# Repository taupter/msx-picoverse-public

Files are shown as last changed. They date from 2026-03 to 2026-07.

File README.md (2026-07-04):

# PicoVerse for MSX

**The MSX experience driven by the Raspberry Pi Pico family of microcontrollers.**

PicoVerse is a community-driven effort to build versatile MSX cartridges powered by Raspberry Pi Pico development boards. The project pairs accessible hardware designs with ready-to-flash firmware so MSX users can jump straight into loading games, tools, and Nextor without having to compile sources.

| Cartridge Label - 2040 Variant | Cartridge Label - 2350 Variant |
|---|---|
|PicoVerse 2040 Label | PicoVerse 2350 Label |

PicoVerse is designed as an open-source, independent, and documented MSX cartridge platform. Compatibility with other projects is neither a goal nor guaranteed (I tested some without much success); running third‑party software on PicoVerse hardware, or PicoVerse firmware on other boards, is at your own risk. The source and manufacturing files are openly available so you can learn, experiment, and build on them for the MSX community, subject to the project license.

If you find any issues, have questions, or want to contribute, please open an issue or reach out via the contact information in the repository.

## Project Highlights

- Single-ROM LoadROM workflow for instant and easy booting of one title.
- Multi-ROM loader with an on-screen menu and mapper auto-detection.
- Explorer firmware (PicoVerse 2350) merges flash ROMs, optional embedded Sunrise Nextor SYSTEM entries, and microSD ROMs, labels the source (FL/SD), adds microSD MP3/WAV playback, supports WAVEGAME microSD ROMs with port `0x92` controlled WAV streaming, supports on-device search, can cycle supported microSD partitions with `P`, can delete selected SD files with confirmed `D`, includes ROM detail audio profiles with native and external SCC/SCC+, Dual PSG, MSX-MUSIC, and YM2151/SFG support, adds an independent primary PSG DAC mirror option, and includes an integrated File Hunter browser for downloading ROMs over ESP-01 WiFi.
- Ready-made Nextor builds with USB pendrive (`-s2`/`-m2`) or FAT16 up-to-4GB microSD partitions (`-s1`/`-m1`) via Sunrise IDE emulation on PicoVerse 2350, and USB (`-s`/`-m`) on PicoVerse 2040.
- Sunrise IDE + 192KB memory mapper on PicoVerse 2040 (`loadrom.exe -m`), or Sunrise IDE standalone (`loadrom.exe -s`).
- Sunrise IDE + 1MB PSRAM memory mapper on PicoVerse 2350 (`loadrom.exe -m1` for microSD, `loadrom.exe -m2` for USB), or Sunrise IDE standalone (`loadrom.exe -s1` / `loadrom.exe -s2`).
- Sunrise IDE + 1MB memory mapper + 1MB MegaRAM on PicoVerse 2350 (`loadrom.exe -r1` / `explorer.exe -r1` for microSD, `loadrom.exe -r2` / `explorer.exe -r2` for USB), exposing 128 × 8KB MegaRAM banks in a dedicated expanded subslot.
- Carnivore2-compatible RAM-mode loader on PicoVerse 2350 (`loadrom.exe -c1` / `loadrom.exe -c2`) for `SROM.COM /D15` uploads into the 1MB PSRAM mapper.
- ESP-01 WiFi support for PicoVerse 2350 Sunrise IDE LoadROM/MultiROM builds (`loadrom.exe -s1 -w`, `-m1 -w`, `-s2 -w`, `-m2 -w`) and for the Explorer File Hunter browser. Compatible with both real MSX hardware and FPGA-based MSX cores.
- SCC/SCC+, Dual PSG, MSX-MUSIC/YM2413, and YM2151/SFG emulation on the PicoVerse 2350, with per-ROM audio profile selection where supported.
- Yamanooto flash-cartridge emulation on the PicoVerse 2350 (`yamanooto.exe`) — a Konami-SCC compatible 8 MB flash cartridge with SCC/SCC+, a secondary (dual) PSG, a primary PSG mirror, and MSX-MUSIC/FM-PAC, all always available with the firmware selecting SCC, FM, or pure PSG on the fly so one image can mix SCC, FM, and PSG games.
- PC-side tooling that generates UF2 images locally for quick drag-and-drop flashing.
- USB keyboard support on PicoVerse 2040 — use a standard USB keyboard as the MSX keyboard via the cartridge slot.
- MSX-MIDI support on PicoVerse 2040 — use a USB-MIDI cable as a standard MSX-MIDI interface via the cartridge slot. 
- MIDI-PAC support on PicoVerse 2040 — passively convert live MSX PSG music and effects into high-quality MIDI for external synths or sound modules (SC-55 optimized). Features automatic bass detection, tone+noise coexistence, smooth pitch bending on fast passages, and improved percussion mapping. 
- USB joystick support on PicoVerse 2040 — plug a standard USB gamepad (HID, Xbox 360, Xbox One, or Xbox Series X|S) into the USB-C port and it appears as one or two native MSX joysticks with no MSX-side software needed. Uses open-drain bus driving to coexist with the real PSG.
- BOMs, and production-ready Gerbers.
- Active development roadmap covering RP2040 and RP2350-based cartridges.

## Documentation

**LoadROM Guides:** Use the LoadROM tool to create a UF2 image that boots directly into a single ROM, skipping the menu. Mapper type is auto-detected with filename tag overrides, and the tool reports the detected configuration before flashing.
- [MSX PicoVerse 2040 LoadROM Tool Manual (English)](/docs/msx-picoverse-2040-loadrom-tool-manual.en-us.md) 
- [MSX PicoVerse 2350 LoadROM Tool Manual (English)](/docs/msx-picoverse-2350-loadrom-tool-manual.en-us.md) 
  
**MultiROM Guides:** Use the MultiROM tool to create a UF2 image that allows selecting from multiple ROMs at boot. Mapper type is auto-detected with filename tag overrides, and the tool reports the detected configuration before flashing.
- [PicoVerse 2040 MultiROM Guide Manual (English)](/docs/msx-picoverse-2040-multirom-tool-manual.en-us.md)
- [PicoVerse 2350 MultiROM Tool Manual (English)](/docs/msx-picoverse-2350-multirom-tool-manual.en-us.md)

**Explorer Guides:** Use the Explorer tool to manage flash, embedded Sunrise Nextor, and microSD ROMs, cycle supported microSD partitions, delete selected SD files, play MP3/WAV files from the microSD card, browse File Hunter over ESP-01 WiFi, select ROM audio/PSG options, and search for titles on the device.
- [MSX PicoVerse 2350 Explorer Tool Manual (English)](/docs/msx-picoverse-2350-explorer-tool-manual.en-us.md)

**Yamanooto Guides:** Use the Yamanooto tool to create a UF2 that emulates a Yamanooto flash cartridge (Konami-SCC compatible, SCC/SCC+, dual PSG, primary PSG mirror, and MSX-MUSIC/FM-PAC) from a single ROM image, with the firmware choosing SCC/FM/PSG automatically at runtime.
- [MSX PicoVerse 2350 Yamanooto Tool Manual (English)](/docs/msx-picoverse-2350-yamanooto-tool-manual.en-us.md)

**Reference Material** 
- [PicoVerse 2040 Features Overview](/docs/msx-picoverse-2040-features.md)
- [PicoVerse 2350 Features Overview](/docs/msx-picoverse-2350-features.md)
- [MSX PicoVerse 2350 Dual PSG Implementation](/docs/msx-picoverse-2350-dualpsg.md)
- [MSX PicoVerse 2350 MSX-MUSIC/FM-PAC Implementation](/docs/msx-picoverse-2350-fmpac.md)
- [MSX PicoVerse 2350 Yamanooto Implementation](/docs/msx-picoverse-2350-yamanooto.md)
- [MSX PicoVerse 2350 MegaRAM Implementation](/docs/msx-picoverse-2350-megaram.md)
- [MSX PicoVerse 2350 WAVEGAME Protocol and Support](/docs/msx-picoverse-2350-wavegame.md)
- [MSX PicoVerse 2350 WiFi Support](/docs/msx-picoverse-2350-wifi.md)
- [MSX PicoVerse 2040 PIO Strategy](/docs/msx-picoverse-2040-pio.md) 
- [MSX PicoVerse 2350 PIO Strategy](/docs/msx-picoverse-2350-pio.md) 
- [MSX PicoVerse 2350 SCC Emulation](/docs/msx-picoverse-2350-scc.md)
- [MSX PicoVerse 2040 Sunrise IDE Emulation for Nextor](/docs/msx-picoverse-2040-sunrise-nextor.md) 
- [MSX PicoVerse 2350 Sunrise IDE Emulation for Nextor](/docs/msx-picoverse-2350-sunrise-nextor.md) 
- [MSX PicoVerse 2040 Mapper Implementation (Sunrise + Nextor)](/docs/msx-picoverse-2040-mapper.md) 
- [MSX PicoVerse 2040 USB Keyboard](/docs/msx-picoverse-2040-keyboard.md)
- [MSX PicoVerse 2040 MSX-MIDI](/docs/msx-picoverse-2040-msx-midi.md) 
- [MSX PicoVerse 2040 MIDI-PAC](/docs/msx-picoverse-2040-midipac.md)
- [MSX PicoVerse 2040 MegaROMs](/docs/msx-picoverse-2040-megaroms.md)
- [MSX PicoVerse 2040 USB Joystick](/docs/msx-picoverse-2040-joystick.md)

## Hardware Variants

### PicoVerse 2040 Cartridge

| Prototype PCB (front) | Prototype PCB (back) |
|---|---|
|  |  | 

- Based on RP2040 boards exposing 30 GPIO pins (not compatible with stock Raspberry Pi Pico pinout).
- Up to 16 MB of flash for MSX ROMs with support for Plain16/32 (`PLA-16`/`PLA-32`), Planar48/64 (`PLN-48`/`PLN-64`), Konami SCC, Konami, ASCII8/16/16X, NEO-8, NEO-16, and Manbow2 (`MANBW2`) mappers.
- USB-C port doubles as a bridge for Nextor mass storage via Sunrise IDE emulation (`loadrom.exe -s`).
- Sunrise IDE + 192KB memory mapper mode provides both Nextor disk access and expanded RAM (`loadrom.exe -m`).
- Standalone USB keyboard firmware — use a standard USB keyboard as the MSX keyboard via the cartridge slot (`loadrom.exe -k`). Not compatible with FPGA-based MSX systems or MSX computers with an integrated PPI (e.g. T9769 MSX-ENGINE).
- Standalone MSX-MIDI firmware — use a USB-MIDI cable as a standard MSX-MIDI interface for MIDI players and sequencers (`loadrom.exe -i`).
- Standalone MIDI-PAC firmware — passively listen to the MSX PSG and convert music and effects to USB MIDI for an external synth or sound module (`loadrom.exe -p`).
- Standalone USB joystick firmware — use a standard USB gamepad as an MSX joystick via the cartridge slot (`loadrom.exe -j`). Supports Xbox 360, Xbox One, Xbox Series X|S, and generic USB HID gamepads, with up to 2 gamepads mapped to MSX joystick ports 1 and 2.  Not compatible with FPGA-based MSX systems or MSX computers with an integrated PSG (e.g. T9769 MSX-ENGINE).

#### Bill of Materials

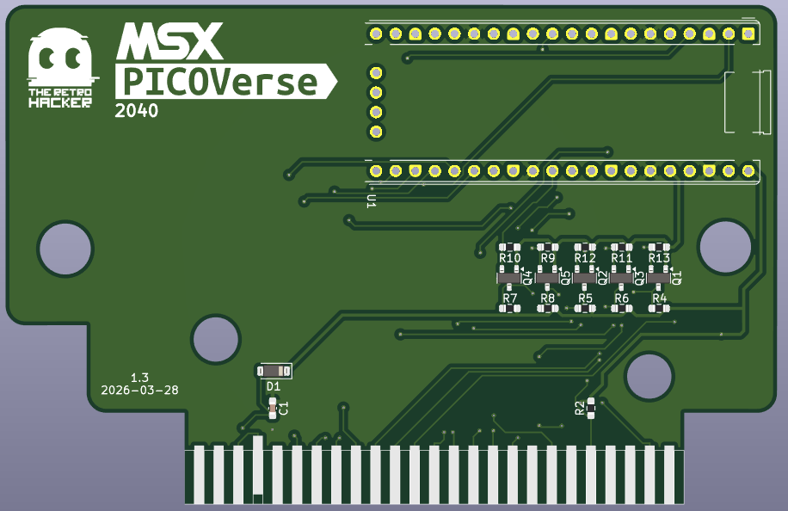
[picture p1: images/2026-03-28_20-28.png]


Interactive BOM available at [PicoVerse 2040 BOM](https://htmlpreview.github.io/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)

| Reference | Description | Quantity | Link |
| --- | --- | --- | --- |
| U1 | RP2040 Dev Board 30 GPIO pins exposed | 1 | [AliExpress](https://s.click.aliexpress.com/e/_c4MuM9st) |
| C1 | 0603 0.1 µF Ceramic Capacitor | 1 | [AliExpress](https://s.click.aliexpress.com/e/_c2w5e36V) |
| C2 | 0603 10 µF Ceramic Capacitor | 1 | [AliExpress](https://s.click.aliexpress.com/e/_c2w5e36V)|
| R2, R3, R4, R5, R6, R7, R8, R9, R10, R11, R12, R13| 0603 10 kΩ Resistor | 12 | [AliExpress](https://s.click.aliexpress.com/e/_c3XBv4od)|
| R1 | 0603 2 KΩ Resistor | 1 | [AliExpress](https://s.click.aliexpress.com/e/_c3XBv4od)|
| D1 | 1N5819 SOD-123 Diode | 1 | [AliExpress](https://s.click.aliexpress.com/e/_c4WEKCuz) |
| Q1, Q2, Q3, Q4, Q5 | BSS138 SOT-23 Transistor | 5 | [AliExpress](https://s.click.aliexpress.com/e/_c2veWxcD)|

### PicoVerse 2350 Cartridge

| Prototype PCB (front) | Prototype PCB (back) |
|---|---|
|  |  |

- Targets RP2350 boards exposing all 48 GPIO pins (not compatible with standard Pico 2 boards).
- Adds microSD storage, ESP8266 WiFi header, and I2S audio expansion alongside 16 MB flash space.
- Extra RAM (PSRAM) now backs the 1MB mapper modes and the Carnivore2-compatible RAM loader, with room for additional advanced firmware features.
- Explorer firmware can load ROMs from flash, optional embedded Sunrise Nextor SYSTEM entries, and microSD, cycle FAT16/FAT32/exFAT microSD browsing partitions with `P`, delete selected SD files after confirmation with `D`, play MP3/WAV files from microSD, browse File Hunter over ESP-01 WiFi, save downloaded File Hunter ROMs to the microSD root, search local title lists, select native or external SCC/SCC+, Dual PSG, MSX-MUSIC, or YM2151/SFG audio profiles per ROM where supported, and optionally mirror primary PSG audio through the cartridge DAC.
- USB-C port doubles as a bridge for Nextor mass storage via Sunrise IDE emulation (`-s2`).
- microSD card slot provides Nextor mass storage via Sunrise IDE emulation (`-s1`) when using FAT16 partitions up to 4 GB.
- Sunrise IDE + 1MB PSRAM memory mapper mode provides both Nextor disk access and expanded RAM (`-m1` for microSD, `-m2` for USB).
- Sunrise IDE + 1MB mapper + 1MB MegaRAM mode provides Nextor disk access, standard mapper RAM, and a separate writable MegaRAM cartridge surface (`-r1` for microSD, `-r2` for USB).
- Carnivore2-compatible RAM-mode loading lets `SROM.COM /D15` upload ROMs into the 1MB PSRAM mapper (`-c1` for microSD, `-c2` for USB).
- Yamanooto flash-cartridge emulation (`yamanooto.exe`) reproduces the  Yamanooto: a Konami-SCC compatible 8 MB flash cartridge with SCC/SCC+, a secondary (dual) PSG on ports `0x10`/`0x11`, a primary PSG mirror (`0xA0`/`0xA1`), and MSX-MUSIC/FM-PAC via an expanded subslot. All engines are always available and the firmware selects SCC, FM, or pure PSG on the fly, so a single image can hold a mix of SCC, FM, and PSG games.
- LoadROM Sunrise builds can also expose ESP-01 WiFi support with `-w` on top of the `-s1`/`-m1`/`-s2`/`-m2` modes.
- LoadROM, MultiROM, and Explorer support the Sunrise IDE options. MultiROM and Explorer allow combining them so multiple Nextor modes appear as selectable SYSTEM entries in the menu; Explorer also provides `-a` / `--allnextor` to add all embedded Nextor entries while still appending folder ROMs.
- Shares the same ROM mapper support list as the 2040 build.

#### Bill of Materials



Interactive BOM available at [PicoVerse 2350 BOM](https://htmlpreview.github.io/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) 

| Reference | Description | Quantity | Link |
| --- | --- | --- | --- |
| U1 | WaveShare Core2350B Dev Board 48 GPIO pins exposed (8Mb PSRAM)| 1 | [AliExpress](https://pt.aliexpress.com/item/1005009578742534.html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) |
|U2| UDA1334A I2S Stereo DAC| 1 | [AliExpress](https://s.click.aliexpress.com/e/_c3gam5lH) |
|U3| ESP-01 ESP8266 WiFi Module| 1 | [AliExpress](https://s.click.aliexpress.com/e/_c4a5rnGj) |
|C1| 0603 0.1 µF Ceramic Capacitor | 1 | [AliExpress](https://s.click.aliexpress.com/e/_c3tkUxHz) |
|C2,C3| 0603 10 µF Ceramic Capacitor | 2 | [AliExpress](https://s.click.aliexpress.com/e/_c3tkUxHz)|
|R1| 0603 2 KΩ Resistor | 1 | [AliExpress](https://s.click.aliexpress.com/e/_c43uKcEj)|
|R2, R3, R6, R7, R8| 0603 10 kΩ Resistor | 4 | [AliExpress](https://s.click.aliexpress.com/e/_c43uKcEj)|
|R4, R5| 0603 5.1 kΩ Resistor | 2 | [AliExpress](https://s.click.aliexpress.com/e/_c43uKcEj)|
|R9, R10| 0603 330 Ω Resistor | 2 | [AliExpress](https://s.click.aliexpress.com/e/_c43uKcEj)|
|D1| 1N5819 SOD-123 Diode | 1 | [AliExpress](https://s.click.aliexpress.com/e/_c4WEKCuz) |
|SW1| Tactile Push Button Switch | 1 | [AliExpress](https://s.click.aliexpress.com/e/_c2IPGkzv) |
|J1| USB-C 16 Pin Connector | 1 | [AliExpress](https://s.click.aliexpress.com/e/_c4PtBc51) |
|J2| microSD Card Slot | 1 | [AliExpress](https://s.click.aliexpress.com/e/_c4Pzbd7Z) |

## Repository Contents
- `hardware/` – Production-ready Gerbers, fabrication notes, and BOMs for each supported dev board.
- `software/` – MultiROM PC utilities (`multirom.exe`) and menu ROM assets for both cartridge families.
- `docs/` – Feature lists, usage walkthroughs, and revision history for each cartridge family.
- `images/` – Board renders and build photos for quick identification.
- `labels/` – Printable Patola style cartridge label designs for both hardware variants.

## Quick Start
1. **Pick your target board**: Select the hardware revision that matches the RP2040 or RP2350 carrier you own, then grab the corresponding Gerber/BOM pack.
2. **Manufacture or assemble**: Send the Gerbers to your PCB house or build from an ordered kit. Follow the assembly notes included in each hardware bundle.
3. **Generate the UF2 image**:
   - For multiple titles, place your `.rom` files beside the MultiROM tool for your cartridge family (`2040/software/multirom.pio/tool/multirom.exe` or `2350/software/multirom.pio/tool/multirom.exe`) and run `multirom.exe` to create `multirom.uf2`.
   - For an instant boot into a single game, place the desired `.rom` next to the LoadROM tool for your cartridge family and run `loadrom.exe <file> [-o custom.uf2]` to create a dedicated UF2 that skips the menu.
   - For a combined flash + microSD menu (on PicoVerse 2350 only), use the Explorer tool (`2350/software/explorer.pio/tool/explorer.exe`) to create `explorer.uf2`. Add options such as `-s1`, `-m1`, `-r1`, `-s2`, `-m2`, `-r2`, or `-a` / `--allnextor` when you want embedded Nextor SYSTEM entries in the same Explorer menu, then copy extra `.rom` and `.mp3` files to the microSD card. With an ESP-01 module and configured WiFi, Explorer can also browse File Hunter and save downloaded ROMs directly to the microSD root.
4. **Flash the firmware**:
   - Hold BOOTSEL while connecting the cartridge to your PC via USB-C.
   - Copy the freshly generated UF2 (`multirom.uf2`, `loadrom.uf2`, or `explorer.uf2`) to the RPI-RP2 drive that appears.
   - Eject the drive; the board reboots and stores the image in flash.
5. **Enjoy on MSX**: Insert the cartridge, power on the computer, pick a ROM from the menu, or launch Nextor to access USB or microSD storage.

## MultiROM Menu

| PicoVerse 2040 MultiRom | PicoVerse 2350 MultiRom |
|---|---|
|PicoVerse 2040 MultiROM menu|PicoVerse 2350 MultiROM menu|

To use the MultiROM menu, insert the PicoVerse cartridge into your MSX and power it on. The system will boot directly into the MultiROM menu, which displays a list of all ROMs embedded in the cartridge. Each entry is named after the ROM filename (up to 50 characters), and longer names are shown using a scrolling effect.

Navigate the menu using the keyboard arrow keys. Use the Up and Down keys to move through the list of ROMs, and if more than 19 ROMs are present, use the Left and Right keys to switch between pages. To start a game or application, select it and press Enter or Space; the MSX will boot the ROM using the appropriate mapper configuration automatically.

While in the menu, pressing the H key opens a help screen with basic instructions; press any key to return to the main menu. Once a ROM is launched, control is handed over entirely to the selected software, just as if it were a physical cartridge inserted into the MSX.

Check the detailed MultiROM guide in the documentation folder for advanced features, troubleshooting tips, and mapper support details.

## LoadROM Tool

The LoadROM tool targets situations where you want the PicoVerse to behave like a traditional single-game cartridge or as a dedicated standalone firmware image. Instead of showing the MultiROM menu, the Pico boots straight into one ROM embedded in the UF2 image, or into a selected standalone mode such as keyboard, MSX-MIDI, MIDI-PAC, or USB joystick.

- **Input**: exactly one `.ROM` file. Mapper type is auto-detected with the same heuristics as MultiROM, and you can still force a mapper via filename tags such as `.KonSCC.ROM` or `.PLA-32.ROM`.
- **Output**: `loadrom.uf2` by default, or any filename you pass via `-o`. The UF2 contains the firmware, a 59-byte configuration record (title, mapper, size, flash offset), and the ROM payload.
- **Workflow**:
   1. Open a Command Prompt or PowerShell window in your target package folder:
      - `2040/software/loadrom.pio/tool`, or
      - `2350/software/loadrom.pio/tool`.
   2. Run `loadrom.exe -o mygame.uf2 \\path\\to\\Game.ROM` (the tool also accepts drag-and-drop onto the EXE).
      - MSX-MIDI standalone mode: `loadrom.exe -i -o midi.uf2`
      - MIDI-PAC standalone mode: `loadrom.exe -p -o midipac.uf2`
      - USB joystick standalone mode: `loadrom.exe -j -o joystick.uf2`
      - SCC standard emulation (only PicoVerse 2350): `loadrom.exe -scc \\path\\to\\Game.ROM`
      - SCC+ enhanced emulation (only PicoVerse 2350): `loadrom.exe -sccplus \\path\\to\\Game.ROM`
      - MSX-MUSIC/FM-PAC emulation with the bundled English FM-PAC BIOS (only PicoVerse 2350, non-SYSTEM ROMs): `loadrom.exe -f \\path\\to\\Game.ROM`, `loadrom.exe -fmpac \\path\\to\\Game.ROM`, or `loadrom.exe --fmpac -o mygame-fmpac.uf2 \\path\\to\\Game.ROM`
      - Dual PSG emulation on secondary PSG ports `0x10`/`0x11` (only PicoVerse 2350, supported non-SYSTEM ROMs): `loadrom.exe -d \\path\\to\\Game.ROM` or `loadrom.exe --dual-psg -o mygame-dualpsg.uf2 \\path\\to\\Game.ROM`
      - `-scc` and `-sccplus` are mutually exclusive.
      - `-scc`, `-sccplus`, `-f` / `-fmpac`, and `-d` / `--dual-psg` are cartridge audio modes; use only one of them per UF2.
      - `-f` / `-fmpac` is not valid with Sunrise, Carnivore2, or MegaRAM system modes (`-s1`, `-m1`, `-s2`, `-m2`, `-c1`, `-c2`, `-r1`, or `-r2`) or with Konami SCC / Manbow2 mapper ROMs.
      - `-d` / `--dual-psg` is intended for software that writes to a second PSG. It is not available for Konami SCC or Manbow2 mapper ROMs, SCC/SCC+ audio builds, Sunrise/Nextor system modes, Carnivore2 system modes, or MegaRAM system modes.
      - Sunrise IDE standalone (PicoVerse 2040): `loadrom.exe -s`
      - Sunrise IDE + 192KB mapper (PicoVerse 2040): `loadrom.exe -m`
      - Sunrise IDE standalone (PicoVerse 2350): `loadrom.exe -s1` or `loadrom.exe -s2`
      - Sunrise IDE + 1MB PSRAM mapper (PicoVerse 2350): `loadrom.exe -m1` or `loadrom.exe -m2`
      - Sunrise IDE + 1MB PSRAM mapper + 1MB MegaRAM (PicoVerse 2350): `loadrom.exe -r1` or `loadrom.exe -r2`
      - Sunrise IDE + WiFi (PicoVerse 2350): `loadrom.exe -s1 -w`, `loadrom.exe -s2 -w`, `loadrom.exe -m1 -w`, or `loadrom.exe -m2 -w`
      - Carnivore2-compatible RAM loader (PicoVerse 2350): `loadrom.exe -c1` or `loadrom.exe -c2`
      - `-w` is currently supported only with `-s1`, `-m1`, `-s2`, or `-m2`.
   3. Observe the reported ROM name, size, mapper status (auto vs forced), and Pico offset before the UF2 is written.
   4. Put the Pico into BOOTSEL mode and copy the generated UF2 to the `RPI-RP2` drive.
   5. Insert the cartridge into your MSX—on power-up the embedded game launches immediately.

Consult the LoadROM manuals linked above for screenshots, troubleshooting, and in-depth explanations of mapper forcing, UF2 structure, and limitations.

## Explorer Firmware (RP2350)

|Explorer Flash Menu|Explorer MicroSD Menu|
|---|---|
|Explorer flash menu|Explorer microSD menu|
|<center>**File Hunter Explorer Menu**|<center>**WiFi Configuration Screen**|
|File Hunter Explorer menu|WiFi configuration screen|

Explorer is a PicoVerse 2350-only firmware that merges ROMs stored in flash, optional embedded Sunrise Nextor SYSTEM entries, and additional ROMs and MP3/WAV files on the microSD card. ROMs are labeled with source tags (FL/SD), MP3 and WAV entries open a player screen with Play/Stop and Pause/Resume controls, the list supports paging, and you can search by name directly in the menu. Explorer can add individual Nextor entries with `-s1`, `-m1`, `-c1`, `-r1`, `-s2`, `-m2`, `-c2`, or `-r2`, or add all of them with `-a` / `--allnextor`, while still appending supported folder ROMs to the UF2. In the `F2` microSD screen, `P` cycles supported FAT16, FAT32, and exFAT browsing partitions, while `D` deletes the selected file after confirmation; folders are protected. With an ESP-01 / ESP8266 module installed and WiFi configured, pressing `F3` opens the integrated File Hunter browser. File Hunter results show the ROM name and size, can be searched from the MSX, and selected ROMs are downloaded through the Pico into PSRAM before being saved as `.ROM` files in the microSD root. microSD ROMs up to 4 MB can be executed directly from there. Use the Explorer tool to build the UF2 and copy extra ROMs and audio files to the microSD card. See the Explorer manual for limits, File Hunter requirements, and supported formats.

For Sunrise Nextor SYSTEM entries in Explorer, SD storage is limited to FAT16 microSD partitions up to 4 GB. If more than one compatible partition exists, choose the desired one from the ROM detail screen's `SD Part` option; Explorer saves that selection in the ROM's `.PVC` options file. FAT32 and exFAT partitions remain supported for normal Explorer file browsing but are not offered to Nextor.

You can have up to 1024 entries per folder view (folders + ROMs + MP3s; the root view can also include flash entries). The menu auto-detects whether the MSX supports 80-column text mode and boots accordingly; you can also press `C` at any time to toggle between 40- and 80-column layouts.

Explorer ROM entries open a detail screen where you can inspect mapper detection, choose a cartridge audio profile, and toggle **PSG** mirroring. Konami SCC and Manbow2 ROMs can use SCC/SCC+ profiles. For other supported non-SYSTEM ROMs, select **Dual PSG** to enable the second cartridge-side PSG on ports `0x10` and `0x11`, **MSX-MUSIC** to enable YM2413/FM-PAC audio, external **SCC/SCC+** to expose a virtual SCC cartridge in another subslot, or **YM2151 (SFG05/SFG01)** to expose a virtual Yamaha SFG-style YM2151 cartridge in a secondary subslot while the game mapper remains active. Supported Sunrise Nextor SYSTEM entries can also select external **SCC/SCC+** or **YM2151 (SFG05/SFG01)**; Explorer keeps Nextor storage and mapper RAM availability intact and places the added cartridge surface in a free expanded subslot. MegaRAM Nextor entries reserve their expanded layout for Nextor, mapper RAM, and MegaRAM, so PSG Mirror, MSX-MUSIC, WiFi, and external audio profiles are not offered for those entries. Set **PSG: Yes** to also mirror the normal primary PSG ports `0xA0`/`0xA1` through the cartridge DAC; this primary PSG mirror can be mixed with SCC/SCC+, Dual PSG, MSX-MUSIC, YM2151/SFG, or WAVEGAME WAV playback. When **Dual PSG** and **PSG: Yes** are enabled together, Explorer routes Dual PSG to the left channel and the mirrored primary PSG to the right channel. Explorer hides cartridge audio profiles where the cartridge audio slot is reserved, including folders and File Hunter folder records.

WAVEGAME support is available for microSD-launched game ROMs that keep their audio sidecars in the same folder. The running MSX game writes one-byte commands to I/O port `0x92`; Explorer captures those writes while serving the ROM and streams `NN.wav`, `multi.wav`, or `pause.wav` files from the microSD card through the I2S DAC. The protocol supports stop/fade-out, play once, loop, pause toggle, pause music, previous-song resume with fade-in, deferred next-command playback, optional per-song `.cfg` sample offsets, and `multi.wav` fallback offsets. WAVEGAME titles should use 48 kHz mono 16-bit PCM WAV files. When Explorer detects WAVEGAME sidecars next to a ROM, cartridge audio profiles are forced to `None` because they are incompatible with the WAVEGAME streaming path; the separate **PSG Mirror** option remains available and is mixed into the WAVEGAME WAV output.

A search function is available by pressing `/` in the menu. Type part of a ROM name and press Enter to jump to the first matching entry. Press `H` to view the help screen.

The File Hunter browser was implemented with reference to NataliaPC's public MSX File Hunter Browser project: https://github.com/nataliapc/msx_filehunterbrowser

## Compatibility & Requirements

- Works with MSX, MSX2, MSX2+, and MSX TurboR systems. Mapper support covers the most common game and utility formats.
- Requires Windows OS to run the PC-side UF2 builder utilities.
- Ensure your development board matches the pinout documented for each hardware revision before soldering.

## License, Copyright notes & Usage

Creative Commons Attribution-NonCommercial-ShareAlike 4.0

All hardware and firmware binaries in this repository are released under the Creative Commons Attribution-NonCommercial-ShareAlike 4.0 International license. Personal builds and community tinkering are encouraged, but **commercial use or resale requires explicit authorization from the author**.

**bios.h** is used on all MSX menus and was adapted from http://www.konamiman.com/msx/msx2th/th-ap.txt by Danilo Angelo, 2020. The original file is licensed under CC0 1.0 Universal (public domain). The adapted bios.h file in this repository is also released under CC0 1.0 Universal, allowing for free use and modification without restrictions.

**msxromcrt0.s** is used on Nextor C implementation and was adapted by S0urceror, 2022, from the crt0.s file available in FusionC v2.0. The original crt0.s file is licensed under the MIT License. The adapted msxromcrt0.s file in this repository is also released under the MIT License, permitting free use, modification, and distribution with proper attribution.

**uf2format.h** is used in all UF2 builder tools and was adapted from the UF2 specification and reference implementation available at https://github.com/Microsoft/uf2/blob/master/uf2.h. The original uf2.h is copyright by Microsoft Corp and the file is licensed under the MIT License. The adapted uf2format.h file in this repository is also released under the MIT License, allowing for free use, modification, and distribution with proper attribution.

**emu2212.c** and **emu2212.h** used to implement SCC and SCC+ emulation are copyright by Mitsutaka Okazaki 2014 and licensed under the MIT License, allowing for free use, modification, and distribution with proper attribution. [emu2212 @ Digital Sound Antiques](https://github.com/digital-sound-antiques/emu2212)

**emu2149.c** and **emu2149.h** used to implement AY-3-8910 emulation/dual PSG feature are copyright by Mitsutaka Okazaki 2014 and licensed under the MIT License, allowing for free use, modification, and distribution with proper attribution. [emu2149 @ Digital Sound Antiques](https://github.com/digital-sound-antiques/emu2149)

**emu2413.c** and **emu2413.h** used to implement YM2413 / MSX-MUSIC emulation are copyright by Mitsutaka Okazaki 2020 and licensed under the MIT License, allowing for free use, modification, and distribution with proper attribution. [emu2413 @ Digital Sound Antiques](https://github.com/digital-sound-antiques/emu2413)

**The YM2151 / Yamaha SFG audio backend** uses the `ymfm` Yamaha FM sound cores by Aaron Giles, licensed under the BSD 3-Clause License. PicoVerse vendors the OPM/YM2151 subset under `2350/software/explorer.pio/pico/explorer/ymfm/` and wraps it with `emu2151.cpp` / `emu2151.h` so the Explorer SFG register implementation can use the same internal `OPM_*` API. [ymfm](https://github.com/aaronsgiles/ymfm)

**The Yamaha SFG01/SFG05 cartridge** behavior was implemented using public technical references including the RBSC SFG_Cartridge project and openMSX's Yamaha SFG implementation. PicoVerse exposes an SFG-like memory-mapped register window in a secondary expanded subslot, queues complete YM2151 register/value writes for the audio core. `SFG_64K.ROM` is bundled as a hidden Explorer flash payload for the YM2151/SFG profiles; the first 32K image is exposed for SFG05 and the second 32K image is exposed for SFG01. The SFG BIOS ROMs were created by Yamaha Corporation and must be treated as third-party copyrighted BIOS payloads. 

**WAVEGAME support on PicoVerse 2350 Explorer** implements the WAVEGAME idea and protocol authored by Jeroen Taverne and Mauricio Braga. PicoVerse keeps its own RP2350 Explorer implementation for ROM serving, port `0x92` command capture, WAV streaming, and optional PSG Mirror mixing. Implementation details were informed by the openMSX pull request [Add Wave Game audio cartridge support by MBilderbeek · Pull Request #2126 · openMSX/openMSX](https://github.com/openMSX/openMSX/pull/2126).

**MegaRAM support on PicoVerse 2350 LoadROM and Explorer** is a PicoVerse PSRAM-backed implementation of the MSX MegaRAM concept created by Ademir Carchano in Brazil in 1987. The implemented banking behavior follows the Cartucho II / SDMapper-compatible MegaRAM model: four 8KB windows in `0x4000`-`0xBFFF`, bank latches selected by address bits A14:A13, volatile RAM contents, and loader-controlled write enable through `IN (0x8E/0x8F)` with write disable through `OUT (0x8E/0x8F)`. The PicoVerse implementation is original firmware code and is provided as a tribute to Ademir Carchano's contribution to the MSX community.

**FMPCCMFC.BIN** is the English FM-PAC BIOS used by PicoVerse 2350 LoadROM when `-f` / `-fmpac` is selected. The FM-PAC BIOS ROM is copyrighted by Matsushita Corp.; the English translation is credited to 232, Max Iwamoto, and GDX.

**The Yamanooto flash-cartridge emulation on PicoVerse 2350** reproduces the *Yamanooto* cartridge (a Konami-SCC compatible 8 MB flash-ROM with SCC/SCC+ and a secondary PSG). The register map, mapper/offset behaviour, SCC/SCC+ activation rules, and FPGA ID handshake were implemented with reference to openMSX's Yamanooto device implementation ([Yamanooto.cc](https://github.com/openMSX/openMSX/blob/master/src/memory/Yamanooto.cc)) and public Yamanooto programming notes ([Programming the Yamanooto](https://genami.shop/blogs/news/programming-the-yamanooto)). PicoVerse's SCC/SCC+ uses **emu2212**, the dual/mirror PSG uses **emu2149**, and the added MSX-MUSIC engine uses **emu2413** (all © Mitsutaka Okazaki, MIT License). The embedded FM-PAC BIOS (`FMPCCMFC.BIN`) is credited as above. The RP2350 bus/PIO handling, the runtime SCC/FM/PSG engine selector, and the audio pipeline are original PicoVerse work licensed under CC BY-NC-SA 4.0. The physical Yamanooto cartridge is a product of the SCC Alliance; PicoVerse is an independent emulation and is not affiliated with or endorsed in any way.

**MIDI-PAC PSG-to-MIDI Conversion:**  
The MIDI-PAC firmware and its quality improvements were developed against public technical references and behavior studies. The PSG-to-MIDI mapping combines hardware-correct AY-3-8910 / YM2149 interpretation with pragmatic General MIDI reinterpretation for musical output on modules like the Roland SC-55. Key references used include:  
- The `berarma/aymidi` project by berarma (AY-3-8910 to MIDI conversion reference).  
- The `ayumi` AY/YM2149 emulator by Peter Sovietov (Peter Sovietov, 2022; used for envelope generation verification).  
- The ESEMSX3 FPGA implementation `midi.vhd` (serves as a minimal alternative PSG-to-MIDI transport reference).  
- AY-3-8910 and YM2149 datasheets and hardware behavior documentation (General Instruments and Yamaha specifications).  
- MSX-MIDI specification and USB MIDI 1.0 Event Packet format (USB Implementers Forum).  
- The Sunrise IDE specification and Nextor protocol documentation.  

**The OPL4 / YMF278B / MoonSound implementation on PicoVerse 2350 LoadROM** is an original PicoVerse standalone cartridge firmware written for the RP2350. PicoVerse implements the MSX/MoonSound host side itself: PIO bus capture for ports `0xC4`-`0xC7` and `0x7E`/`0x7F`, `/WAIT`-gated reads, `/BUSDIR` drive, register/status shadows, FM timer `/INT` delivery, YRW801-M wave-ROM exposure, and 2 MB PCM sample RAM.

**YMF278B synthesis** uses Aaron Giles' `ymfm` Yamaha sound cores, licensed under the BSD 3-Clause License, including the OPL/FM and PCM support wrapped by PicoVerse's `emu278b` interface for timer, IRQ, ROM, and sample-RAM behavior. The MoonSound/WozBlaster-compatible port map, `/BUSDIR` behavior, 2 MB YRW801-M ROM plus 2 MB RAM model, and compatibility work were informed by public technical references including the Wozblaster OPL4_Cartridge project and openMSX's OPL4 implementation. The bundled `YRW801-M` instrument ROM is a Yamaha 1993 third-party ROM payload and must be treated as copyrighted material. PicoVerse's bus firmware, cartridge integration, synchronization model, and RP2350 audio pipeline are original PicoVerse work and are licensed under CC BY-NC-SA 4.0, allowing for non-commercial use and modification with proper attribution; commercial use or resale requires explicit authorization from the author.

**MSX-MIDI Interface:**  
The MSX-MIDI firmware was developed using the MSX-MIDI specification, USB MIDI 1.0 specification, TinyUSB host API, and reference behavior from ESEMSX3 and similar implementations. The 8251 USART emulation and standard MIDI wire protocol handling are original PicoVerse implementations.

**The Sunrise IDE driver for Nextor** used on PicoVerse is copyright by Konamiman, Piter Punk, and FRS, and is licensed under the special terms by MSX Licensing Corporation. The original Sunrise IDE code is available at https://github.com/Konamiman/Nextor/blob/v2.1/source/kernel/drivers/SunriseIDE/sunride.asm

The algorithm to emulate ATA devices is original and based on the implementation for the Carnivore2 cartridge, Copyright (c) 2017-2024 by the RBSC group. Portions (c) Mitsutaka Okazaki and (c) Kazuhiro Tsujikawa. Available at https://github.com/RBSC/Carnivore2/tree/master/Firmware/Sources

**WiFi support on PicoVerse 2350** was implemented with direct reference to the ESP8266 / MSX WiFi work by Oduvaldo Pavan Junior (`ducasp`). The PicoVerse WiFi ROM integration, memio register layout, fixed-`859372` UART behavior, FIFO clear command handling, quick-receive behavior, and ESP-side protocol compatibility were based on public source and documentation from Oduvaldo's projects. Important references used include:
- `MSXPICO/UNAPI_BIOS_CUSTOM_ESP_MSXPICO/ESP8266_memio.asm` from `ducasp/MSX-Development` for the memory-mapped ROM and register model.
- `MSX-SM/WiFi/UNAPI_BIOS_CUSTOM_ESP_FIRMWARE` and related WiFi utilities from `ducasp/MSX-Development` for the ROM/driver lineage and behavior.
- `ducasp/ESP8266-UNAPI-Firmware` and its documentation for the serial protocol, command/response structure, and ESP firmware behavior.

Those projects remain copyright by Oduvaldo Pavan Junior and their respective contributors under their original terms. PicoVerse reuses the public technical design references and keeps its own RP2350 cartridge-side implementation.

**File Hunter browser integration on PicoVerse 2350 Explorer** was implemented with reference to NataliaPC's MSX File Hunter Browser project and the public File Hunter service behavior. PicoVerse keeps its own Explorer MSX menu and RP2350/ESP8266 transport implementation, while acknowledging the original MSX File Hunter Browser code and workflow by NataliaPC. Reference repository: https://github.com/nataliapc/msx_filehunterbrowser

**Mapper detection heuristics and filename tag forcing schemes** in the LoadROM and MultiROM tools are original implementations by the OpenMSX developers for the Romfactory module and licensed under the GNU Public License (GPL). Available at https://github.com/openMSX/openMSX/blob/6f8aa9865eeccdb0b31043d8851b822538440204/src/memory/RomFactory.cc

**The softwaredb database** used for ROM mapper detection is built upon contributions from across the MSX community, including the initial work by Nicolas Beyaert, later expanded by the BlueMSX Team (2004–2013) and continuously maintained by the openMSX Team (2005–present). It also incorporates MSX ID data generated by Generation MSX (www.generation-msx.nl). Special thanks go to the Generation MSX / Sylvester project for its extensive reference data, as well as to contributors such as p_gimeno and diedel for ROM additions and validation, and GDX for further ROM information, corrections, and verification efforts. Part of OpenMSX effort. Available at https://github.com/openMSX

## Feedback & Community

Questions, test reports, and build photos are welcome. Open an issue on the public repository or reach out through the MSX retro hardware forums where PicoVerse updates are posted.

Author: Cristiano Goncalves
Last updated: 06/07/2026

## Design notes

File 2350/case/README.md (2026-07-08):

# PicoVerse 2350 Case Files

This folder contains the 3D model files for the PicoVerse 2350 cartridge case.

## Files

- `Cartouche_MSX_V2_FLAT_PICOVERSE_2350_1.0_A.obj` - case shell part A for the PicoVerse 2350 case version 1.0.
- `Cartouche_MSX_V2_FLAT_PICOVERSE_2350_1.0_B.obj` - case shell part B for the PicoVerse 2350 case version 1.0.
- `PicoVerse_2350_button.stl` - printable button part for the PicoVerse 2350 1.1/1.2 case.
- `PicoVerse_2350_1.1_Paco_boton_4mm.stl` - printable button part for the PicoVerse 2350 1.1 case.
- `PicoVerse_2350_1.1_Paco_bottom.stl` - printable bottom part for the PicoVerse 2350 1.1 case.
- `PicoVerse_2350_1.1_Paco_top.stl` - printable top part for the PicoVerse 2350 1.1 case.

## Credits

The version 1.0 OBJ case shell files (`Cartouche_MSX_V2_FLAT_PICOVERSE_2350_1.0_A.obj` and `Cartouche_MSX_V2_FLAT_PICOVERSE_2350_1.0_B.obj`) are copyright by Ludovic Avot.

The version 1.1 STL case files (`PicoVerse_2350_1.1_Paco_boton_4mm.stl`, `PicoVerse_2350_1.1_Paco_bottom.stl`, and `PicoVerse_2350_1.1_Paco_top.stl`) are copyright by Paco Baron.

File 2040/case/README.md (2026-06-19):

# PicoVerse 2040 Case Files

This folder contains 3D model and drawing files for the PicoVerse 2040 cartridge case.

## Files

- `PicoVerse_2040_1.41_bootsel_hole.svg` - SVG drawing for the PicoVerse 2040 version 1.41 BOOTSEL access hole.
- `PicoVerse_2040_1.41_button.stl` - printable button part for the PicoVerse 2040 case version 1.41.
- `PicoVerse_2040_1.41_label_holder.stl` - printable label holder part for the PicoVerse 2040 case version 1.41.
- `PicoVerse_2040_button_pakoto.stl` - printable button part from the Pakoto case set.
- `PicoVerse_2040_side1_pakoto.stl` - printable case shell side 1 from the Pakoto case set.
- `PicoVerse_2040_side2_pakoto.stl` - printable case shell side 2 from the Pakoto case set.

## Credits

The Pakoto case STL files (`PicoVerse_2040_button_pakoto.stl`, `PicoVerse_2040_side1_pakoto.stl`, and `PicoVerse_2040_side2_pakoto.stl`) are credited to Paco Baron.

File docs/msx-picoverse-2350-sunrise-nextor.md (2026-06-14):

# MSX PicoVerse 2350 — Sunrise IDE Emulation for Nextor

This document describes the implementation of the Sunrise IDE interface emulation modes in the MSX PicoVerse 2350 firmware. The 2350 variant supports two distinct storage backends — microSD card and USB mass storage — each available standalone, combined with a 1MB PSRAM-backed memory mapper, or combined with that mapper plus Carnivore2-compatible RAM-mode loading for `SROM.COM /D15`. The four non-Carnivore2 Sunrise modes can also optionally expose ESP-01 WiFi support when built with `-w` in either `loadrom.exe` or `multirom.exe`, or when enabled from the Explorer ROM details screen.

## 1. Overview

The MSX PicoVerse 2350 provides a complete Sunrise IDE emulation that allows the MSX to boot Nextor DOS and access mass storage through either the on-board microSD card slot or the USB-C port. Six firmware modes are available:

| Option | Mapper Type | Storage Backend | Description |
|---|---|---|---|
| `-s1` / `--sunrise-sd` | 15 | microSD (SPI) | Sunrise IDE with microSD card |
| `-m1` / `--mapper-sd` | 16 | microSD (SPI) | Sunrise IDE + 1MB PSRAM mapper with microSD card |
| `-c1` / `--carnivore2-sd` | 17 | microSD (SPI) | Sunrise IDE + 1MB PSRAM mapper + Carnivore2 RAM-mode target for `SROM.COM /D15` |
| `-s2` / `--sunrise-usb` | 10 | USB-C (MSC) | Sunrise IDE with USB pendrive |
| `-m2` / `--mapper-usb` | 11 | USB-C (MSC) | Sunrise IDE + 1MB PSRAM mapper with USB pendrive |
| `-c2` / `--carnivore2-usb` | 18 | USB-C (MSC) | Sunrise IDE + 1MB PSRAM mapper + Carnivore2 RAM-mode target for `SROM.COM /D15` |

All six modes:

- Emulate the Sunrise IDE FlashROM banking for the 128KB Nextor ROM image (8 × 16KB pages)
- Emulate the full ATA task-file register set at `0x7C00`–`0x7EFF`
- Translate ATA sector read/write commands into block I/O operations on the chosen storage device
- Run the Nextor 2.1.4 Sunrise IDE driver (Master Only edition)
- Use the RP2350's dual-core architecture: Core 0 for PIO bus and IDE register handling, Core 1 for storage backend

The mapper variants (`-m1`, `-m2`) additionally provide 1MB of mapper RAM (64 × 16KB pages) in an expanded sub-slot architecture, with mapper page registers intercepted via PIO1.

The Carnivore2 RAM-mode variants (`-c1`, `-c2`) build on that same mapper architecture and add a Carnivore2-compatible control/register surface plus banked RAM windows so `SROM.COM /D15` can upload ROM images into PSRAM and launch them directly from RAM.

The `-w` WiFi flag is available for `-s1`, `-m1`, `-s2`, and `-m2`. It does not create new mapper IDs; instead, it sets an additional configuration flag that makes the firmware expose a WiFi subslot containing the ESP8266P system ROM and memio UART surface. See the dedicated WiFi guide for the full register-level details.

### Nextor partition requirements and Explorer selection

Nextor storage uses the Sunrise IDE block device and should be prepared with FAT16 partitions up to 4 GB for reliable MSX-DOS/Nextor access. FAT32 and exFAT partitions can be useful on the same microSD card for Explorer browsing, ROM loading, MP3/WAV playback, or File Hunter downloads, but they are not valid boot/storage partitions for Sunrise Nextor SYSTEM entries.

In Explorer, Sunrise Nextor SD SYSTEM entries scan the microSD partition table and offer only compatible FAT16 partitions up to 4 GB in the ROM detail screen. The `SD Part` option shows the filesystem volume label when available; use Left/Right to choose between compatible partitions. The selected partition is stored in that ROM's `.PVC` options file, so each Sunrise Nextor SYSTEM entry can remember its own FAT16 partition.

The normal Explorer `F2` microSD browser has different rules: it can cycle through supported FAT16, FAT32, and exFAT primary/logical partitions with `P`, saves the current browsing partition in `/PICOVERSE.PVC`, and displays the selected partition label plus free-space status. This partition selection is for Explorer file browsing and does not make FAT32/exFAT partitions valid for Nextor.

## 2. Architecture

All six modes share an identical ATA front-end on Core 0. Core 1 runs the appropriate storage backend depending on the mapper type.

### Shared ATA Front-End

The Sunrise IDE ATA emulation is implemented in `sunrise_ide.c` and provides:

- **Segment/IDE control register** at `0x4104` (write-only) — FlashROM page select with bit-reversed bank number + IDE enable bit
- **16-bit data register** at `0x7C00`–`0x7DFF` — with low/high byte latch for MSX 8-bit bus
- **ATA task-file registers** at `0x7E00`–`0x7EFF` — mirrored every 16 bytes
- **ATA commands**: IDENTIFY DEVICE (`0xEC`), READ SECTORS (`0x20`), WRITE SECTORS (`0x30`), EXECUTE DEVICE DIAGNOSTIC (`0x90`), DEVICE RESET (`0x08`), SET FEATURES (`0xEF`), INIT PARAMS (`0x91`), RECALIBRATE (`0x10`)

The front-end sets volatile request flags (`usb_read_requested`, `usb_write_requested`) that are serviced by whichever backend runs on Core 1.

### USB Backend (Types 10, 11)

`sunrise_ide.c` — `sunrise_usb_task()`:

```
┌─────────────────────────────────────────────────────┐
│  Core 1 — USB Backend                               │
│  ┌───────────────────────────────────────────────┐  │
│  │  TinyUSB host stack (Full Speed)              │  │
│  │  tuh_task() polling loop                      │  │
│  │  tuh_msc_read10() / tuh_msc_write10()         │  │
│  │  SCSI INQUIRY → vendor/product/revision       │  │
│  │  Async callbacks with timeout watchdog        │  │
│  └───────────────────────────────────────────────┘  │
└────────────────────────┬────────────────────────────┘
                         │ USB Host (Full Speed)
                  ┌──────▼──────┐
                  │   USB-C     │
                  │ Mass Storage│
                  │   Device    │
                  └─────────────┘
```

- Transfers are asynchronous via TinyUSB callbacks
- A 3-second timeout watchdog prevents stalled transfers from keeping the IDE in BSY
- Supports devices with non-512-byte native sectors by reading the native block and extracting the correct 512-byte slice
- Device info for IDENTIFY comes from the USB SCSI INQUIRY response

### microSD Backend (Types 15, 16)

`sunrise_sd.c` — `sunrise_sd_task()`:

```
┌─────────────────────────────────────────────────────┐
│  Core 1 — SD Backend                                │
│  ┌───────────────────────────────────────────────┐  │
│  │  disk_initialize() → SPI init + card detect   │  │
│  │  disk_ioctl(GET_SECTOR_COUNT)                 │  │
│  │  CID register → vendor/product/revision       │  │
│  │  disk_read() / disk_write() polling loop      │  │
│  └───────────────────────────────────────────────┘  │
└────────────────────────┬────────────────────────────┘
                         │ SPI0 @ 31.25 MHz
                  ┌──────▼──────┐
                  │   microSD   │
                  │   Card      │
                  └─────────────┘
```

- Transfers are synchronous — `disk_read()` and `disk_write()` block until complete, which simplifies the code vs. the async USB path
- All SD cards use 512-byte sectors natively; no sector-size conversion is needed
- Device info for IDENTIFY is extracted from the SD card's CID register (OEM ID, Product Name, Product Revision)
- Card initialization happens once at startup; no hot-plug support

### Combined Diagram

```
┌──────────────────────────────────────────────────────────┐
│  MSX Bus                                                 │
│  /SLTSL, /RD, /WR, A0-A15, D0-D7, /WAIT                │
└──────────────┬───────────────────────┬───────────────────┘
               │                       │
        ┌──────▼───────┐        ┌──────▼────────┐
        │  SM0 (PIO0)  │        │  SM1 (PIO0)   │
        │  Read Resp.  │        │  Write Capt.  │
        └──────┬───────┘        └──────┬────────┘
               │                       │
        ┌──────▼───────────────────────▼────────┐
        │            Core 0 (CPU)               │
        │  sunrise_ide_handle_read/write()      │
        │  Sunrise mapper page lookup           │ 
        │  PIO bus + FIFO management            │
        └──────────────────┬────────────────────┘
                           │  Shared volatile flags
                           │  (sunrise_ide_t)
             ┌─────────────┴─────────────┐
             │                           │
     ┌───────▼───────┐          ┌────────▼────────┐
     │   Core 1      │          │    Core 1       │
     │ sunrise_usb_  │    OR    │ sunrise_sd_     │
     │ task()        │          │ task()          │
     │ (Types 10,11) │          │ (Types 15,16)   │
     └───────┬───────┘          └────────┬────────┘
             │                           │
      ┌──────▼──────┐           ┌────────▼────────┐
      │   USB-C     │           │    microSD      │
      │ Pendrive    │           │    Card (SPI)   │
      └─────────────┘           └─────────────────┘
```

## 3. microSD Card Hardware

The microSD card connects to the RP2350 via SPI0:

| GPIO | Signal | SPI Function |
|---|---|---|
| 33 | CS | Chip Select (manual) |
| 34 | SCK | SPI Clock |
| 35 | MOSI | SPI Data Out |
| 36 | MISO | SPI Data In |

- **SPI peripheral**: `spi0`
- **Baud rate**: 31.25 MHz (`125 MHz / 4`)
- **Library**: Carl Kugler's `no-OS-FatFS-SD-SDIO-SPI-RPi-Pico` — provides the FatFS `diskio.h` low-level API (`disk_initialize`, `disk_read`, `disk_write`, `disk_ioctl`)

The hardware configuration is defined in `hw_config.c`, which registers a single `sd_card_t` with the SPI interface parameters. This is the same configuration used by the Explorer firmware.

## 4. SD Card Device Identification

When the SD card is initialized, the firmware reads the card's CID (Card IDentification) register to populate the ATA IDENTIFY DEVICE response with real device information. The CID is a 16-byte register embedded in every SD card containing manufacturer-programmed identification data.

### CID Fields Used

| Field | CID Bits | Size | Purpose |
|---|---|---|---|
| OEM/Application ID | [119:104] | 2 chars | ATA model prefix (vendor) |
| Product Name | [103:64] | 5 chars | ATA model name |
| Product Revision | [63:56] | 4+4 bits | ATA firmware revision ("major.minor") |

### Extraction Code

```c
sd_card_t *sd = sd_get_by_num(0);
char vendor[3] = {0};
char product[6] = {0};
char revision[5] = {0};

ext_str(16, sd->state.CID, 119, 104, sizeof(vendor), vendor);
ext_str(16, sd->state.CID, 103, 64, sizeof(product), product);
uint8_t prv_major = (uint8_t)ext_bits16(sd->state.CID, 63, 60);
uint8_t prv_minor = (uint8_t)ext_bits16(sd->state.CID, 59, 56);
snprintf(revision, sizeof(revision), "%u.%u", prv_major, prv_minor);
```

This data is passed to `sunrise_ide_set_device_info()`, which populates the shared ATA state used by `build_identify_data()`. During Nextor boot, the driver prints the model name from IDENTIFY words 27–46 and the firmware revision from words 23–26, showing the actual microSD card identity.

For USB devices, the equivalent information comes from the SCSI INQUIRY response (vendor ID, product ID, and product revision).

## 5. Inter-Core Communication

Both backends reuse the same set of volatile flags originally defined for the USB path. The flag names retain their `usb_` prefix but serve as generic IDE↔backend signals:

| Flag | Direction | Purpose |
|---|---|---|
| `usb_device_mounted` | Backend → Front-end | Storage device is ready for I/O |
| `usb_read_requested` | Front-end → Backend | ATA READ SECTORS pending |
| `usb_read_lba` | Front-end → Backend | LBA for the pending read |
| `usb_write_requested` | Front-end → Backend | ATA WRITE SECTORS pending (buffer full) |
| `usb_write_lba` | Front-end → Backend | LBA for the pending write |
| `usb_write_buffer[512]` | Front-end → Backend | Sector data to write |
| `usb_read_ready` | Backend → Front-end | Read completed successfully |
| `usb_read_failed` | Backend → Front-end | Read failed |
| `usb_write_ready` | Backend → Front-end | Write completed successfully |
| `usb_write_failed` | Backend → Front-end | Write failed |
| `usb_identify_pending` | Front-end → Backend | IDENTIFY waiting for device mount |

These flags are declared non-static in `sunrise_ide.c` and accessed via `extern` in `sunrise_sd.c`. Flag ownership is strictly unidirectional — one core sets, the other clears.

## 6. Mapper Mode (Types 11, 16)

The mapper variants (`-m1`, `-m2`) add a two-phase bootstrap and an expanded sub-slot architecture:

### Phase 1 — Bootstrap ROM

A minimal 18-byte ROM is served that:
1. Presents itself with the `AB` header so the BIOS executes the INIT routine
2. Reads `I/O port 0xF4`, ORs bit 7 (boot slot), and writes it back
3. Executes `RST 0x00` to restart the MSX

This forces the MSX to reboot with the cartridge slot marked as the boot slot, required for the expanded sub-slot mapper to be recognized by the BIOS.

### Phase 2 — Expanded Sub-Slot Architecture

After restart detection, the firmware reinitializes PIO and sets up:

| Sub-slot | Content | Address Range |
|---|---|---|
| 0 | Nextor ROM (128KB, 8 pages) + IDE registers | `0x4000`–`0x7FFF` |
| 1 | Mapper RAM (1MB, 64 pages) | All four 16KB pages |

- **Sub-slot register** (`0xFFFF`): Read returns bitwise complement; write sets sub-slot configuration
- **Mapper page registers** (I/O ports `0xFC`–`0xFF`): Intercepted by PIO1 state machines, controlling which 16KB page of mapper RAM is visible in each CPU page
- **1MB mapper RAM**: Backed by external PSRAM mapped at the uncached QMI CS1 window (`0x15000000`)
- The ROM cache is disabled (`rom_cache_capacity = 0`) because mapper RAM now lives in external PSRAM instead of the internal SRAM cache pool

### PIO1 Usage in Mapper Mode

| SM | Program | Function |
|----|---|---|
| SM0 | `msx_io_read_responder` | Returns mapper page register values for reads on ports FC–FF |
| SM1 | `msx_io_write_captor` | Captures mapper page register writes on ports FC–FF |

## 7. Optional WiFi Overlay (`-w`)

The `-w` flag augments the four standard Sunrise modes:

| Base Mode | With `-w` |
|---|---|
| `-s1` | microSD Nextor + WiFi |
| `-m1` | microSD Nextor + 1MB mapper + WiFi |
| `-s2` | USB Nextor + WiFi |
| `-m2` | USB Nextor + 1MB mapper + WiFi |

Implementation summary:

- The host tool sets bit `0x20` in the configuration record.
- The firmware keeps the original base mapper type and switches to WiFi-aware Sunrise handlers.
- A dedicated 16KB ESP8266P system ROM is exposed in its own expanded subslot.
- The memio UART interface is mapped at `0x7F05`-`0x7F07` inside that same subslot.

Subslot layout with WiFi enabled:

| Mode Family | Sub-slot 0 | Sub-slot 1 | Sub-slot 2 |
|---|---|---|---|
| `-s1 -w`, `-s2 -w` | ESP8266P ROM + memio UART | Nextor + IDE | unused |
| `-m1 -w`, `-m2 -w` | ESP8266P ROM + memio UART | Nextor + IDE | 1MB PSRAM mapper |

The ESP8266P BIOS is placed in sub-slot 0 so its `INIT` runs before Nextor's during the MSX BIOS expanded-slot scan. This ordering is required for FPGA-based MSX cores and is functionally equivalent on real MSX hardware.

The WiFi implementation is intentionally not enabled for `-c1` and `-c2` in the current firmware.

In Explorer builds the ESP8266P BIOS is stored once as a hidden fixed payload. Sunrise Nextor entries show **Wifi: No** by default on the ROM details screen; changing it to **Yes** makes the firmware expose the same WiFi subslot layout used by `-w`, then run the selected Sunrise Nextor ROM. Mapper variants keep their 1MB PSRAM mapper in subslot 2.

## 8. ATA IDENTIFY DEVICE Response

Both backends produce a 512-byte IDENTIFY DEVICE response. The key fields:

| Word(s) | Field | USB Value | SD Value |
|---|---|---|---|
| 0 | Configuration | `0x0040` (fixed) | `0x0040` (fixed) |
| 1, 3, 6 | CHS geometry | From USB block count | From SD sector count |
| 10–19 | Serial number | `"PICOVERSE00000001"` | `"PICOVERSE00000001"` |
| 23–26 | Firmware revision | USB SCSI product rev | CID Product Revision |
| 27–46 | Model number | USB SCSI vendor + product | CID OEM ID + Product Name |
| 49 | Capabilities | `0x0200` (LBA) | `0x0200` (LBA) |
| 60–61 | Total LBA sectors | USB block count | SD sector count |

The USB backend reads SCSI INQUIRY fields directly from the USB device. The SD backend reads the CID register via `ext_str()` and `ext_bits16()`. Both populate the shared ATA state via `sunrise_ide_set_device_info()`, which writes to the `usb_block_count`, `usb_block_size`, and `inquiry_resp` variables used by `build_identify_data()`.

## 9. Key Differences: USB vs. SD Backend

| Aspect | USB Backend | SD Backend |
|---|---|---|
| **Transfer model** | Asynchronous (TinyUSB callbacks) | Synchronous (blocking `disk_read`/`disk_write`) |
| **Timeout handling** | 3-second watchdog in Core 1 loop | Not needed (SPI is deterministic) |
| **Native sector size** | Variable (512, 4096, etc.) | Always 512 bytes |
| **4K sector support** | Yes — reads native block, extracts 512-byte slice | N/A |
| **Hot-plug** | Yes — `tuh_msc_mount_cb`/`umount_cb` | No — initialized once at startup |
| **Device info source** | SCSI INQUIRY response | CID register |
| **Write with non-512 sectors** | Returns error (would need read-modify-write) | Always 512-byte aligned |
| **Core 1 dependencies** | TinyUSB, `tinyusb_board`, `tinyusb_host` | `no-OS-FatFS-SD-SDIO-SPI-RPi-Pico`, `hw_config.c` |
| **Initialization time** | Variable (USB enumeration + INQUIRY) | Fast (~100ms SPI init) |
| **IDENTIFY before ready** | Defers to BSY + `usb_identify_pending` | Usually ready before first IDENTIFY |

## 10. Firmware Dispatch

The `main()` function in `loadrom.c` reads the mapper type from the configuration record and dispatches accordingly:

```c
switch (base_rom_type) {
    // ... cases 1-9 (standard mappers) ...
    case 10: wifi_enabled ? loadrom_sunrise_wifi(ROM_RECORD_SIZE, true)
                          : loadrom_sunrise(ROM_RECORD_SIZE, true);          break;
    case 11: wifi_enabled ? loadrom_sunrise_mapper_wifi(ROM_RECORD_SIZE, true)
                          : loadrom_sunrise_mapper(ROM_RECORD_SIZE, true);   break;
    // ... cases 12-14 ...
    case 15: wifi_enabled ? loadrom_sunrise_wifi_sd(ROM_RECORD_SIZE, true)
                          : loadrom_sunrise_sd(ROM_RECORD_SIZE, true);       break;
    case 16: wifi_enabled ? loadrom_sunrise_mapper_wifi_sd(ROM_RECORD_SIZE, true)
                          : loadrom_sunrise_mapper_sd(ROM_RECORD_SIZE, true); break;
}
```

The SD functions (`loadrom_sunrise_sd`, `loadrom_sunrise_mapper_sd`) are structurally identical to their USB counterparts but launch `sunrise_sd_task` on Core 1 instead of `sunrise_usb_task`, and call `sunrise_sd_set_ide_ctx()` instead of `sunrise_usb_set_ide_ctx()`.

When WiFi is enabled, the dispatch keeps the same base mapper type and swaps in the WiFi-aware Sunrise handlers instead.

## 11. LoadROM and MultiROM Tool Usage

### LoadROM command-line options

```
loadrom.exe [-h] [-s1] [-m1] [-s2] [-m2] [-c1] [-c2] [-w] [-scc] [-sccplus] [-o <filename>] [romfile]
```

| Option | Long Form | Description |
|---|---|---|
| `-s1` | `--sunrise-sd` | Sunrise IDE with microSD card |
| `-m1` | `--mapper-sd` | Sunrise IDE + 1MB PSRAM mapper with microSD card |
| `-s2` | `--sunrise-usb` | Sunrise IDE with USB pendrive |
| `-m2` | `--mapper-usb` | Sunrise IDE + 1MB PSRAM mapper with USB pendrive |
| `-c1` | `--carnivore2-sd` | Sunrise IDE + 1MB PSRAM mapper + Carnivore2 RAM-mode emulation with microSD card |
| `-c2` | `--carnivore2-usb` | Sunrise IDE + 1MB PSRAM mapper + Carnivore2 RAM-mode emulation with USB pendrive |
| `-w` | `--wifi` | Add the ESP8266P system ROM + memio UART WiFi surface to `-s1`/`-m1`/`-s2`/`-m2` |

In LoadROM the Sunrise and Carnivore2 base options are mutually exclusive. The `-w` flag is valid only with `-s1`, `-m1`, `-s2`, or `-m2`.

### MultiROM command-line options

The same `-s1` / `-m1` / `-s2` / `-m2` / `-c1` / `-c2` flags are accepted by `multirom.exe`. In MultiROM they are **not** mutually exclusive — each enabled flag adds an independent SYSTEM entry to the on-cart menu, so a single UF2 can offer several Sunrise / Carnivore2 modes side-by-side. The `-w` WiFi flag is also accepted by `multirom.exe`; it requires at least one of `-s1`/`-m1`/`-s2`/`-m2` and is applied to every selected Sunrise IDE entry. WiFi is intentionally not added to `-c1`/`-c2` Carnivore2 entries. The `-scc` / `-sccplus` flags are accepted by both tools and apply to Konami SCC / Manbow2 ROMs as well as to ROMs uploaded via SROM in the Carnivore2 modes.

### Examples

```bash
# microSD standalone
loadrom.exe -s1
loadrom.exe -s1 -o nextor_sd.uf2
loadrom.exe -s1 -w -o nextor_sd_wifi.uf2

# microSD + 1MB PSRAM mapper
loadrom.exe -m1
loadrom.exe -m1 -w -o nextor_mapper_sd_wifi.uf2

# USB standalone
loadrom.exe -s2
loadrom.exe -s2 -o nextor_usb.uf2
loadrom.exe -s2 -w -o nextor_usb_wifi.uf2

# USB + 1MB PSRAM mapper
loadrom.exe -m2
loadrom.exe -m2 -w -o nextor_mapper_usb_wifi.uf2
```

### Typical Workflow

1. Run `loadrom.exe` with the desired Nextor option.
2. Review the console output (ROM type, name, size).
3. Hold BOOTSEL on the PicoVerse 2350 and connect USB.
4. Copy the generated UF2 to the `RPI-RP2` drive.
5. For `-s1`/`-m1`: Insert a microSD card with a FAT16 partition up to 4 GB into the PicoVerse 2350 card slot.
6. For `-s2`/`-m2`: Connect a USB flash drive to the USB-C port (via OTG adapter if needed).
7. Insert the cartridge into the MSX and power on.

## 12. Build Configuration

### CMakeLists.txt

The build includes both USB and SD dependencies:

```cmake
add_subdirectory(lib/no-OS-FatFS-SD-SDIO-SPI-RPi-Pico/src build_sd_lib)

add_executable(loadrom
    ${PICO_SDK_PATH}/lib/tinyusb/src/tusb.c
    loadrom.c
    emu2212.c
    sunrise_ide.c
    sunrise_sd.c
    hw_config.c)

target_link_libraries(loadrom
    pico_stdlib
    pico_multicore
    pico_audio_i2s
    hardware_dma
    hardware_pio
    tinyusb_board
    tinyusb_host
    no-OS-FatFS-SD-SDIO-SPI-RPi-Pico)
```

Both backends are compiled into every firmware binary. The runtime dispatch in `main()` selects which backend runs based on the mapper type stored in the configuration record.

The WiFi-enabled Sunrise variants additionally use the host tool to append the ESP8266P ROM after the Sunrise ROM payload in the UF2 image, while the firmware keeps only the UART/memio backend and serves the WiFi ROM from the appended flash payload.

### Tool Makefile

The PC tool Makefile generates `nextor_sunrise.h` (the embedded ROM as a C byte array) from:

```
nextor/kernel/Nextor-2.1.4.SunriseIDE.MasterOnly.ROM → src/nextor_sunrise.h
```

This header is shared by all four Nextor modes.

## 13. Source File Reference

| File | Purpose |
|---|---|
| `pico/loadrom/sunrise_ide.h` | Sunrise IDE address map, ATA constants, IDE state machine, `sunrise_ide_t` context, public API |
| `pico/loadrom/sunrise_ide.c` | ATA command handling, data register latch, mapper bit reversal, USB host backend (`sunrise_usb_task`), IDENTIFY builder, `sunrise_ide_set_device_info()` |
| `pico/loadrom/sunrise_sd.h` | SD backend API: `sunrise_sd_set_ide_ctx()`, `sunrise_sd_task()` |
| `pico/loadrom/sunrise_sd.c` | SD card initialization, CID extraction, synchronous block I/O backend (`sunrise_sd_task`) |
| `pico/loadrom/hw_config.c` | SPI pin configuration for SD card (CS=33, SCK=34, MOSI=35, MISO=36) |
| `pico/loadrom/tusb_config.h` | TinyUSB host mode configuration for USB MSC |
| `pico/loadrom/loadrom.c` | Firmware main: Sunrise, mapper, Carnivore2, and WiFi-aware Sunrise handlers |
| `wifi/ESP8266P.rom` | ESP8266P system ROM asset used by the WiFi-enabled Sunrise builds |
| `tool/src/esp8266p_rom.h` | Generated host-tool header created from `wifi/ESP8266P.rom` and appended to the UF2 image |

For the full WiFi-specific register map and usage notes, see `docs/msx-picoverse-2350-wifi.md`.
| `pico/loadrom/loadrom.h` | Pin definitions, SRAM pool, mapper constants |
| `pico/loadrom/CMakeLists.txt` | Build configuration with both USB and SD dependencies |
| `tool/src/loadrom.c` | PC tool: `-s1`/`-m1`/`-s2`/`-m2` options, UF2 generation |
| `tool/Makefile` | Build scripts, embedded ROM header generation |
| `nextor/kernel/Nextor-2.1.4.SunriseIDE.MasterOnly.ROM` | 128KB Nextor Sunrise IDE kernel |
| `lib/no-OS-FatFS-SD-SDIO-SPI-RPi-Pico/` | Carl Kugler's FatFS + SPI SD driver library |

All paths are relative to `2350/software/loadrom.pio/`.

## 13. Comparison with PicoVerse 2040

| Feature | PicoVerse 2040 | PicoVerse 2350 |
|---|---|---|
| USB Sunrise IDE | Yes (`-s`) | Yes (`-s2`) |
| USB Sunrise + Mapper | Yes (`-m`, 192KB) | Yes (`-m2`, 1MB) |
| microSD Sunrise IDE | No | Yes (`-s1`) |
| microSD Sunrise + Mapper | No | Yes (`-m1`, 1MB) |
| Mapper RAM | 192KB (12 pages) | 1MB (64 pages) |
| SD card slot | No | Yes (SPI0, GPIO 33–36) |
| Nextor ROM | Nextor 2.1.4 Sunrise IDE | Nextor 2.1.4 Sunrise IDE |
| ATA front-end | Identical | Identical |
| Device info | USB SCSI INQUIRY | USB SCSI INQUIRY or SD CID |

The ATA front-end code (`sunrise_ide.c`) is shared between both platforms. The 2350 simply adds the SD backend as an alternative to USB.

Author: Cristiano Goncalves  
Last updated: 06/13/2026

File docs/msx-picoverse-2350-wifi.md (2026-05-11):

# MSX PicoVerse 2350 WiFi Support

This document describes the ESP-01 WiFi support currently implemented for the PicoVerse 2350 firmware family.

The PicoVerse 2350 WiFi implementation has two user-facing surfaces: an ESP8266P-compatible system ROM and memio UART bridge on top of the Sunrise IDE Nextor modes, and the integrated Explorer File Hunter browser that uses the ESP-01 module directly from the Pico firmware.

## 1. Overview

WiFi support is enabled from the RP2350 LoadROM tool with the `-w` or `--wifi` flag.

The flag is currently valid only with these four firmware modes:

| LoadROM Option | Storage Backend | Mapper | WiFi Support |
|---|---|---|---|
| `-s1 -w` | microSD | none | yes |
| `-m1 -w` | microSD | 1MB PSRAM mapper | yes |
| `-s2 -w` | USB mass storage | none | yes |
| `-m2 -w` | USB mass storage | 1MB PSRAM mapper | yes |

WiFi support is available in both LoadROM (`loadrom.exe -w`) and MultiROM (`multirom.exe -w`) for Sunrise IDE modes. Explorer also uses the ESP-01 module for File Hunter browsing and exposes WiFi setup through `F4`; this Explorer path is built into the Explorer firmware and does not use a `-w` tool option.

The Sunrise IDE `-w` option is not currently exposed in:

- `-c1` / `-c2` Carnivore2-compatible RAM loader modes

In practical terms, `-w` keeps the normal Nextor boot/storage behavior and adds a second ROM/interface surface for WiFi-aware MSX software.

## 2. What The Feature Adds

When `-w` is enabled, the generated UF2 contains:

- The existing PicoVerse 2350 Sunrise IDE firmware
- The embedded Nextor 2.1.4 Sunrise IDE ROM
- A WiFi flag in the configuration record (`0x20`)
- An embedded 16KB ESP8266P system ROM
- A memory-mapped UART backend that services the ESP ROM protocol through the installed ESP-01 module

The host tool prints this explicitly when building the image:

```text
WiFi Support: Enabled (ESP8266P system ROM + UART support)
```

## 3. User-Facing Build Commands

Typical commands are:

```bash
# Nextor via microSD + WiFi
loadrom.exe -s1 -w -o nextor_sd_wifi.uf2

# Nextor via microSD + 1MB mapper + WiFi
loadrom.exe -m1 -w -o nextor_mapper_sd_wifi.uf2

# Nextor via USB + WiFi
loadrom.exe -s2 -w -o nextor_usb_wifi.uf2

# Nextor via USB + 1MB mapper + WiFi
loadrom.exe -m2 -w -o nextor_mapper_usb_wifi.uf2
```

The `-w` flag is rejected for any other mode:

```text
Error: -w/--wifi is supported only with -s1, -m1, -s2 or -m2.
```

## 4. Hardware Context

The PicoVerse 2350 hardware includes an ESP-01 header. The WiFi implementation assumes:

- A PicoVerse 2350 board revision that routes the ESP-01 UART signals to the RP2350 firmware backend
- An ESP-01 / ESP8266 module installed on the board
- A storage device appropriate for the selected Nextor mode
  - microSD card for `-s1 -w` / `-m1 -w`
  - USB mass storage device for `-s2 -w` / `-m2 -w`

The firmware exposes the ESP link through the MSX-visible memio interface. It does not replace the ESP firmware running on the ESP-01 itself.

## 5. Boot Model

WiFi support is implemented as an overlay on the Sunrise IDE modes.

### Plain Sunrise WiFi Modes

For `-s1 -w` and `-s2 -w`, the firmware uses a two-subslot expanded layout after the bootstrap restart:

| Sub-slot | Function |
|---|---|
| 0 | ESP8266P system ROM and memio UART registers |
| 1 | Nextor Sunrise IDE ROM and IDE register surface |

### Mapper WiFi Modes

For `-m1 -w` and `-m2 -w`, the firmware uses a three-subslot layout:

| Sub-slot | Function |
|---|---|
| 0 | ESP8266P system ROM and memio UART registers |
| 1 | Nextor Sunrise IDE ROM and IDE register surface |
| 2 | 1MB PSRAM-backed MSX memory mapper |

This matters because WiFi support is not just a serial sidecar. It is mapped into the MSX-visible cartridge space in the same expanded-slot model used by the Sunrise mapper implementation.

The ESP8266P BIOS is placed in sub-slot 0 so its `INIT` routine runs before Nextor's during the MSX BIOS expanded-slot scan. This ordering is required for compatibility with FPGA-based MSX cores (e.g. ESEMSX3-derived cores), which are sensitive to the bus / sub-slot state immediately after a sub-slot transition. On real MSX hardware the ordering is functionally equivalent to the previous layout.

## 6. Embedded ESP System ROM

The PicoVerse firmware embeds a dedicated 16KB system ROM:

- Source asset: `2350/software/loadrom.pio/wifi/ESP8266P.rom`
- Tool-generated header: `2350/software/loadrom.pio/tool/src/esp8266p_rom.h`

This ROM is intended to run as a page-1 system ROM (`0x4000`-`0x7FFF`) and expects a memory-mapped WiFi transport rather than a classic I/O-port UART.

The Pico firmware does not embed this ROM as a source asset anymore. The standard project flow is used instead: the tool Makefile generates a C header from the ROM, and `loadrom.exe` appends that ROM after the Sunrise ROM in the final UF2 payload.

The integration goal is compatibility with MSX software targeting the ESP8266P memio environment used by Ducasp's MSX WiFi work.

## 7. Memory Map

The WiFi surface lives in the `0x4000`-`0x7FFF` area of the WiFi subslot.

### ROM Window

- `0x4000`-`0x7FFF`: embedded ESP8266P system ROM

### memio Registers

| Address | Direction | Purpose |
|---|---|---|
| `0x7F05` | read/write | F2 state byte used by the ESP system ROM boot/status logic |
| `0x7F06` | write | UART command port |
| `0x7F06` | read | UART RX data port |
| `0x7F07` | write | UART TX data port |
| `0x7F07` | read | UART status port |

## 8. F2 State Byte

The firmware exposes the `0x7F05` state byte expected by the ESP system ROM. The values used by the original ROM/software ecosystem include:

| Value | Meaning |
|---|---|
| `0xFF` | cold boot default |
| `0xF0` | system ROM loaded once |
| `0xF1` | enter setup flow |
| `0xF2` | force ESP detection on warm boot |
| `0xFE` | unexpected error |
| `0xEF` | disabled or ESP not found |

The PicoVerse backend stores and returns the byte as written by the MSX-side ROM/software.

## 9. UART Command Port (`0x7F06` write)

The write-side command port now follows Oduvaldo's MSXPICO memio recommendation used by the ROM-side code path: the UART stays fixed at `859372` bps and only command `20` is honored.

| Command | Behavior |
|---|---|
| `20` | Clear the RX FIFO and drain any already-buffered UART bytes |

All other command values written to `0x7F06` are ignored. They do not change the UART baud rate.

The PicoVerse UART backend is initialized once and remains fixed at `859372` bps for the whole session.

## 10. UART Status Port (`0x7F07` read)

The status byte follows the WiFi memio conventions used by the reference FPGA implementations.

| Bit | Meaning |
|---|---|
| 0 | RX FIFO has data available |
| 1 | TX transmission in progress / UART not writable |
| 2 | RX FIFO full |
| 3 | quick receive supported |
| 4 | RX underrun occurred; clears after status read |
| 6 | set to `1` in the normal non-interrupt state |
| 7 | set to `1` in the normal non-interrupt state |

The current PicoVerse implementation does not expose the old interrupt-oriented WiFi behavior. It implements the lite/request-response memio behavior instead.

## 11. Quick Receive and FIFO Behavior

The WiFi backend implements the two important behavioral details from the reference designs:

- **RX FIFO depth**: `2080` bytes
- **Quick receive wait**: about `25 ms`

That means a read from `0x7F06` behaves like this:

1. If data is already buffered, return it immediately.
2. If the FIFO is empty, wait briefly for incoming UART data.
3. If no byte arrives before the quick-receive timeout expires, return `0xFF` and latch the underrun bit.

This behavior is important because existing MSX WiFi software expects the adapter to absorb short timing gaps without immediately failing an RX read.

## 12. Firmware Architecture

The implementation is split across the RP2350 host tool and the RP2350 cartridge firmware.

### Host Tool

File:

- `2350/software/loadrom.pio/tool/src/loadrom.c`

Responsibilities:

- parse `-w` / `--wifi`
- reject `-w` outside `-s1/-m1/-s2/-m2`
- set the WiFi flag bit in the configuration record
- report WiFi as enabled in the build output

### Firmware

Files:

- `2350/software/loadrom.pio/pico/loadrom/loadrom.c`
- `2350/software/loadrom.pio/pico/loadrom/loadrom.h`

Responsibilities:

- decode the WiFi flag from `rom_type`
- dispatch WiFi-aware Sunrise handlers
- serve the ESP system ROM in the WiFi subslot
- implement the memio register block at `0x7F05`-`0x7F07`
- service RX/TX through the RP2350 UART backend

The build also links `hardware_uart` so the WiFi backend is included in the RP2350 firmware image.

## 13. Relationship To Nextor And Carnivore2 Modes

### Nextor

WiFi support is additive to the standard Sunrise IDE modes.

- Nextor still boots from the embedded Sunrise IDE ROM.
- Storage still comes from either microSD or USB.
- WiFi adds a second ROM/interface surface for MSX-side WiFi software.

### Carnivore2 RAM Loader

The current WiFi flag is intentionally not enabled for `-c1` or `-c2`.

Those modes already extend the mapper path with Carnivore2-compatible RAM-mode behavior for `SROM.COM /D15`. Combining WiFi with the Carnivore2 RAM loader was left out of the first implementation to keep the expanded-slot routing and compatibility surface controlled.

## 14. Typical Usage Flow

1. Build a UF2 with one of the supported WiFi commands:
   - `loadrom.exe -s1 -w`
   - `loadrom.exe -m1 -w`
   - `loadrom.exe -s2 -w`
   - `loadrom.exe -m2 -w`
2. Flash the UF2 to the PicoVerse 2350 in BOOTSEL mode.
3. Install the storage media required by the chosen Nextor mode.
4. Install the ESP-01 module on the cartridge.
5. Power on the MSX and let Nextor boot normally.
6. Run MSX software designed for the ESP8266P memio ROM/interface.

The important point is that WiFi support is not a standalone boot mode. It is a Nextor-side system-ROM add-on carried by the WiFi-enabled Sunrise UF2.

### Explorer File Hunter

Explorer firmware uses the same ESP-01 hardware path for its integrated File Hunter browser. Press `F3` in Explorer to open File Hunter, and press `F4` from Explorer or File Hunter to enter WiFi setup. File Hunter requests are handled by the Pico firmware through the ESP8266 command protocol; the MSX menu is used as the browser UI rather than booting a separate UNAPI BIOS ROM.

File Hunter downloads are received into PSRAM and saved as `.ROM` files in the root of the microSD card. A microSD card is required for this workflow.

## 15. Current Scope And Limitations

- WiFi support is available in **LoadROM** and **MultiROM** (in MultiROM only on `-s1`/`-m1`/`-s2`/`-m2` Nextor entries).
- WiFi support is currently **not available** in `-c1` / `-c2` Carnivore2 RAM-loader builds.
- Explorer exposes WiFi setup and direct ESP-01 access for File Hunter browsing, but it does not expose the Sunrise IDE `-w` system-ROM boot mode.
- The PicoVerse firmware provides the ROM mapping and serial transport; the ESP-01 still needs compatible firmware on the module itself.
- The implementation follows the ESP8266P memio conventions, so compatibility is best with software already targeting that environment.

## 16. Related Documents

- `docs/msx-picoverse-2350-loadrom-tool-manual.en-us.md`
- `docs/msx-picoverse-2350-explorer-tool-manual.en-us.md`
- `docs/msx-picoverse-2350-sunrise-nextor.md`
- `docs/msx-picoverse-2350-features.md`

## 17. External Design References

The PicoVerse 2350 WiFi implementation was informed by these reference projects and documents:

- Ducasp's MSXPICO ESP memio ROM work
- Ducasp's ESP8266 UNAPI firmware protocol
- Ducasp's FPGA WiFi / WiFi Lite memio implementations

These references were used to match the existing ESP memio conventions: address map, status bits, quick receive behavior, baud command table, and FIFO expectations.

Author: Cristiano Goncalves
Last updated: 05/04/2026

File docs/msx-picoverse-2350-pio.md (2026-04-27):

# MSX PicoVerse 2350 PIO Bus Strategy

This document describes the RP2350 PIO strategy currently used in:

- `2350/software/loadrom.pio`
- `2350/software/multirom.pio`

Both targets share the same PIO bus engine, I/O bus engine, and audio architecture. The MultiROM firmware extends LoadROM by embedding multiple ROMs with a menu, while both support the full mapper set (types 1–16) including Sunrise IDE, SCC/SCC+, Manbow2, and ASCII16-X.

---

## 1) Core Strategy

| Owner | Responsibility |
|---|---|
| **PIO bus engine (`pio0`)** | Detect `/SLTSL` + `/RD`/`/WR`, assert `/WAIT`, capture writes, drive/release D0..D7 |
| **PIO I/O bus engine (`pio1`, mapper mode)** | Capture `/IORQ` + `/RD`/`/WR` for mapper page register access (ports FC–FF) |
| **PIO I2S audio (`pio1`, SCC mode)** | Generate I2S bitstream for SCC/SCC+ audio output via DAC |
| **CPU (core 0)** | Mapper translation, ROM lookup, SCC/SCC+ register forwarding, Sunrise IDE register handling |
| **CPU (core 1, SCC mode)** | Audio generation for SCC/SCC+ via emu2212 and I2S output |
| **CPU (core 1, Sunrise mode)** | TinyUSB host stack — USB mass storage read/write for Sunrise IDE emulation |

The bus strategy is still PIO + FIFO tokenization, but RP2350 adds an audio subsystem path (SCC/SCC+), a Sunrise IDE path with USB host, and platform-specific GPIO/clock settings.

> **Note:** PIO1 is shared between I2S audio (SCC mode) and I/O bus (mapper mode). These are mutually exclusive at runtime.

---

## 2) PIO Bus Architecture

`loadrom.pio` and `multirom.pio` use two state machines on `pio0` for MSX memory bus access:

| SM | Program | Role |
|---|---|---|
| `SM0` | `msx_read_responder` | Read-cycle responder with `/WAIT` side-set and tokenized data output |
| `SM1` | `msx_write_captor` | Write-cycle capture for mapper and SCC register writes |

In mapper mode (`-m`), two additional state machines on `pio1` handle I/O bus access:

| SM | Program | Role |
|---|---|---|
| `SM0` | `msx_io_read_responder` | I/O read-cycle responder for mapper page registers (FC–FF) |
| `SM1` | `msx_io_write_captor` | I/O write-cycle capture for mapper page registers (FC–FF) |

The implementation uses `jmp pin` polling to re-check slot/IORQ validity while waiting for read/write strobes, preventing stale-slot race behavior.

---

## 3) RP2350 Pin Map (PIO bus + extras)

### Bus pins

| GPIO | Signal |
|---|---|
| 0–15 | A0–A15 |
| 16–23 | D0–D7 |
| 24 | `/RD` |
| 25 | `/WR` |
| 26 | `/IORQ` |
| 27 | `/SLTSL` |
| 28 | `/WAIT` |
| 37 | `BUSSDIR` |
| 47 | `PSRAM select` |

### Audio pins (SCC/SCC+ mode)

| GPIO | Signal |
|---|---|
| 29 | I2S DATA |
| 30 | I2S BCLK |
| 31 | I2S WSEL/LRCLK |
| 32 | DAC MUTE control |

---

## 4) FIFO Contract

### Write captor (`SM1 -> CPU`)

- `bits[15:0]` = address
- `bits[23:16]` = data

### Read token (`CPU -> SM0`)

- `bits[7:0]` = data byte
- `bits[15:8]` = pin-direction mask (`0xFF` drive, `0x00` tri-state)

---

## 5) RP2350-Specific Runtime Details

### Clocking and flash timing

- Firmware sets QMI flash timing (`qmi_hw->m[0].timing = 0x40000202`).
- System clock is configured to **210 MHz**.

### ROM serving

- Uses a 256 KB SRAM cache with flash fallback for ROMs exceeding cache capacity.
- microSD-resident ROMs (Explorer firmware) up to 2 MB are streamed into the cartridge's external 8 MB PSRAM (QMI CS1, 52.5 MHz QPI). The leading window is mirrored into the same 256 KB SRAM cache used by flash ROMs, so the mapper hot-loop accesses go through fast SRAM regardless of source.
- GPIO input hysteresis is enabled on address (A0–A15) and data (D0–D7) pins to filter bus glitches.
- Mapper support includes Plain16/32, Planar48, Planar64, Konami SCC, Konami, ASCII8, ASCII16, ASCII16-X, NEO8, NEO16, Manbow2, Sunrise IDE, and Sunrise IDE + 1MB PSRAM Mapper.

### Sunrise IDE integration

The firmware supports four Sunrise IDE modes, selected by mapper type:

| Option | Type | Core 1 Backend | Storage |
|---|---|---|---|
| `-s1` | 15 | `sunrise_sd_task()` | microSD via SPI0 |
| `-m1` | 16 | `sunrise_sd_task()` | microSD via SPI0 |
| `-s2` | 10 | `sunrise_usb_task()` | USB via TinyUSB |
| `-m2` | 11 | `sunrise_usb_task()` | USB via TinyUSB |

For all modes:

- Core 0 handles the PIO memory bus, Sunrise IDE register emulation, and ROM banking.
- Core 1 runs the appropriate storage backend (USB or SD), translating ATA commands into block I/O.
- The embedded Nextor 2.1.4 Sunrise IDE kernel ROM (128KB, 8 × 16KB pages) is served from flash.
- IDE register overlay at `0x7C00`–`0x7EFF` is intercepted when the IDE enable bit is set.

For USB modes (`-s2`/`-m2`):

- Core 1 runs the TinyUSB USB host stack with asynchronous MSC read/write and a 3-second timeout watchdog.
- Device info for ATA IDENTIFY comes from the USB SCSI INQUIRY response.

For microSD modes (`-s1`/`-m1`):

- Core 1 runs synchronous SPI block I/O via `disk_read()`/`disk_write()` from the no-OS-FatFS library.
- Device info for ATA IDENTIFY is extracted from the SD card's CID register (OEM ID, Product Name, Revision).
- SD card hardware: SPI0, CS=GPIO33, SCK=GPIO34, MOSI=GPIO35, MISO=GPIO36 at 31.25 MHz.

In mapper mode (`-m`), additionally:

- PIO1 SM0/SM1 run `msx_io_read_responder` / `msx_io_write_captor` to intercept I/O ports FC–FF.
- For `loadrom.pio` `-m1`/`-m2`, 1MB of external PSRAM on QMI CS1 (GPIO47) is used as mapper RAM (64 × 16KB pages), accessed through the uncached CS1 window.
- An expanded sub-slot architecture provides sub-slot 0 (Nextor ROM) and sub-slot 1 (mapper RAM).
- A bootstrap ROM phase ensures clean cold-boot before the expanded-slot mapper is activated.

### SCC / SCC+ integration

When `-scc` or `-sccplus` flags are encoded in the ROM type byte (supported for Konami SCC and Manbow2 mapper types):

- Core 0 continues bus/memory service and forwards SCC writes.
- Core 1 continuously generates PCM audio from emu2212.
- Audio is sent using `pico_audio_i2s`.
- Build sets `PICO_AUDIO_I2S_PIO=1` so audio runs on **PIO1**, keeping **PIO0** dedicated to MSX bus handling.

For full SCC/SCC+ behavior and registers, see:

- `docs/msx-picoverse-2350-scc.md`

---

## 6) Build Integration

Both `2350/software/loadrom.pio/pico/loadrom/CMakeLists.txt` and `2350/software/multirom.pio/pico/multirom/CMakeLists.txt` include:

- `pico_generate_pio_header(... msx_bus.pio)`
- `hardware_pio`
- `hardware_dma`
- `pico_multicore`
- `pico_audio_i2s` (via `pico_extras_import.cmake`)
- `tinyusb_board` and `tinyusb_host` (for Sunrise IDE USB host support)
- `no-OS-FatFS-SD-SDIO-SPI-RPi-Pico` (for Sunrise IDE microSD support)
- `sunrise_ide.c` (Sunrise IDE ATA emulation + USB MSC bridge)
- `sunrise_sd.c` (Sunrise IDE microSD SPI backend)
- `hw_config.c` (microSD SPI pin configuration)

---

Cristiano Goncalves  
03/29/26

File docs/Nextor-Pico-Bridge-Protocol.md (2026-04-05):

# NEXTOR <-> PicoBridge Protocol

Author: Cristiano Goncalves
Last updated: November 29, 2025

This document describes the control/data protocol implemented by the Raspberry Pico bridge firmware in `2040/software/multirom.pio/pico/multirom/nextor.c`.
The bridge provides an interface between an MSX running NEXTOR and a USB Mass Storage Device (MSC) attached to the Pico. The MSX communicates with the Pico via two I/O ports (control and data) using simple commands, addresses and payload transfers.

This specification documents the transport, command set, data formats, read/write sequences, return codes, error handling and implementation notes so other implementers can reproduce the protocol behavior.

## Terminology
- **MSX**: The host (NEXTOR) that talks to the Pico over the MSX I/O bus.
- **Pico / Bridge**: The Raspberry Pico running the firmware in `nextor.c`.
- **MSC**: USB Mass Storage Class device (USB flash, SD card reader, etc.).
- **LBA**: Logical Block Addressing (sector index).

## Ports
- **Control port**: `0x9E` (named `PORT_CONTROL` in firmware). Writes select commands, reads return the control status byte.
- **Data port**: `0x9F` (named `PORT_DATAREG` in firmware). Used to transfer payload bytes (addresses, descriptors, block payloads).

**Control response values (status byte)**
- `0x00` : Success / Ready
- `0x01` : Busy (operation in progress)
- `0xFF` : Error / Invalid / Not available

Control reads return the last status byte placed in `control_response`.

## Transport model
- All command-selection is performed by writing a single command byte to the control port (`0x9E`).
- Additional bytes required by the command are transferred via the data port (`0x9F`) using MSX writes.
- When a command produces a multi-byte response, the bridge populates an internal `data_response_buffer` and sets `data_response_pending = true`. The MSX reads response bytes from the data port (`0x9F`) until the bridge clears `data_response_pending`.
- For read and write operations on the MSC, the bridge uses asynchronous TinyUSB MSC requests. While USB MSC requests are active the bridge reports `0x01` (Busy) on the control port.

## Important global constraints
- The firmware caches `usb_device_info_valid` to indicate a valid MSC device is attached and probed. Many commands fail with `0xFF` until a device is mounted, probed and `usb_device_info_valid` is true.
- `usb_block_size` must be non-zero and <= 512 (the code uses 512-sized buffers). If device block size is larger than the buffer the operation will be rejected.

## Command list

1) Initialize USB Host
- Command byte: `0x01` (Control Write)
- Description: Start/init the USB host stack on the Pico so attached MSCs can be enumerated.
- Behavior:
  - If no device info is present, the firmware sets `usb_task_running = true`, reports intermediate `control_response = 0x01` then attempts to init TinyUSB/TUH (`tusb_init()`, `board_init_after_tusb()`, `tuh_init(0)`).
  - On success the command sets `control_response = 0x00`.
  - If a device is already known the command simply returns `0x00`.

2) Get USB VID (Vendor ID)
- Command byte: `0x02` (Control Write)
- Response: two bytes returned via data port, little-endian: low byte then high byte of `usb_device_info.vid`.
- Behavior:
  - If `usb_device_info_valid` is false, the command returns `control_response = 0xFF`.
  - Otherwise it preloads `data_response_buffer[0..1]` and sets `data_response_length = 2` and `control_response = 0x00`.

3) Get USB Vendor/Product strings and Revision
- Command byte: `0x03` (Control Write)
- Response via data port: concatenated strings
  - Vendor ID string: up to 8 bytes (padded or filled; the firmware writes the string into an 8-byte field)
  - Product ID string: up to 16 bytes
  - Product revision string: up to 4 bytes
  - Total response length is 8 + 16 + 4 = 28 bytes (or less depending on null-terminated string lengths, but unused bytes have value `0xFF`).
- Behavior: returns `0xFF` if `usb_device_info_valid` is false.

4) Get USB sectors (block count)
- Command byte: `0x04` (Control Write)
- Response: 4 bytes little-endian representing `usb_block_count` (32-bit unsigned).
- Behavior: returns `0xFF` if `usb_device_info_valid` is false.

5) Get USB block size
- Command byte: `0x05` (Control Write)
- Response: 4 bytes little-endian representing `usb_block_size` (32-bit unsigned). Note: firmware expects this to be <= 512.
- Behavior: returns `0xFF` if `usb_device_info_valid` is false.

6) Read a single 512-byte block (explicit LBA)
- Command byte: `0x06` (Control Write)
- Sequence:
  1. MSX writes `0x06` to control port. Bridge checks device present and other invariants. If OK, it enters an address-collection state and sets `control_response = 0x01` (Busy).
  2. MSX writes four bytes (little-endian) to the data port (`0x9F`): LBA low, LBA+1, LBA+2, LBA+3.
  3. After the 4th address byte, the bridge calls `start_block_read(latched_read_lba)` which issues `tuh_msc_read10()` for 1 block. While the USB read is outstanding the control port will return `0x01` (Busy).
  4. When the USB read completes successfully the firmware copies the block into `data_response_buffer`, pads/truncates to 512 bytes and sets `data_response_length = 512` and `control_response = 0x00`.
  5. MSX reads 512 bytes from the data port; the bridge returns bytes from `data_response_buffer` one at a time while `data_response_pending` is true. Once all bytes are read the bridge clears `data_response_pending` and sets `control_response = 0x00`.
- Error conditions:
  - If no device/invalid block size, or a read already pending, the initial command returns `0xFF`.
  - If `start_block_read()` fails or the USB request fails, the bridge will eventually set `control_response = 0xFF` and `read_sequence_valid = false`.

7) Read next sequential 512-byte block
- Command byte: `0x07` (Control Write)
- Sequence:
  - This command requires `read_sequence_valid == true`; typically set after a successful `0x06` read. The firmware will attempt to start a block read of `read_next_lba`.
  - If the requested LBA >= `usb_block_count` the command fails (`control_response = 0xFF`) and `read_sequence_valid` is cleared.
  - On success it calls `start_block_read(requested_lba)`, updates `read_next_lba = requested_lba + 1` and sets `control_response = 0x01` (Busy) until the block arrives.

8) Write a single 512-byte block with explicit address
- Command byte: `0x08` (Control Write)
- Sequence:
  1. MSX writes `0x08` to control port. The bridge enters an address-collection state and sets `control_response = 0x01`.
  2. MSX writes 4 little-endian address bytes to the data port to specify LBA.
  3. Bridge validates LBA < `usb_block_count`. If valid it sets `current_write_lba = pending_write_lba`, `write_data_pending = true` and starts collecting payload bytes.
  4. MSX writes `usb_block_size` bytes to data port. Each write stores one byte into `block_write_buffer`.
  5. After the full payload is collected the firmware calls `start_block_write(current_write_lba)` which issues `tuh_msc_write10()` for 1 block. While the USB write is outstanding the control port returns `0x01` (Busy).
  6. On completion the bridge sets `control_response = 0x00` (success) or `0xFF` (failure) depending on the MSC result.
- Error conditions:
  - If device not present, invalid block size, write already in progress, or invalid LBA, the command returns `0xFF`.

9) Write next sequential 512-byte block
- Command byte: `0x09` (Control Write)
- Sequence:
  - Requires `write_sequence_valid == true` (set by a successful prior write).
  - The bridge checks `write_next_lba < usb_block_count`. If OK it sets `pending_write_lba = write_next_lba`, `current_write_lba = pending_write_lba`, `write_data_pending = true` and `control_response = 0x01`.
  - MSX sends `usb_block_size` payload bytes to the data port, after which the bridge calls `start_block_write(current_write_lba)` and returns `0x01` until write completes.

## Data framing and byte order
- Multi-byte integers transferred between MSX and bridge are always little-endian in this implementation.
- LBAs are 32-bit unsigned values encoded as 4 consecutive bytes (LSB first).
- Block count and block size responses are 32-bit little-endian integers (4 bytes).

## Data payloads
- Block reads: Bridge guarantees `data_response_length` will be set to 512 after a successful read. If the returned block is shorter the firmware pads the remainder with `0x00`.
- Block writes: MSX must send exactly `usb_block_size` bytes for the write payload. `usb_block_size` is read via command `0x05`.

## Error handling and state flags
- `usb_device_info_valid` : When false many commands return `0xFF`.
- `block_read_in_progress`, `block_read_ready`, `block_read_failed` : control the read lifecycle. A failed read clears `read_sequence_valid`.
- `block_write_in_progress`, `block_write_done`, `block_write_failed` : control the write lifecycle. A failed write clears `write_sequence_valid`.
- `read_sequence_valid`, `read_next_lba`, `write_sequence_valid`, `write_next_lba` : track sequential read/write sequences for `0x07` and `0x09` commands.

## Low-level IO notes (implementation details)
- The firmware polls MSX bus signals using GPIOs:
  - `PIN_IORQ` is used to detect an IO request (active low).
  - `PIN_WR` and `PIN_RD` detect write/read strobes (active low).
  - `gpio_get_all()` is sampled; the low 8 bits represent the I/O port address and bits 16..23 represent the data bus value (shifted by 16 in the code).
- During control/data reads the firmware temporarily drives the Pico data bus GPIOs to output to return bytes, then returns them to input.

## Examples

### Read block 0 example:
1. MSX: OUT (port 0x9E), value `0x06`   ; Request explicit read
2. MSX: OUT (port 0x9F), value `0x00`   ; LBA byte 0 (LSB)
3. MSX: OUT (port 0x9F), value `0x00`   ; LBA byte 1
4. MSX: OUT (port 0x9F), value `0x00`   ; LBA byte 2
5. MSX: OUT (port 0x9F), value `0x00`   ; LBA byte 3 (MSB)
   - Bridge returns control port `0x01` while performing USB read.
6. After USB completes, MSX: IN (port 0x9E) returns `0x00` (ready)
7. MSX: IN (port 0x9F) repeated 512 times to read the block payload (bridge returns bytes from `data_response_buffer`).

### Sequential read example (read block N then N+1):
1. Do explicit read of block N (as above) — this sets `read_sequence_valid` and `read_next_lba = N+1`.
2. MSX: OUT (port 0x9E), value `0x07` ; Request next sequential block
   - Bridge will start read of `read_next_lba` and increment `read_next_lba` again on success.

### Write block example (explicit address):
1. MSX: OUT (port 0x9E), value `0x08` ; Start write with explicit address
2. MSX: OUT (port 0x9F), value LBA byte 0
3. MSX: OUT (port 0x9F), value LBA byte 1
4. MSX: OUT (port 0x9F), value LBA byte 2
5. MSX: OUT (port 0x9F), value LBA byte 3
6. MSX: OUT (port 0x9F) repeated `usb_block_size` times with payload bytes
   - Bridge returns `0x01` while the write completes. After completion, the control port will return `0x00` for success or `0xFF` for failure.

## Implementation notes / caveats
- The bridge uses TinyUSB host stack asynchronously. USB transactions may take relatively long time; the firmware reports busy via `0x01` so the MSX can wait or poll.
- The firmware limits block payload handling to 512 bytes buffers. If a device returns a `usb_block_size` larger than the internal buffer the operation will fail.
- The data response buffer is pre-filled with `0xFF` by default; on successful reads the bridge copies the read data into the response buffer and pads any missing bytes with `0x00`.
- The firmware assumes little-endian ordering for all multi-byte integers exchanged with the MSX.
- The firmware uses the `read_sequence_valid` and `write_sequence_valid` flags to maintain sequential transfers; those flags are cleared on errors.

## Pointers to code
- Command handling and protocol state machine: `nextor_io()` in `nextor.c`.
- USB read/write start and completion: `start_block_read()`, `block_read_complete_cb()`, `start_block_write()`, `block_write_complete_cb()`.
- USB device probing/inquiry: `tuh_msc_inquiry()` and `inquiry_complete_cb()`.

## Appendix: Quick reference
- Control port (`0x9E`) commands and behaviour:
  - `0x01` : Initialize USB host (returns `0x00` or `0xFF`)
  - `0x02` : Get VID (2 bytes, LE)
  - `0x03` : Get vendor/product/rev strings (8/16/4 bytes)
  - `0x04` : Get block count (4 bytes, LE)
  - `0x05` : Get block size (4 bytes, LE)
  - `0x06` : Read explicit block (send 4 LBA bytes via data port, then read 512 bytes)
  - `0x07` : Read next sequential block (no address bytes)
  - `0x08` : Write explicit block (send 4 LBA bytes then send payload bytes)
  - `0x09` : Write next sequential block (no address bytes)

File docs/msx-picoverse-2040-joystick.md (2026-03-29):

# MSX PicoVerse 2040 USB Joystick

This document describes the standalone USB joystick firmware for the PicoVerse 2040 cartridge. The firmware turns the cartridge into a dedicated USB-to-MSX joystick adapter: plug a standard USB gamepad into the cartridge's USB-C port and it appears as one or two native MSX joysticks to the host system, with no MSX-side software or driver required.

---

## Overview

MSX joysticks are managed through the PSG (Programmable Sound Generator, AY-3-8910 or YM2149) General Purpose I/O interface, not through the PPI. Software reads joystick state by writing to PSG registers via I/O ports `0xA0`–`0xA2`. The PicoVerse joystick firmware intercepts these three ports and overlays USB gamepad input onto the joystick bits of PSG register 14, using an open-drain bus driving technique that allows the real PSG chip to continue functioning normally for sound generation.

### Intercepted I/O Ports

| Port | Direction | Purpose |
| --- | --- | --- |
| `0xA0` | OUT (Z80 writes) | PSG register address latch — the firmware tracks which register the software wants to access |
| `0xA1` | OUT (Z80 writes) | PSG register data write — the firmware watches for writes to R15 bit 6 to know which joystick port is selected |
| `0xA2` | IN (Z80 reads) | PSG register data read — when the latched register is R14, the firmware injects joystick data using open-drain driving |

### Key Features

- Fully standalone: does not require any MSX-side software or driver.
- Supports generic USB HID gamepads, including gamepads connected through USB hubs.
- Supports Xbox 360 and XInput-compatible controllers via a dedicated XInput protocol driver.
- Supports Xbox One and Xbox Series X|S controllers via a dedicated GIP protocol driver.
- Full joystick coverage: 4 directions (Up, Down, Left, Right) and 2 trigger buttons (A and B).
- Both D-pad (hat switch) and analog stick are supported simultaneously, with a configurable deadzone for the analog stick.
- Up to 2 USB gamepads can be connected, mapped to MSX joystick ports 1 and 2.
- Open-drain bus driving coexists with the real PSG chip — sound output is unaffected.
- Runs at 250 MHz for minimal response latency.

---

## MSX Joystick Interface

This section describes how the MSX joystick hardware works, based on the [General Purpose port](https://www.msx.org/wiki/General_Purpose_port) and [Joystick/joypad controller](https://www.msx.org/wiki/Joystick/joypad_controller) pages of the MSX Wiki.

### Physical Connector

MSX computers provide two DE-9 female joystick connectors. Each connector carries four direction lines, two trigger buttons, an output line, and power:

| DE-9 Pin | Signal | Direction | PSG R14 Bit |
| --- | --- | --- | --- |
| 1 | Up | Input (active-low) | Bit 0 |
| 2 | Down | Input (active-low) | Bit 1 |
| 3 | Left | Input (active-low) | Bit 2 |
| 4 | Right | Input (active-low) | Bit 3 |
| 5 | +5V | Power | — |
| 6 | Trigger A | Input (active-low) | Bit 4 |
| 7 | Trigger B | Input (active-low) | Bit 5 |
| 8 | Output | Output (active-low) | R15 bits 4/5 |
| 9 | GND | Ground | — |

The pin numbering maps directly to the PSG register 14 bit numbering: pin 1 → bit 0, pin 2 → bit 1, and so on.

### Joystick Types

The MSX Technical Specification defines two joystick types:

- **Type A** has one trigger button (or two buttons wired together on pin 6). Compatible with Atari/Commodore single-button joysticks.
- **Type B** has two independent trigger buttons on pins 6 (Trigger A) and 7 (Trigger B). This is the full MSX joystick standard.

The PicoVerse firmware emulates a Type B joystick with full support for both triggers.

### PSG Register 14 (Port A — Joystick Input)

PSG register 14 is a read-only register that reflects the state of the currently selected joystick port. All joystick bits are **active-low** (0 = pressed, 1 = released):

| Bit 7 | Bit 6 | Bit 5 | Bit 4 | Bit 3 | Bit 2 | Bit 1 | Bit 0 |
| --- | --- | --- | --- | --- | --- | --- | --- |
| CASRD | JIS/KANA | Trigger B | Trigger A | Right | Left | Down | Up |

- **Bits 0–5**: Joystick state from the port selected by R15 bit 6.
- **Bit 6**: JIS/KANA key indicator (Japanese MSX only).
- **Bit 7**: Cassette data input.

The firmware only drives bits 0–5. Bits 6–7 are left tri-stated so the real PSG chip provides the cassette and KANA data unmodified.

### PSG Register 15 (Port B — Joystick Output / Port Select)

PSG register 15 is a write-only register that controls the joystick port selection and output pins:

| Bit 7 | Bit 6 | Bit 5 | Bit 4 | Bit 3 | Bit 2 | Bit 1 | Bit 0 |
| --- | --- | --- | --- | --- | --- | --- | --- |
| Arabic/Kana | Port Select | Pin 8 J2 | Pin 8 J1 | Pin 7 J2 | Pin 6 J2 | Pin 7 J1 | Pin 6 J1 |

- **Bit 6** (Port Select): 1 = read joystick port 1, 0 = read joystick port 2 (active on next R14 read).
- **Bits 0–1**: Pin 6/7 of joystick port 1 (must be set HIGH to read the joystick).
- **Bits 2–3**: Pin 6/7 of joystick port 2 (must be set HIGH to read the joystick).
- **Bits 4–5**: Pin 8 of joystick ports 1/2 (must be LOW to read the joystick).

The firmware only tracks bit 6 (port select) to know which of the two MSX joystick ports the software is reading. All other bits are passed through to the real PSG.

### How Software Reads Joysticks

There are three standard methods to read MSX joysticks, all of which are supported by the PicoVerse firmware:

1. **BIOS routines** (`GTSTCK` at `0x00D5`, `GTTRIG` at `0x00D8`): The recommended method. These routines internally access the PSG via I/O ports.

2. **BIOS PSG access** (`WRTPSG` at `0x0093`, `RDPSG` at `0x0096`): Used by many games (e.g. Konami titles). These routines write/read PSG registers via the same I/O ports.

3. **Direct I/O port access** (`OUT (0xA0),reg` / `IN A,(0xA2)`): Not officially recommended by the MSX documentation, but commonly used in games for performance. The firmware intercepts these I/O ports directly, so all three methods work transparently.

A typical joystick read sequence performed by software:

```
OUT (0xA0), 0x0F    ; Latch register 15
IN  A, (0xA2)       ; Read current R15 value
OR  0x0F            ; Set bits 0-3 (trigger pins high)
AND 0x4F            ; Keep bit 6 (port select), clear bits 4-5 (pin 8 low)
OUT (0xA1), A       ; Write R15 — select port, set pin levels

OUT (0xA0), 0x0E    ; Latch register 14
IN  A, (0xA2)       ; Read R14 — joystick state in bits 0-5
```

The firmware tracks the `OUT (0xA0)` writes to maintain the register latch, the `OUT (0xA1)` writes to R15 to track the port select bit, and responds to `IN (0xA2)` reads when the latch points to R14.

---

## Architecture

The firmware uses both cores of the RP2040 and a dedicated pair of PIO state machines on PIO1, following the same dual-core architecture as the keyboard and MIDI standalone firmwares.

### Dual-Core Design

| Core | Role |
| --- | --- |
| **Core 0** | Services PIO1 IRQ. The IRQ fires when either PIO state machine has data in its RX FIFO. The handler processes PSG register latch writes (`0xA0`), R15 port select writes (`0xA1`), and R14 joystick state reads (`0xA2`). Between interrupts, Core 0 sleeps via `__wfi()`. |
| **Core 1** | Runs the TinyUSB host stack. Calls `tuh_task()` in a tight loop to poll for USB events. When a HID gamepad report arrives, the callback parses it and updates the shared `joystick_state[]` array. |

### PIO State Machines (PIO1)

| SM | Program | Role |
| --- | --- | --- |
| SM0 | `msx_joy_io_read` | Monitors `/IORQ` + `/RD`. When an I/O read cycle begins, asserts `/WAIT` (side-set), captures the 16-bit address, pushes it to the RX FIFO, then stalls on `pull block` until Core 0 supplies the response token. Drives D0–D7 with the response data and pindirs, releases `/WAIT`, waits for `/RD` to deassert, then tri-states the data bus. |
| SM1 | `msx_joy_io_write` | Monitors `/IORQ` + `/WR`. Captures a full 32-bit GPIO snapshot (`mov isr, pins`) containing address and data, pushes it to the RX FIFO for Core 0 to decode. Uses FIFO join for 8-deep RX buffering. No `/WAIT` assertion needed for writes. |

### `/WAIT` Signal

The `/WAIT` line (GPIO 28, active-low) freezes the Z80 while the RP2040 prepares the joystick response. The PIO read program uses side-set to control `/WAIT`:

- **`side 0`** = `/WAIT` asserted (Z80 frozen)
- **`side 1`** = `/WAIT` released (Z80 runs)

Without `/WAIT`, the Z80 completes an I/O read in 3–4 T-cycles (~840–1120 ns at 3.58 MHz), which is not enough time for the push/pull FIFO round-trip. Asserting `/WAIT` guarantees that the CPU receives the joystick data regardless of firmware processing time.

During initialisation, the firmware pre-sets the PIO output register for the `/WAIT` pin to HIGH before switching the GPIO mux to PIO control. This prevents a brief glitch where `/WAIT` could be driven LOW (freezing the Z80) between the `pio_gpio_init()` call and the first PIO instruction executing.

---

## Open-Drain Bus Driving

The most significant design challenge for the joystick firmware is that the real PSG chip on the MSX motherboard also drives the data bus when register 14 is read. Unlike the keyboard firmware (where the PPI can be cleanly overridden), both the PSG and the PicoVerse are electrically connected to D0–D7 during a read cycle.

### The Problem

When the Z80 reads I/O port `0xA2` with register 14 latched, the PSG drives all 8 data lines with its own register 14 value. If the PicoVerse also drives the same lines with different values, bus contention occurs — two outputs fighting over the same wire. This can cause incorrect data reads and, in theory, excessive current draw.

### The Solution: Open-Drain Emulation

The firmware uses a selective pin direction (open-drain) technique:

- **For pressed buttons** (bit value = 0): the PicoVerse drives the corresponding data line LOW by setting `pindir = output` and `pin = 0`.
- **For released buttons** (bit value = 1): the PicoVerse tri-states the corresponding data line by setting `pindir = input`, allowing the PSG to drive it HIGH undisturbed.

This works because:

1. With no USB gamepad connected, the PSG's own R14 shows all joystick bits HIGH (nothing pressed). The PicoVerse tri-states all lines → no contention, PSG data passes through.
2. When a USB gamepad button is pressed, the PicoVerse only pulls the corresponding bit LOW. The PSG is also driving that line HIGH (its own R14 shows nothing pressed on the physical connector), but the LOW drive wins on CMOS logic because the RP2040's output driver can sink current effectively. The resulting bus voltage is LOW, which is the correct value.
3. Bits 6–7 (KANA, cassette) are always tri-stated by the PicoVerse, so the PSG provides those signals without interference.

### Response Token Format

The PIO state machine uses a 16-bit response token:

| Bits | Content |
| --- | --- |
| 7:0 | Data byte (always `0x00` for open-drain — we only ever drive LOW) |
| 15:8 | Pin direction mask (`1` = output/drive, `0` = input/tri-state) |

For joystick data, the pin direction mask is calculated as `~joystick_state & 0x3F` — only the bits corresponding to pressed buttons (value 0 in the active-low state) become outputs.

For non-R14 register reads, the firmware responds with `data=0xFF, pindirs=0x00` (full tri-state), allowing the PSG to handle the read entirely on its own.

---

## USB Gamepad Support

The firmware supports two classes of USB gamepads:

1. **Standard USB HID gamepads**: Devices that present a USB HID interface with a Gamepad or Joystick usage. The firmware parses their HID report descriptors at enumeration time to discover the layout of their reports.

2. **XInput (Xbox 360) controllers**: Xbox 360 wired controllers and many third-party XInput-compatible gamepads use a vendor-specific USB protocol (interface class `0xFF`, subclass `0x5D`, protocol `0x01`) rather than standard USB HID. A dedicated TinyUSB custom class driver claims these interfaces and parses their fixed 20-byte input reports.

3. **Xbox One / Series X|S (GIP) controllers**: Xbox One, Xbox One S/X, and Xbox Series X|S controllers use a different vendor-specific protocol called GIP (Game Input Protocol, interface class `0xFF`, subclass `0x47`, protocol `0xD0`). These controllers also require a 5-byte initialisation packet to be sent on the OUT endpoint before they begin producing input reports. The same custom class driver handles both Xbox 360 and Xbox One families.

All three coexist and are active simultaneously. Standard HID gamepads are handled by the TinyUSB HID host driver, while XInput and GIP devices are handled by the custom class driver. Each driver independently allocates MSX joystick ports (up to 2 total across all drivers).

### Why Not Boot Protocol

USB HID defines two protocol modes: boot protocol and report protocol. The keyboard firmware uses boot protocol because USB keyboards have a standardised 8-byte boot report format. **Gamepads have no standard boot protocol** — the USB HID specification only defines boot protocol for keyboards and mice.

Therefore, the joystick firmware uses **HID report protocol** (`CFG_TUH_HID_DEFAULT_PROTOCOL = HID_PROTOCOL_REPORT`) and parses each gamepad's HID report descriptor at enumeration time to discover the layout of its reports.

### USB Host Configuration

| Setting | Value | Purpose |
| --- | --- | --- |
| `CFG_TUSB_RHPORT0_MODE` | `OPT_MODE_HOST` | USB host mode |
| `CFG_TUH_HID` | 4 | Up to 4 HID interfaces |
| `CFG_TUH_HUB` | 1 | USB hub support enabled |
| `CFG_TUH_DEVICE_MAX` | 4 | Up to 4 USB devices (with hub) |
| `CFG_TUH_ENUMERATION_BUFSIZE` | 512 | Larger buffer for gamepad descriptors |
| `CFG_TUH_HID_DEFAULT_PROTOCOL` | `HID_PROTOCOL_REPORT` | Report protocol (gamepads have no boot protocol) |

### HID Report Descriptor Parsing

When a USB HID device is mounted, the firmware receives its raw HID report descriptor — a compact binary encoding of the device's report format. The parser (`hid_gamepad_parser.c`) walks this descriptor to locate:

1. **Gamepad/Joystick collection**: The parser looks for a Collection with Usage Page `0x01` (Generic Desktop) and Usage `0x04` (Joystick) or `0x05` (Gamepad). Only fields inside this collection are processed.

2. **Hat switch**: Usage `0x39` (Hat Switch) in the Generic Desktop usage page. Standard 8-direction hats report values 0–7 for N/NE/E/SE/S/SW/W/NW, with the null state (no direction) at logical maximum + 1.

3. **X/Y axes**: Usages `0x30` (X) and `0x31` (Y) in the Generic Desktop usage page. These represent the left analog stick.

4. **Buttons**: Usage Page `0x09` (Button). Button 1 maps to Trigger A, Button 2 maps to Trigger B.

The parser tracks the global state (usage page, logical min/max, report size, report count, report ID) and local state (usages) as it walks the descriptor. For each Input item, it records the bit offset, bit size, and logical range of the field. This information is used at runtime to extract values from incoming HID reports.

If the descriptor does not contain a recognisable gamepad or joystick layout, the device is silently ignored.

### XInput Report Format

Xbox 360 wired controllers send a fixed 20-byte input report via an interrupt IN endpoint:

| Byte(s) | Field | Description |
| --- | --- | --- |
| 0 | Message type | `0x00` = input report |
| 1 | Message length | `0x14` (20) |
| 2–3 | Buttons | 16-bit digital button bitmap (little-endian) |
| 4 | Left trigger | 0–255 (analog) |
| 5 | Right trigger | 0–255 (analog) |
| 6–7 | Left stick X | Signed 16-bit (-32768 to 32767) |
| 8–9 | Left stick Y | Signed 16-bit (-32768 to 32767) |
| 10–11 | Right stick X | Signed 16-bit |
| 12–13 | Right stick Y | Signed 16-bit |
| 14–19 | Reserved | Padding |

**XInput button bitmap:**

| Bit | Button | MSX Mapping |
| --- | --- | --- |
| 0 | D-pad Up | Up (bit 0) |
| 1 | D-pad Down | Down (bit 1) |
| 2 | D-pad Left | Left (bit 2) |
| 3 | D-pad Right | Right (bit 3) |
| 4 | Start | — |
| 5 | Back | — |
| 6 | Left stick click | — |
| 7 | Right stick click | — |
| 8 | LB | — |
| 9 | RB | — |
| 10 | Guide | — |
| 12 | A | Trigger A (bit 4) |
| 13 | B | Trigger B (bit 5) |
| 14 | X | Trigger B (bit 5) |
| 15 | Y | — |

The Xbox left analog stick is also mapped to directions using a deadzone of approximately 25% (8192 out of 32768). The Y axis convention on XInput is positive = up, negative = down.

### Xbox One / Series X|S (GIP) Report Format

Xbox One controllers use the GIP (Game Input Protocol). Unlike Xbox 360 controllers, they require a 5-byte initialisation packet sent to the interrupt OUT endpoint before they start sending input reports:

```
Init packet: 0x05 0x20 0x00 0x01 0x00
```

The firmware sends this packet automatically during USB configuration.

GIP input reports are 18 bytes: a 4-byte GIP header followed by 14 bytes of gamepad payload:

| Byte(s) | Field | Description |
| --- | --- | --- |
| 0 | Command | `0x20` = input report |
| 1 | Client | Usually `0x00` |
| 2 | Sequence | Incrementing sequence number |
| 3 | Length | Payload length (`0x0E` = 14) |
| 4–5 | Buttons | 16-bit digital button bitmap (little-endian) |
| 6–7 | Left trigger | 0–1023 (10-bit range, 16-bit field) |
| 8–9 | Right trigger | 0–1023 |
| 10–11 | Left stick X | Signed 16-bit (-32768 to 32767) |
| 12–13 | Left stick Y | Signed 16-bit (-32768 to 32767) |
| 14–15 | Right stick X | Signed 16-bit |
| 16–17 | Right stick Y | Signed 16-bit |

**Xbox One button bitmap** (different layout from Xbox 360!):

| Bit | Button | MSX Mapping |
| --- | --- | --- |
| 0 | Sync | — |
| 2 | Menu (Start) | — |
| 3 | View (Back) | — |
| 4 | A | Trigger A (bit 4) |
| 5 | B | Trigger B (bit 5) |
| 6 | X | Trigger B (bit 5) |
| 7 | Y | — |
| 8 | D-pad Up | Up (bit 0) |
| 9 | D-pad Down | Down (bit 1) |
| 10 | D-pad Left | Left (bit 2) |
| 11 | D-pad Right | Right (bit 3) |
| 12 | LB | — |
| 13 | RB | — |
| 14 | Left Stick Click | — |
| 15 | Right Stick Click | — |

The left analog stick deadzone and mapping are identical to the Xbox 360 driver.

---

## Input Mapping

### D-Pad (Hat Switch)

The hat switch is an 8-direction digital input. The standard encoding maps to MSX directions as follows:

| Hat Value | Direction | MSX Bits Cleared |
| --- | --- | --- |
| 0 | North | Bit 0 (Up) |
| 1 | North-East | Bit 0 + Bit 3 (Up + Right) |
| 2 | East | Bit 3 (Right) |
| 3 | South-East | Bit 1 + Bit 3 (Down + Right) |
| 4 | South | Bit 1 (Down) |
| 5 | South-West | Bit 1 + Bit 2 (Down + Left) |
| 6 | West | Bit 2 (Left) |
| 7 | North-West | Bit 0 + Bit 2 (Up + Left) |
| 8+ / null | Centred | None (all direction bits remain HIGH) |

Diagonal directions set two bits simultaneously, matching the behavior of a real joystick where two switches are closed at the same time.

### Analog Stick

The left analog stick's X and Y axes are mapped to digital directions using a centre-relative deadzone:

1. The firmware calculates the centre point as `logical_min + range / 2`.
2. A deadzone threshold is computed as `range × deadzone_percent / 200` (default: 25%).
3. If the stick deflection exceeds the threshold in any direction, the corresponding MSX direction bit is cleared.

The analog stick and hat switch inputs are combined with a logical AND (both active-low), so either input source can activate a direction. This means a gamepad with both a D-pad and an analog stick can use either one interchangeably.

### Trigger Buttons

| USB Button | MSX Function | PSG R14 Bit |
| --- | --- | --- |
| Button 1 (first in descriptor) | Trigger A | Bit 4 |
| Button 2 (second in descriptor) | Trigger B | Bit 5 |

Button numbering follows the order buttons appear in the HID report descriptor. On most gamepads, Button 1 is the primary face button (e.g. "A" on Xbox controllers, "Cross" on PlayStation controllers).

### Complete MSX Joystick Byte

The output is an active-low byte matching the PSG register 14 format:

| Bit | Signal | Value when pressed | Value when released |
| --- | --- | --- | --- |
| 0 | Up | 0 | 1 |
| 1 | Down | 0 | 1 |
| 2 | Left | 0 | 1 |
| 3 | Right | 0 | 1 |
| 4 | Trigger A | 0 | 1 |
| 5 | Trigger B | 0 | 1 |
| 6 | (unused) | 1 (tri-stated) | 1 (tri-stated) |
| 7 | (unused) | 1 (tri-stated) | 1 (tri-stated) |

When no gamepad is connected or no buttons are pressed, the state is `0xFF` (all released), which is electrically invisible on the bus due to the open-drain driving.

---

## Two-Port Support

The firmware supports up to two USB gamepads simultaneously, mapped to MSX joystick ports 1 and 2:

- The **first gamepad** connected is assigned to MSX port 1.
- The **second gamepad** connected is assigned to MSX port 2.
- Additional gamepads beyond two are silently ignored (no free MSX port).

The MSX software selects which port to read via PSG register 15 bit 6. The firmware tracks this bit from `OUT (0xA1)` writes and responds with the corresponding port's state when R14 is read.

When a gamepad is disconnected, its MSX port state is reset to `0xFF` (all released) and the port becomes available for a new gamepad. Up to 4 simultaneous USB HID interfaces are supported (via hubs), but only 2 can be mapped to MSX joystick ports.

---

## Concurrency and Data Sharing

The `joystick_state[2]` array is shared between Core 1 (writer, from USB gamepad reports) and Core 0 (reader, from PIO IRQ handler). Each element is a single `volatile uint8_t`, and updates are bracketed with `__dmb()` (data memory barrier) calls to ensure cross-core visibility.

The `psg_register_latch` and `joystick_port_sel` variables are written only by Core 0 (IRQ handler) and read only by Core 0, so no cross-core synchronisation is needed for them.

---

## FIFO Protocol

### I/O Read (SM0 → Core 0 → SM0)

1. SM0 detects `/IORQ=0` + `/RD=0`, asserts `/WAIT`, captures A0–A15, pushes 16-bit address to RX FIFO.
2. Core 0 IRQ handler reads the address. If port is `0xA2` and the register latch is 14, it pushes an open-drain response token: `data=0x00`, `pindirs=~joystick_state[port_sel] & 0x3F`.
3. For any other register or port, the handler pushes a tri-state token: `data=0xFF`, `pindirs=0x00`.
4. SM0 drives D0–D7 with the data and pindirs, releases `/WAIT`, waits for `/RD` deassert, then tri-states.

### I/O Write (SM1 → Core 0)

1. SM1 detects `/IORQ=0` + `/WR=0`, waits 3 PIO cycles for address and data lines to settle, snapshots all GPIOs via `mov isr, pins`, pushes 32-bit word to RX FIFO.
2. Core 0 IRQ handler extracts `port = bits[7:0]` and `data = bits[23:16]`.
3. Port `0xA0` → updates the register latch. Port `0xA1` with latch at 15 → updates the port select bit (bit 6 of the written data).

---

## GPIO Assignments

| GPIO Range | Signal | Direction |
| --- | --- | --- |
| 0–15 | A0–A15 (address bus) | Input |
| 16–23 | D0–D7 (data bus) | Bidirectional (PIO-controlled) |
| 24 | /RD | Input |
| 25 | /WR | Input |
| 26 | /IORQ | Input |
| 27 | /SLTSL | Input (unused — joystick uses I/O ports only) |
| 28 | /WAIT | Output (PIO side-set, active-low) |
| 29 | BUSSDIR | Input (unused) |

---

## Build System

The joystick firmware is built as part of the `loadrom.pio` aggregate Makefile:

```
make joystick       # Build only the joystick firmware
make all            # Builds all firmwares including joystick
make clean          # Cleans all firmware builds including joystick
```

The build produces `pico/joystick/dist/joystick.bin`, which is converted to a C header (`tool/src/joystick_fw.h`) and embedded in the `loadrom` PC tool. The tool generates a UF2 file for flashing:

```
loadrom -j -o joystick.uf2
```

The `-j` / `--joystick` option is standalone and cannot be combined with ROM loading options or other standalone firmware modes (`-k`, `-i`, `-p`).

---

## Source Files

| File | Purpose |
| --- | --- |
| `pico/joystick/joystick.h` | Pin definitions, PSG port/register constants, joystick bit assignments, deadzone setting |
| `pico/joystick/msx_joystick.pio` | PIO assembly for I/O read responder (with `/WAIT`) and I/O write captor |
| `pico/joystick/joystick_main.c` | Main firmware: PIO IRQ handler, GPIO/PIO init, gamepad management, TinyUSB callbacks, dual-core entry points |
| `pico/joystick/hid_gamepad_parser.h` | Public API for HID report descriptor parsing and joystick extraction |
| `pico/joystick/hid_gamepad_parser.c` | HID descriptor walker, hat/axis/button field extraction, deadzone calculation |
| `pico/joystick/xinput_host.h` | Xbox 360 (XInput) and Xbox One (GIP) protocol definitions, report structures, button constants |
| `pico/joystick/xinput_host.c` | TinyUSB custom class driver for Xbox 360, Xbox One, and Xbox Series X\|S controllers |
| `pico/joystick/tusb_config.h` | TinyUSB host configuration (report protocol, 4 HID interfaces, hub support) |
| `pico/joystick/CMakeLists.txt` | CMake build configuration |
| `pico/joystick/pico_sdk_import.cmake` | Pico SDK import helper |
| `tool/src/joystick_fw.h` | Generated header with embedded firmware binary |

---

## Limitations and Notes

- **Bus contention on R14 reads**: The open-drain technique minimises but does not completely eliminate electrical stress. When a USB button is pressed, the RP2040 pulls a data line LOW while the PSG tries to drive it HIGH. In practice this is safe because the PSG's output drivers are relatively weak and the RP2040's sink current is within the PSG's specifications, but it is a departure from the ideal where only one device drives the bus. Sound output from the PSG is unaffected because PSG registers 0–13 are read/written normally.

- **No physical joystick passthrough**: The firmware does not read the physical DE-9 joystick ports. If a real joystick is also connected to the MSX, the PSG will report the logical AND (active-low) of both the real joystick and the USB gamepad, which effectively means both inputs work simultaneously — pressing a direction on either device activates it.

- **Gamepad compatibility**: Not all USB gamepads will be recognised. The firmware supports three USB gamepad families: standard USB HID gamepads (via HID report descriptor parsing), Xbox 360 / XInput controllers (via vendor-specific class `0xFF`/`0x5D`/`0x01`), and Xbox One / Series X|S controllers (via GIP protocol, class `0xFF`/`0x47`/`0xD0`). Proprietary protocols not covered by any of these drivers (e.g. PlayStation DualSense via Bluetooth, some older wireless adapters) may not be recognised. Wired USB gamepads that present a standard HID gamepad descriptor, an XInput interface, or a GIP interface should work.

- **Analog deadzone**: The 25% deadzone is compiled into the firmware. To change it, modify `DEADZONE_PERCENT` in `joystick.h` and rebuild.

- **Report ID handling**: If the gamepad uses HID report IDs, the firmware strips the first byte of each incoming report before parsing. Multi-report-ID devices where the gamepad data is not in the first report ID may not work correctly.

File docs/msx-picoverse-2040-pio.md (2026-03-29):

# MSX PicoVerse 2040 PIO Bus Strategy

This document describes the RP2040 PIO strategy used by PicoVerse 2040 firmware targets:

- `2040/software/loadrom.pio`
- `2040/software/multirom.pio`

Both reuse the same bus-engine architecture and differ mainly in workflow (single-ROM vs menu-driven multi-ROM).

---

## 1) Core Strategy

| Owner | Responsibility |
|---|---|
| **PIO** | Detect slot read/write cycles, assert `/WAIT`, capture address/data, drive/release data bus |
| **CPU** | Drain/fill FIFOs, apply mapper bank translation, return ROM bytes |

The key goal is deterministic bus timing while allowing mapper logic to run in C without violating Z80 timing.

---

## 2) PIO Architecture (Shared by LoadROM and MultiROM)

Both firmware targets use two state machines on `pio0`:

| SM | Program | Role |
|---|---|---|
| `SM0` | `msx_read_responder` | Handles `/RD` cycles, controls `/WAIT`, captures address, outputs tokenized data |
| `SM1` | `msx_write_captor` | Handles `/WR` cycles, captures address+data for mapper updates |

### Why `jmp pin` polling is used

Both programs use the race-safe pattern:

- wait for `/SLTSL` low
- poll `/RD` or `/WR` with `jmp pin` while re-checking slot selection

This avoids stale-slot race conditions that can cause false reads/writes after deselection.

---

## 3) RP2040 Pin Map

| GPIO | Signal |
|---|---|
| 0–15 | A0–A15 |
| 16–23 | D0–D7 |
| 24 | `/RD` |
| 25 | `/WR` |
| 26 | `/IORQ` |
| 27 | `/SLTSL` |
| 28 | `/WAIT` |
| 29 | `BUSSDIR` |

---

## 4) FIFO Contract

### Write captor word (`SM1 -> CPU`)

- `bits[15:0]` = address A0..A15
- `bits[23:16]` = data D0..D7

### Read response token (`CPU -> SM0`)

- `bits[7:0]` = data byte
- `bits[15:8]` = pin-direction mask (`0xFF` drive, `0x00` tri-state)

---

## 5) ROM Serving Strategy

- Uses a 192 KB SRAM cache when enabled.
- Small ROMs are fully cached.
- Large ROMs use SRAM-first + flash XIP fallback.
- `/WAIT` stretching covers CPU lookup latency.

Supported mappers in PIO paths include:

- Plain16 / Plain32 (`PLA-16` / `PLA-32`)
- Planar48 / Planar64 (`PLN-48` / `PLN-64`)
- Konami SCC
- Konami
- ASCII8 / ASCII16
- ASCII16-X (type 12)
- NEO8 / NEO16
- Sunrise IDE Nextor (type 10)
- Sunrise IDE Nextor + 192KB mapper (type 11)

---

## 6) LoadROM vs MultiROM on 2040

| Area | `loadrom.pio` | `multirom.pio` |
|---|---|---|
| Runtime | Single ROM from one record | Menu ROM first, then selected ROM from record table |
| Menu monitor write | N/A | Captured through `SM1` to detect selected entry |
| Lifecycle | One main flow | Re-initializes SM/FIFO state between menu and selected-ROM phases |
| Mapper set | 1..13 (`12` = ASCII16-X, `13` = Planar64) | 1..13 (`10` = Sunrise IDE Nextor, `11` = Sunrise IDE Nextor + 192KB mapper, `12` = ASCII16-X, `13` = Planar64) |

---

## 7) Build Integration

Both RP2040 PIO firmware targets require:

- `pico_generate_pio_header(... msx_bus.pio)`
- `hardware_pio`
- `hardware_dma`

---

## 8) Keyboard PIO Architecture

The `loadrom.pio` build also includes a standalone USB keyboard firmware (`pico/keyboard/`) that uses a separate pair of PIO programs on **PIO1**:

| SM | Program | Role |
|---|---|---|
| SM0 | `msx_kb_io_read` | I/O read responder with `/WAIT` side-set — intercepts port `0xA9` reads and freezes the Z80 until Core 0 supplies keyboard column data |
| SM1 | `msx_kb_io_write` | I/O write captor — captures port `0xAA` and `0xAB` writes for keyboard row selection |

The keyboard PIO programs share the same pin map as the ROM-serving PIO but operate exclusively on I/O bus signals (`/IORQ`, `/RD`, `/WR`) rather than slot memory (`/SLTSL`). The read responder uses optional side-set on GPIO 28 (`/WAIT`) to hold the Z80 during the FIFO round-trip.

See [MSX PicoVerse 2040 USB Keyboard](/docs/msx-picoverse-2040-keyboard.md) for the full keyboard architecture documentation.

---

## 9) Joystick PIO Architecture

The `loadrom.pio` build also includes a standalone USB joystick firmware (`pico/joystick/`) that uses a separate pair of PIO programs on **PIO1**:

| SM | Program | Role |
|---|---|---|
| SM0 | `msx_joy_io_read` | I/O read responder with `/WAIT` side-set — intercepts port `0xA2` reads and freezes the Z80 until Core 0 supplies joystick data via an open-drain response token |
| SM1 | `msx_joy_io_write` | I/O write captor — captures port `0xA0` (register latch) and `0xA1` (R15 port-select) writes for PSG register tracking |

The joystick PIO programs share the same pin map as the ROM-serving PIO but operate exclusively on I/O bus signals (`/IORQ`, `/RD`, `/WR`) rather than slot memory (`/SLTSL`). The read responder uses optional side-set on GPIO 28 (`/WAIT`) to hold the Z80 during the FIFO round-trip. Unlike other PIO firmwares, the joystick read response uses an open-drain technique: the pin-direction mask selectively drives pressed buttons LOW while tri-stating released buttons, allowing the real PSG chip to continue driving those lines undisturbed.

See [MSX PicoVerse 2040 USB Joystick](/docs/msx-picoverse-2040-joystick.md) for the full joystick architecture documentation.

---

Cristiano Goncalves  
03/29/26

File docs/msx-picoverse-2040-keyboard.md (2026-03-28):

# MSX PicoVerse 2040 USB Keyboard

This document describes the standalone USB keyboard firmware for the PicoVerse 2040 cartridge. The firmware turns the cartridge into a dedicated USB-to-MSX keyboard interface: plug a standard USB keyboard into the cartridge's USB-C port and it appears as the native MSX keyboard to the host system.

> **Compatibility Notice**: The keyboard firmware does **not** work with FPGA-based MSX systems (e.g. OCM/1chipMSX, uMSX, TRHMSX, SM-X, Zemmix Neo, etc.) or MSX computers whose PPI is integrated into a custom chip (e.g. Panasonic models using the T9769 MSX-ENGINE). In both cases, the PPI keyboard ports (`0xA8`–`0xAB`) are decoded and handled internally by the FPGA or MSX-ENGINE, so the I/O read data bus is actively driven by the on-chip PPI logic, causing bus contention with the PicoVerse. See the [FPGA Incompatibility Details](#fpga-incompatibility-details) section below for a full technical explanation.

---

## Overview

The MSX keyboard is a passive 11-row × 8-column matrix scanned by the 8255 PPI (Programmable Peripheral Interface). The BIOS selects a row by writing to I/O port `0xAA` or `0xAB`, then reads the column state from port `0xA9`. The PicoVerse keyboard firmware intercepts these three I/O ports and responds with key states derived from USB HID keyboard reports received over USB-C.

### Intercepted I/O Ports

| Port | Direction | Purpose |
| --- | --- | --- |
| `0xA9` | IN (Z80 reads) | Returns column data for the currently selected keyboard row |
| `0xAA` | OUT (Z80 writes) | Selects the active keyboard row (PPI port C full write) |
| `0xAB` | OUT (Z80 writes) | PPI port C bit set/reset register — the MSX BIOS uses this to change individual row-select bits without rewriting all of port C |

### Key Features

- Fully standalone: does not require any MSX-side software or driver.
- Supports USB HID boot-protocol keyboards, including keyboards connected through USB hubs.
- Full MSX keyboard matrix coverage: rows 0–10, including alphanumeric keys, function keys, cursor keys, numpad, and all MSX-specific keys (GRAPH, CODE, SELECT, STOP).
- USB modifier keys are mapped to MSX equivalents: Shift, Ctrl, Left Alt → GRAPH, Right Alt → CODE, Caps Lock → CAPS.
- Up to 6 simultaneous key presses (USB boot protocol limit) plus modifier keys.
- Runs at 250 MHz for minimal response latency.

---

## Architecture

The firmware uses both cores of the RP2040 and a dedicated pair of PIO state machines on PIO1.

### Dual-Core Design

| Core | Role |
| --- | --- |
| **Core 0** | Services PIO1 IRQ. The IRQ fires when the I/O read or write PIO state machine has data in its RX FIFO. The handler processes port writes (`0xAA`, `0xAB`) to track the selected keyboard row, and port reads (`0xA9`) to supply the column data. Between interrupts, Core 0 sleeps via `__wfi()`. |
| **Core 1** | Runs the TinyUSB host stack. Calls `tuh_task()` in a tight loop to poll for USB events. When a HID keyboard report arrives, the callback converts it to MSX matrix format and updates the shared `keys[]` array. |

### PIO State Machines (PIO1)

| SM | Program | Role |
| --- | --- | --- |
| SM0 | `msx_kb_io_read` | Monitors `/IORQ` + `/RD`. When an I/O read cycle begins, asserts `/WAIT` (side-set), captures the 16-bit address, pushes it to the RX FIFO, then stalls on `pull block` until Core 0 supplies the response byte. Drives D0–D7, releases `/WAIT`, waits for `/RD` to deassert, then tri-states the data bus. |
| SM1 | `msx_kb_io_write` | Monitors `/IORQ` + `/WR`. Captures a full 32-bit GPIO snapshot (`mov isr, pins`) containing address and data, pushes it to the RX FIFO for Core 0 to decode. No `/WAIT` assertion needed for writes. |

### `/WAIT` Signal

The `/WAIT` line (active-low, active on GPIO 28) freezes the Z80 while the RP2040 prepares the keyboard data. The PIO read program uses side-set to control `/WAIT`:

- **`side 0`** = `/WAIT` asserted (Z80 frozen)
- **`side 1`** = `/WAIT` released (Z80 runs)

Without `/WAIT`, the Z80 completes an I/O read in 3–4 T-cycles (~840–1120 ns at 3.58 MHz), which is not enough time for the push/pull FIFO round-trip. Asserting `/WAIT` guarantees the CPU receives correct data regardless of firmware processing time.

During initialisation, the firmware pre-sets the PIO output register for the `/WAIT` pin to HIGH before switching the GPIO mux to PIO control. This prevents a brief glitch where `/WAIT` could be driven LOW (freezing the Z80) between the `pio_gpio_init()` call and the first PIO instruction executing.

---

## MSX Keyboard Matrix

The MSX standard keyboard matrix has 11 rows (0–10) with 8 columns each. Each bit in a row byte represents one key: `1` = released, `0` = pressed (active-low).

### Matrix Layout

| Row | Bit 7 | Bit 6 | Bit 5 | Bit 4 | Bit 3 | Bit 2 | Bit 1 | Bit 0 |
| --- | --- | --- | --- | --- | --- | --- | --- | --- |
| 0 | 7 | 6 | 5 | 4 | 3 | 2 | 1 | 0 |
| 1 | ; | ] | [ | \ | = | - | 9 | 8 |
| 2 | B | A | — | / | . | , | \` | ' |
| 3 | J | I | H | G | F | E | D | C |
| 4 | R | Q | P | O | N | M | L | K |
| 5 | Z | Y | X | W | V | U | T | S |
| 6 | F3 | F2 | F1 | CODE | CAPS | GRAPH | CTRL | SHIFT |
| 7 | RETURN | SELECT | BS | STOP | TAB | ESC | F5 | F4 |
| 8 | RIGHT | DOWN | UP | LEFT | DEL | INS | HOME | SPACE |
| 9 | NUM4 | NUM3 | NUM2 | NUM1 | NUM0 | NUM/ | NUM+ | NUM* |
| 10 | NUM. | — | NUM- | NUM9 | NUM8 | NUM7 | NUM6 | NUM5 |

### USB HID to MSX Key Mapping

USB HID boot protocol reports are 8 bytes:

| Byte | Content |
| --- | --- |
| 0 | Modifier flags (Ctrl, Shift, Alt, GUI — left and right) |
| 1 | Reserved (always 0) |
| 2–7 | Up to 6 simultaneous HID key codes |

The firmware maps modifiers and keycodes as follows:

**Modifier Mapping (byte 0 bitmask):**

| USB Modifier | MSX Key | Row | Bit |
| --- | --- | --- | --- |
| Left Shift (bit 1) or Right Shift (bit 5) | SHIFT | 6 | 0 |
| Left Ctrl (bit 0) or Right Ctrl (bit 4) | CTRL | 6 | 1 |
| Left Alt (bit 2) | GRAPH | 6 | 2 |
| Right Alt (bit 6) | CODE | 6 | 4 |

**Notable Non-Obvious Key Assignments:**

| USB Key | HID Code | MSX Key |
| --- | --- | --- |
| Page Up | `0x4B` | STOP |
| End | `0x4D` | SELECT |
| Home | `0x4A` | HOME |
| Insert | `0x49` | INS |
| Delete | `0x4C` | DEL |
| Caps Lock | `0x39` | CAPS |
| Numpad Enter | `0x58` | RETURN |

---

## Port 0xAB Bit Set/Reset Handling

The MSX BIOS frequently uses port `0xAB` instead of `0xAA` to change the keyboard row. Port `0xAB` is the 8255 PPI port C bit set/reset register:

- **Bit 7** = 1 indicates set/reset mode is active.
- **Bits 3–1** encode the bit number (0–7) within port C.
- **Bit 0** is the value to write (1 = set, 0 = reset).

The keyboard row is stored in the lower nibble of PPI port C (bits 0–3). The firmware tracks the current row state and applies individual bit modifications when port `0xAB` writes arrive, mimicking the behavior of a real 8255 PPI.

---

## GPIO Initialisation

Before the PIO state machines are configured, all 30 MSX bus GPIOs are explicitly initialised:

| GPIO Range | Signal | Initial Direction |
| --- | --- | --- |
| 0–15 | A0–A15 | Input |
| 16–23 | D0–D7 | Input (PIO takes control later) |
| 24 | /RD | Input |
| 25 | /WR | Input |
| 26 | /IORQ | Input |
| 27 | /SLTSL | Input (unused by keyboard) |
| 28 | /WAIT | Output, driven HIGH |
| 29 | BUSSDIR | Input (unused — hardware uses BSS138 bidirectional level shifters) |

Setting `/WAIT` HIGH via the SIO pad controller before PIO takes ownership ensures the Z80 is never inadvertently frozen during boot.

---

## USB Host Configuration

The firmware uses TinyUSB in USB Host mode with the following configuration:

| Setting | Value | Purpose |
| --- | --- | --- |
| `CFG_TUSB_RHPORT0_MODE` | `OPT_MODE_HOST` | USB host mode |
| `CFG_TUH_HID` | 4 | Up to 4 HID interfaces |
| `CFG_TUH_HUB` | 1 | USB hub support enabled |
| `CFG_TUH_DEVICE_MAX` | 4 | Up to 4 USB devices (with hub) |
| `CFG_TUH_HID_DEFAULT_PROTOCOL` | `HID_PROTOCOL_BOOT` | Force boot protocol during enumeration |

The `CFG_TUH_HID_DEFAULT_PROTOCOL` setting is critical: it tells TinyUSB to request boot protocol during USB enumeration. Boot protocol guarantees the fixed 8-byte report format that the firmware's key mapper expects. Without this setting, keyboards may enumerate in report protocol where the report format is defined by the HID report descriptor and varies between manufacturers, which would cause silent key mapping failures.

On mount, the firmware checks `tuh_hid_interface_protocol()` and only starts receiving reports from `HID_ITF_PROTOCOL_KEYBOARD` interfaces. On unmount, the keyboard matrix is reset to all-keys-released.

---

## Concurrency and Data Sharing

The `keys[16]` array is shared between Core 1 (writer, from USB reports) and Core 0 (reader, from PIO IRQ handler). Updates use a snapshot pattern:

1. Core 1 builds a complete `new_keys[16]` array from the latest HID report.
2. A `__dmb()` (data memory barrier) is issued before and after `memcpy()` to ensure the entire array is visible atomically to Core 0.

The `keyboard_row` variable is written only by Core 0 (IRQ handler) and read only by Core 0, so no cross-core synchronisation is needed for it.

---

## FIFO Protocol

### I/O Read (SM0 → Core 0 → SM0)

1. SM0 detects `/IORQ=0` + `/RD=0`, asserts `/WAIT`, captures A0–A15, pushes 16-bit address to RX FIFO.
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

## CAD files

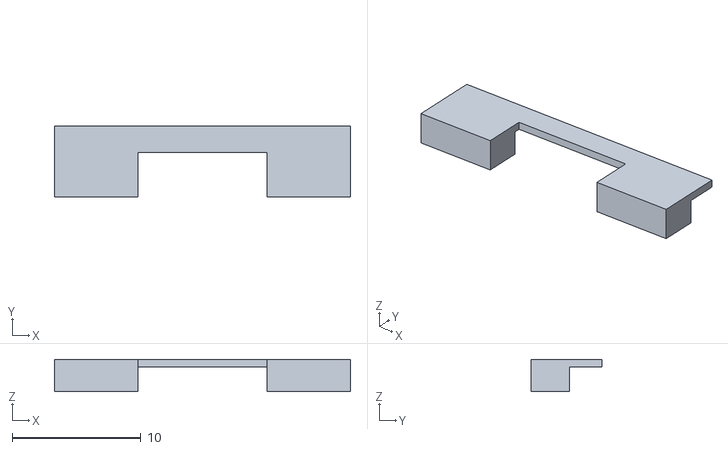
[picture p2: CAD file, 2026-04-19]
2040/case/PicoVerse_2040_1.41_label_holder.stl
23.0 x 5.50 x 2.50

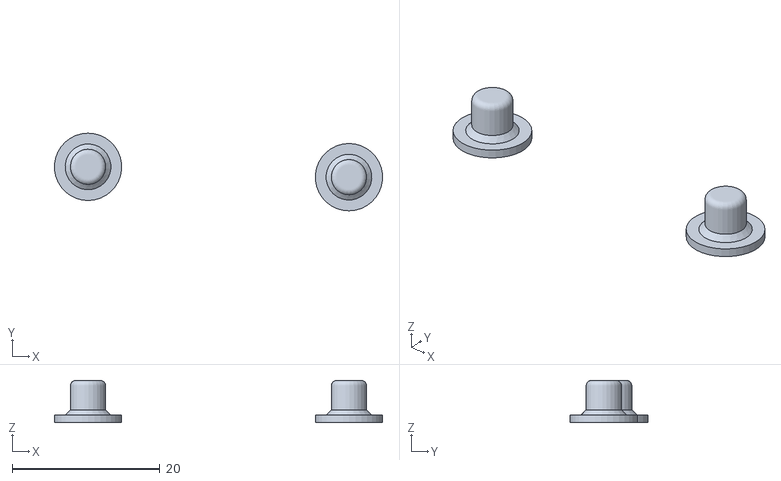
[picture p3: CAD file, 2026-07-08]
2350/case/PicoVerse_2350_1.1_Paco_boton 4mm.stl
44.4 x 10.5 x 5.70

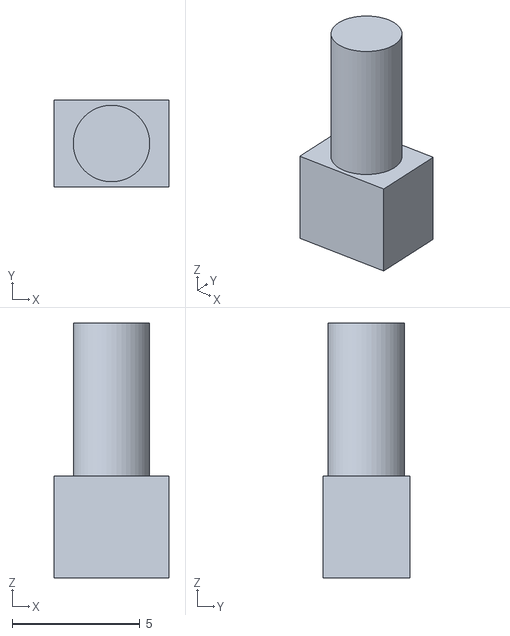
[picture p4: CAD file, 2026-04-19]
2040/case/PicoVerse_2040_1.41_button.stl
4.50 x 3.40 x 10.0

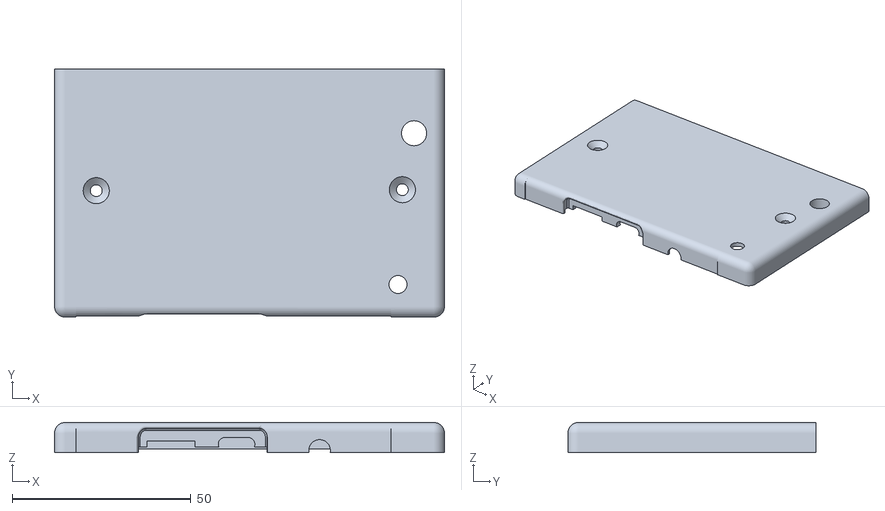
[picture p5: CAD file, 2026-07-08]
2350/case/Cartouche_MSX_V2_FLAT_PICOVERSE_2350_1.0_B.obj
109.0 x 69.4 x 8.40

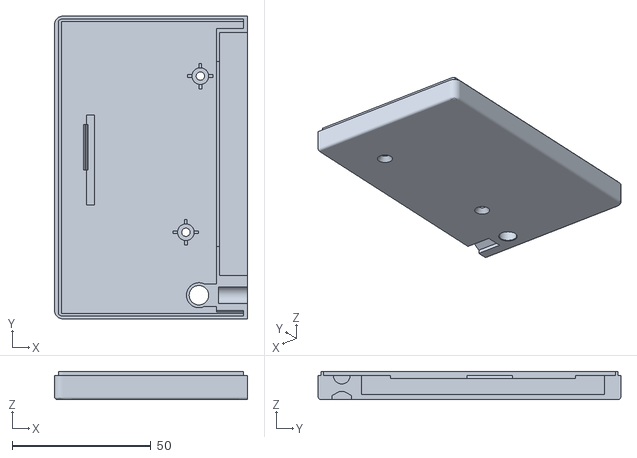
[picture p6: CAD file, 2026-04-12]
2040/case/PicoVerse_2040_side1_pakoto.stl
69.5 x 109.0 x 10.1

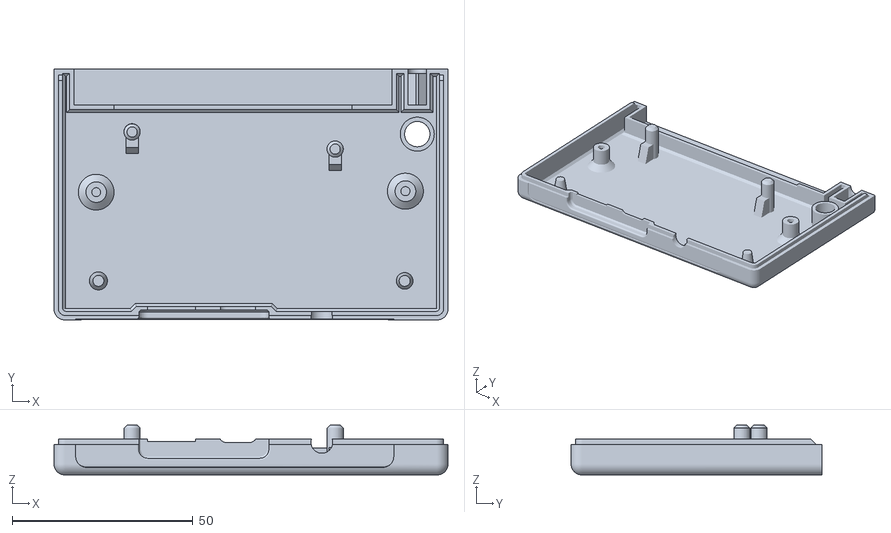
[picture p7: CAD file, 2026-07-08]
2350/case/Cartouche_MSX_V2_FLAT_PICOVERSE_2350_1.0_A.obj
109.0 x 69.4 x 13.8

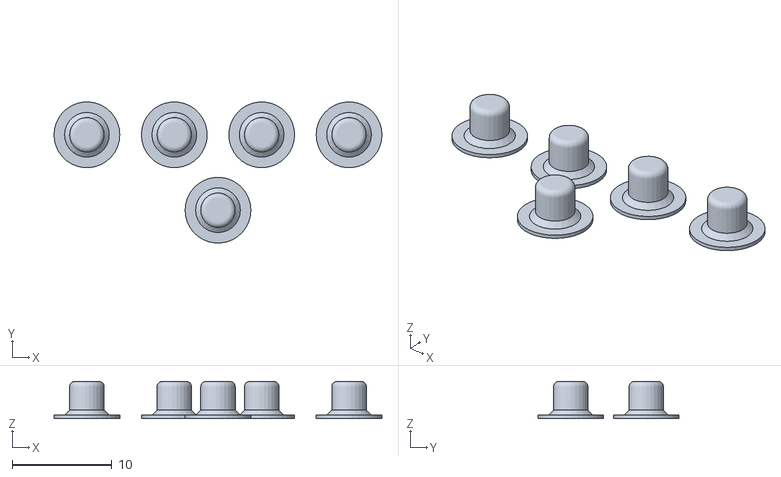
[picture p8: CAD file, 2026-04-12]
2040/case/PicoVerse_2040_button_pakoto.stl
32.9 x 14.1 x 3.71

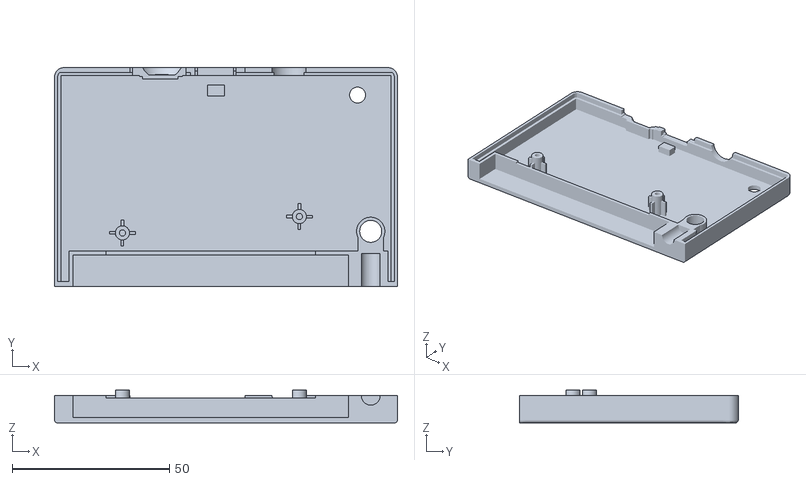
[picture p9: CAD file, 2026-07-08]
2350/case/PicoVerse_2350_1.1_Paco_top.stl
109.0 x 69.5 x 10.4

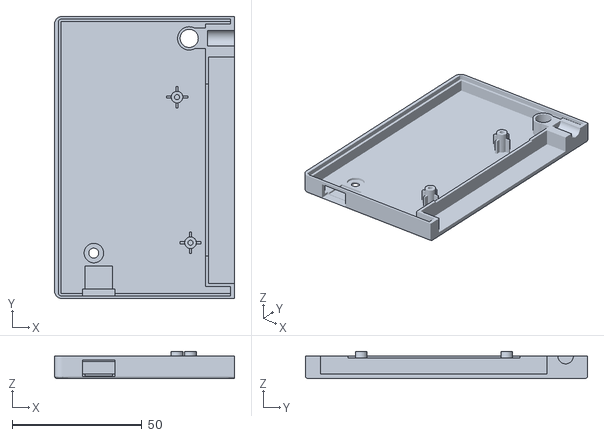
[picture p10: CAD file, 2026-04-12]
2040/case/PicoVerse_2040_side2_pakoto.stl
69.5 x 109.0 x 10.5

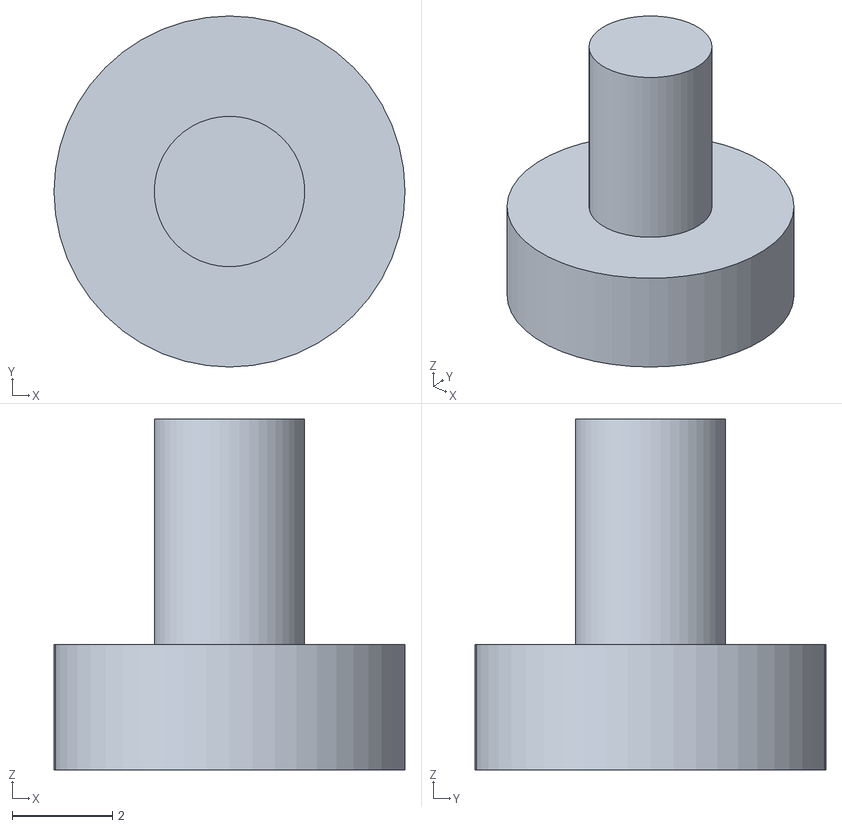
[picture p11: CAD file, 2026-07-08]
2350/case/PicoVerse_2350_button.stl
7.00 x 7.00 x 7.00

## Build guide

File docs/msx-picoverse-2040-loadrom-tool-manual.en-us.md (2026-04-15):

# MSX PicoVerse 2040 LoadROM Tool Manual (en-US)

The PicoVerse 2040 cartridge extends MSX systems by flashing different Raspberry Pi Pico firmwares. While the MultiROM firmware offers a menu-driven launcher, some workflows require flashing a single ROM image that boots immediately on power‑on. That is the purpose of the `loadrom` firmware and of the companion `loadrom.exe` console tool documented here.

`loadrom.exe` bundles the Pico firmware, a configuration record (game name, mapper code, ROM size and offset), and a single MSX ROM payload into an RP2040-compatible UF2 image. Copying the generated UF2 to the Pico’s `RPI-RP2` drive programs the cartridge so that it boots directly into the embedded ROM whenever the MSX starts.

Alternatively, the `-s` (Sunrise) option can be used to flash the cartridge with the Sunrise IDE Nextor firmware, which exposes the USB-C port as a block device for use with Nextor-compatible loaders like SofaRun.

The `-m` option flashes Sunrise IDE Nextor with an additional 192KB memory mapper implementation. In the firmware internals this is mapper mode (type `11`), while on-screen mapper text is still presented as `SYSTEM` for end users.

The standalone firmware options `-k`, `-i`, `-p`, and `-j` generate dedicated USB keyboard, MSX-MIDI, MIDI-PAC PSG-to-MIDI converter, and USB joystick cartridges without embedding a ROM payload.

### LoadRom option matrix

| Option | Nextor ROM | Extra mapper RAM | Intended use |
| --- | --- | --- | --- |
| `-s` | Sunrise IDE Nextor | No | Standard Nextor USB mass-storage mode |
| `-m` | Sunrise IDE Nextor | Yes, 192KB | Nextor workflows that need mapper-capable behavior |
| `-k` | — | — | Standalone USB keyboard cartridge mode |
| `-i` | — | — | Standalone MSX-MIDI cartridge mode (USB MIDI interface) |
| `-p` | — | — | Standalone MIDI-PAC cartridge mode (passive PSG-to-MIDI converter) |
| `-j` | — | — | Standalone USB joystick cartridge mode (USB gamepad to MSX joystick via PSG) |
## Overview

1. **Input**: one `.ROM` file (case-insensitive extension) supplied via the command line.
2. **Processing**: the tool trims/normalizes the ROM name, detects or forces the mapper type, and streams the Pico firmware, configuration record, and ROM payload into UF2 blocks.
3. **Output**: a UF2 file (default `loadrom.uf2`) that can be copied to the Pico while it is in BOOTSEL mode.

Key characteristics:

- Works on Windows (console app). Tested in `cmd.exe` and PowerShell.
- Supports ROM sizes from 8 KB up to 16 MB (subject to Pico flash capacity).
- Detects common mapper types automatically. Mapper can be forced via filename tags (same scheme as `multirom`): `PLA-16`, `PLA-32`, `KonSCC`, `PLN-48`, `ASC-08`, `ASC-16`, `ASC-16X`, `Konami`, `NEO-8`, `NEO-16`, `PLN-64`, `MANBW2`.
- Space Manbow 2 ROMs (512 KB, Konami SCC + AMD flash) are auto-detected. The `MANBW2` tag (aliases `MANBOW2`, `MBW-2`) can also force this mapper.
- Generates UF2 files recognized by the RP2040 ROM bootloader (sets the RP2040 family ID flag).

## Command-line usage

Only the Windows executable is currently distributed.

### Basic syntax

```
loadrom.exe [options] [romfile]
```

### Options

- `-h`, `--help` : Print usage information and exit.
- `-s`, `--sunrise` : Embed the Sunrise IDE Nextor ROM instead of a regular MSX ROM. When this option is used, the cartridge boots into Nextor firmware, and the USB-C port exposes a block device for use with Nextor loaders. No ROM file argument is needed with this option.
- `-m`, `--mapper` : Embed Sunrise IDE Nextor with 192KB memory mapper support. This is intended for Nextor workflows that require mapper-capable behavior. No ROM file argument is needed with this option.
- `-k`, `--keyboard` : Build a UF2 with the standalone USB keyboard firmware. The cartridge becomes a dedicated USB-to-MSX keyboard interface. This option is standalone and cannot be combined with `-s`, `-m`, `-i`, `-p`, `-j`, or a ROM file.
- `-i`, `--midi` : Build a UF2 with the standalone MSX-MIDI firmware. The cartridge becomes a dedicated MSX-MIDI interface that bridges MSX-MIDI I/O ports (`0xE8`–`0xE9`) to a USB MIDI device connected to the USB-C port. This option is standalone and cannot be combined with `-s`, `-m`, `-k`, `-p`, `-j`, or a ROM file.
- `-p`, `--midipac` : Build a UF2 with the standalone MIDI-PAC firmware. The cartridge becomes a passive PSG-to-MIDI converter that listens to AY-3-8910 / YM2149 PSG writes on ports `0xA0`–`0xA1` and forwards a musical MIDI interpretation to a USB MIDI device connected to the USB-C port. This option is standalone and cannot be combined with `-s`, `-m`, `-k`, `-i`, `-j`, or a ROM file.
- `-j`, `--joystick` : Build a UF2 with the standalone USB joystick firmware. The cartridge becomes a dedicated USB-to-MSX joystick adapter that intercepts PSG I/O ports (`0xA0`–`0xA2`) and overlays USB gamepad input onto the joystick bits of PSG register 14 using open-drain bus driving. Supports generic USB HID gamepads, Xbox 360 / XInput controllers, and Xbox One / Series X|S controllers, with up to 2 gamepads mapped to MSX joystick ports 1 and 2. This option is standalone and cannot be combined with `-s`, `-m`, `-k`, `-i`, `-p`, or a ROM file.
- `-o <filename>`, `--output <filename>` : Override the UF2 output name (default `loadrom.uf2`).
- Positional argument: the path to the MSX ROM you wish to embed (not used with `-s`, `-m`, `-k`, `-i`, `-p`, or `-j`).

### Mapper forcing via filename tags

`loadrom.exe` shares the same forcing mechanism as the MultiROM tool. Append a dot-separated mapper tag before the `.ROM` extension to override detection:

```
Penguin Adventure.PLA-32.ROM
Space Manbow.KonSCC.rom
```

Tags are case-insensitive. If no valid tag is present, the tool first computes the ROM's SHA-1 hash and looks it up in an embedded database derived from the openMSX `softwaredb.xml`. When a match is found the database mapper type is used directly. Otherwise the tool falls back to heuristic detection.

Supported mapper tags:

| Tag | Aliases | Mapper Type |
|---|---|---|
| `PLA-16` | `PL-16` | Planar 16 KB |
| `PLA-32` | `PL-32`, `PLN-32`, `PLANAR`, `LINEAR` | Planar 32 KB |
| `KonSCC` | | Konami SCC |
| `PLN-48` | `PL-48` | Planar 48 KB |
| `ASC-08` | | ASCII8 |
| `ASC-16` | | ASCII16 |
| `ASC-16X` | | ASCII16-X |
| `Konami` | | Konami (without SCC) |
| `NEO-8` | | NEO8 |
| `NEO-16` | | NEO16 |
| `PLN-64` | `PL-64` | Planar 64 KB |
| `MANBW2` | `MANBOW2`, `MBW-2` | Manbow2 (Konami SCC + AMD flash) |

## Typical workflow

### Loading a regular MSX ROM

1. Place `loadrom.exe` in a working directory alongside the desired ROM file.
2. Open a Command Prompt or PowerShell window in that directory.
3. Run `loadrom.exe` pointing to the ROM and optionally overriding the UF2 name:
   ```
   loadrom.exe "Space Manbow.rom" -o space_manbow.uf2
   ```
4. Observe the console output:
   - Tool banner with embedded version.
   - Resolved ROM name (max 50 characters), size, mapper result, and Pico flash offset.
   - Progress message when UF2 blocks are written.
5. Put the Pico in BOOTSEL mode (hold BOOTSEL, plug USB) to mount the `RPI-RP2` drive.
6. Copy the generated UF2 file (e.g., `space_manbow.uf2`) to the drive. The Pico reboots once flashing completes.
7. Insert the PicoVerse cartridge into the MSX and power on—the embedded ROM boots immediately without a menu.

### Loading Sunrise IDE Nextor

1. Place `loadrom.exe` in a working directory.
2. Open a Command Prompt or PowerShell window in that directory.
3. Run `loadrom.exe` with the `-s` option and set the output filename:
   ```
   loadrom.exe -s -o nextor_sunrise.uf2
   ```
4. Put the Pico in BOOTSEL mode (hold BOOTSEL, plug USB) to mount the `RPI-RP2` drive.
5. Copy the generated UF2 file to the drive. The Pico reboots once flashing completes.
6. Insert the PicoVerse cartridge into the MSX with a USB thumb drive connected (use a USB OTG adapter if needed).
7. Power on the MSX to boot into Nextor. The cartridge's USB-C port now acts as a block device for loading ROMs and DSK files.

### Loading Sunrise IDE Nextor + 192KB Mapper

1. Place `loadrom.exe` in a working directory.
2. Open a Command Prompt or PowerShell window in that directory.
3. Run `loadrom.exe` with the `-m` option and set the output filename:
   ```
   loadrom.exe -m -o nextor_sunrise_mapper.uf2
   ```
4. Put the Pico in BOOTSEL mode (hold BOOTSEL, plug USB) to mount the `RPI-RP2` drive.
5. Copy the generated UF2 file to the drive. The Pico reboots once flashing completes.
6. Insert the PicoVerse cartridge into the MSX with a USB thumb drive connected (use a USB OTG adapter if needed).
7. Power on the MSX to boot into Nextor with the mapper-capable mode enabled. UI mapper text is shown as `SYSTEM`.
8. In this mode, the additional memory mapper capacity is 192KB (12 x 16KB pages).

### Loading USB Keyboard Firmware

1. Place `loadrom.exe` in a working directory.
2. Open a Command Prompt or PowerShell window in that directory.
3. Run `loadrom.exe` with the `-k` option:
   ```
   loadrom.exe -k -o keyboard.uf2
   ```
4. Put the Pico in BOOTSEL mode (hold BOOTSEL, plug USB) to mount the `RPI-RP2` drive.
5. Copy the generated UF2 file to the drive. The Pico reboots once flashing completes.
6. Connect a USB keyboard to the cartridge's USB-C port (use a USB-C OTG adapter or USB-A to USB-C adapter as needed).
7. Insert the PicoVerse cartridge into the MSX and power on. The USB keyboard now functions as the MSX keyboard.

> **Note**: The keyboard firmware does not work with FPGA-based MSX systems or MSX computers whose PPI is integrated into a custom chip (e.g. Panasonic models with the T9769 MSX-ENGINE). The internal PPI drives the slot data bus for keyboard ports, causing bus contention with the PicoVerse. It requires original MSX hardware with a discrete 8255 PPI.

### Loading MSX-MIDI Firmware

1. Place `loadrom.exe` in a working directory.
2. Open a Command Prompt or PowerShell window in that directory.
3. Run `loadrom.exe` with the `-i` option:
   ```
   loadrom.exe -i -o midi.uf2
   ```
4. Put the Pico in BOOTSEL mode (hold BOOTSEL, plug USB) to mount the `RPI-RP2` drive.
5. Copy the generated UF2 file to the drive. The Pico reboots once flashing completes.
6. Connect a USB-MIDI cable to the cartridge's USB-C port (use a USB-C OTG adapter if needed), and connect the cable's MIDI OUT to your MIDI device (e.g., Roland SoundCanvas).
7. Insert the PicoVerse cartridge into the MSX and power on. The cartridge now emulates the standard MSX-MIDI interface on ports `0xE8`–`0xEF`.
8. Run MIDI software from MSX-DOS. For MIDRY, use the `/I5` option: `MIDRY /I5 filename.MID`.

> **Note**: The `-i` option is standalone — the USB port is dedicated to the MIDI cable. You need a separate way to boot MSX-DOS (e.g., another cartridge with Nextor, or the MSX's built-in disk drive).

### Loading MIDI-PAC Firmware

1. Place `loadrom.exe` in a working directory.
2. Open a Command Prompt or PowerShell window in that directory.
3. Run `loadrom.exe` with the `-p` option:
   ```
   loadrom.exe -p -o midipac.uf2
   ```
4. Put the Pico in BOOTSEL mode (hold BOOTSEL, plug USB) to mount the `RPI-RP2` drive.
5. Copy the generated UF2 file to the drive. The Pico reboots once flashing completes.
6. Connect a USB MIDI cable, USB MIDI module, or USB-equipped synthesizer to the cartridge's USB-C port. (Roland Sound Canvas SC-55 and compatible modules are recommended.)
7. Insert the PicoVerse cartridge into the MSX and power on. The cartridge now passively monitors PSG traffic on ports `0xA0`–`0xA1` and converts music and sound effects to MIDI in real time.
8. Boot and run the MSX software you want to hear through the external MIDI module.

See [MSX PicoVerse 2040 MIDI-PAC](/docs/msx-picoverse-2040-midipac.md) for in-depth documentation on architecture, conversion algorithms, and limitations.

> **Note**: The `-p` option is standalone. MIDI-PAC does not provide ROM loading, mass storage, or MSX-MIDI ports; it is a dedicated PSG-to-MIDI conversion firmware. Requires a USB MIDI cable and a device capable of General MIDI playback for best results.

### Loading USB Joystick Firmware

1. Place `loadrom.exe` in a working directory.
2. Open a Command Prompt or PowerShell window in that directory.
3. Run `loadrom.exe` with the `-j` option:
   ```
   loadrom.exe -j -o joystick.uf2
   ```
4. Put the Pico in BOOTSEL mode (hold BOOTSEL, plug USB) to mount the `RPI-RP2` drive.
5. Copy the generated UF2 file to the drive. The Pico reboots once flashing completes.
6. Connect a USB gamepad to the cartridge's USB-C port (use a USB-C OTG adapter or USB hub as needed). Xbox 360, Xbox One, Xbox Series X|S, and generic USB HID gamepads are supported.
7. Insert the PicoVerse cartridge into the MSX and power on. The USB gamepad now functions as an MSX joystick — no MSX-side software or driver is required.
8. Up to 2 USB gamepads can be connected simultaneously (via a USB hub), mapped to MSX joystick ports 1 and 2.

See [MSX PicoVerse 2040 USB Joystick](/docs/msx-picoverse-2040-joystick.md) for in-depth documentation on architecture, open-drain bus driving, input mapping, and supported controllers.

> **Note**: The `-j` option is standalone — the USB port is dedicated to the gamepad(s). The firmware uses open-drain bus driving to coexist with the real PSG chip, so sound output is unaffected. If a physical joystick is also connected to the MSX, both inputs work simultaneously (active-low AND).

> **Note**: The joystick firmware does not work with FPGA-based MSX systems or MSX computers whose PSG is integrated into a custom chip (e.g. Panasonic models with the T9769 MSX-ENGINE). It requires original MSX hardware with a discrete AY-3-8910 or YM2149 PSG.

## Troubleshooting

| Symptom | Possible cause | Resolution |
| --- | --- | --- |
| "Invalid ROM file" | Missing or wrong extension | Ensure the ROM ends with `.ROM` (case-insensitive). |
| "Failed to detect the ROM type" | Mapper heuristics inconclusive | Add a mapper tag suffix (e.g., `.Konami.ROM`). |
| UF2 not recognized by Pico | File copied before BOOTSEL, or wrong family ID | Enter BOOTSEL mode before copying, and regenerate the UF2 with the latest tool. |
| Game title looks truncated | Name exceeds 50 characters | Use shorter filenames; the config record stores 50 bytes max. |

## Known limitations

- With a regular ROM: only one ROM can be embedded per UF2; use the MultiROM tool for menus and multiple titles.
- With Sunrise Nextor: requires a compatible USB thumb drive and appropriate Nextor loaders on the MSX side.
- In mapper mode (`-m`), mapper register handling is global (ports `FC`-`FF`) and the mapper capacity is 192KB.
- Linux/macOS binaries are not yet provided; use Wine or build from source with GCC.
- The tool does not verify ROM integrity beyond size checks and simple header heuristics.
- The keyboard firmware (`-k`) does not work with FPGA-based MSX implementations or MSX computers whose PPI is integrated into a custom chip (e.g. Panasonic models with the T9769 MSX-ENGINE). The internal PPI unconditionally drives keyboard port data onto the cartridge slot bus, which conflicts with the PicoVerse's bus response. See [USB Keyboard — FPGA Incompatibility Details](/docs/msx-picoverse-2040-keyboard.md#fpga-incompatibility-details) for the full analysis.
- The MIDI-PAC firmware (`-p`) depends on the target software using the standard PSG ports and on the connected MIDI device producing a musically useful result from the converted stream; it is a converter, not a literal PSG synthesizer.
- The joystick firmware (`-j`) does not work with FPGA-based MSX implementations or MSX computers whose PSG is integrated into a custom chip (e.g. Panasonic models with the T9769 MSX-ENGINE). The integrated PSG's output drivers conflict with the PicoVerse's open-drain bus driving on the data bus during register 14 reads, causing unreliable joystick data. It requires original MSX hardware with a discrete AY-3-8910 or YM2149 PSG.
- The joystick firmware (`-j`) does not read the physical DE-9 joystick ports directly. If a real joystick is also connected, both inputs work simultaneously (active-low AND on the bus). Not all USB gamepads are recognised — the firmware supports standard USB HID gamepads, Xbox 360 / XInput controllers, and Xbox One / Series X|S (GIP) controllers. Proprietary protocols (e.g. PlayStation DualSense via Bluetooth) may not work.

## Tested MSX models

The PicoVerse 2040 cartridge with LoadROM firmware has been tested when executing ROMs of the supported mappers on the following MSX models:

| Model | Type | Status | Comments |
| --- | --- | --- | --- |
| Adermir Carchano Expert 4 | MSX2+ | OK | Verified operation |
| Gradiente Expert | MSX1 | OK | Verified operation |
| JFF MSX | MSX1 | OK | Verified operation |
| MSX Book | MSX2+ (FPGA clone) | OK | Verified operation |
| MSX One | MSX1 | Not OK | Cartridge not recognized |
| National FS-4500 | MSX1 | OK | Verified operation |
| Omega MSX | MSX2+ | OK | Verified operation |
| Panasonic FS-A1GT | TurboR | OK | Verified operation |
| Panasonic FS-A1ST | TurboR | OK | Verified operation |
| Panasonic FS-A1WX | MSX2+ | OK | Verified operation |
| Panasonic FS-A1WSX | MSX2+ | OK | Verified operation |
| Panasonic FS-A1FX | MSX2+ | OK | Verified operation |
| Sanyo Wavy 70FD | MSX2+ | OK | Verified operation |
| Sharp HotBit HB8000 | MSX1 | OK | Verified operation |
| SMX-HB | MSX2+ (FPGA clone) | OK | Verified operation |
| Sony HB-F1XD | MSX2 | OK | Verified operation |
| Sony HB-F1XDJ | MSX2 | OK | Verified operation |
| Sony HB-F1XV | MSX2+ | OK | Verified operation |
| Sony Hit-Bit 20HB | MSX1 | OK | Verified operation |
| TRHMSX | MSX2+ (FPGA clone) | OK | Verified operation |
| uMSX | MSX2+ (FPGA clone) | OK | Verified operation |
| Yamaha YIS604 | MSX1 | OK | Verified operation |

Sunrise IDE Nextor ROM (options `-s` and `-m`) has been tested on the following MSX models:

| Model | Type | Status | Comments |
| --- | --- | --- | --- |
| Gradiente Expert | MSX1 | OK | Verified operation |
| Panasonic FS-A1WX | MSX2+ | OK | Verified operation |
| Panasonic FS-A1WSX | MSX2+ | OK | Verified operation |
| Panasonic FS-A1FX | MSX2+ | OK | Verified operation. Only -m option works correctly as Nextor requires minimum of 128KB RAM and originally this computer has only 64KB of base RAM in slot 3. |
| Sanyo Wavy 70FD | MSX2+ | OK | Verified operation |
| Sharp HotBit HB8000 | MSX1 | OK | Verified operation |
| TRHMSX | MSX2+ (FPGA clone) | OK | Verified operation |
| uMSX | MSX2+ (FPGA clone) | OK | Verified operation |

The USB keyboard firmware (option `-k`) with the PPI rephase has been tested on the following MSX models:

Note: The keyboard firmware is not compatible with FPGA-based MSX implementations or MSX computers with an integrated PPI (e.g. T9769 MSX-ENGINE) due to bus contention issues. It requires original MSX hardware with a discrete 8255 PPI.

| Model | Type | Status | Comments |
| --- | --- | --- | --- |
| Canon V20 | MSX1 | OK | Verified operation |
| Gradiente Expert | MSX1 | OK | Verified operation |
| Panasonic FS-A1 | MSX2 | OK | Verified operation |
| Panasonic FS-A1FX | MSX2+ | Not OK | Keyboard does not function correctly. This computer uses the T9769 MSX-ENGINE with the integrated PPI, the firmware is not compatible. |
| Panasonic FS-A1GT | TurboR | Not OK | Keyboard does not function correctly. This computer uses the T9769 MSX-ENGINE with the integrated PPI, the firmware is not compatible. |
| Panasonic FS-A1ST | TurboR | Not OK | Keyboard does not function correctly. This computer uses the T9769 MSX-ENGINE with the integrated PPI, the firmware is not compatible. |
| Sharp HotBit HB8000 | MSX1 | OK | Verified operation |
| Sony HB-101P| MSX1 | OK | Verified operation |
| Sony HB-F1XD | MSX2 | Not OK | Keyboard does not function correctly. This computer uses the Yamaha S1985 (MSX-SYSTEMII) made by Yamaha for ASCII Corporation. It integrates the PPI thus, not supporting the PicoVerse PPI emulation |

The MSX-MIDI firmware (option `-i`) has been tested on the following MSX models:

| MSX Model | Type | Status | MIDI Devices | Comments |
| --- | --- | --- | --- | --- |
| TRHMSX | MSX2+ (FPGA clone) | OK | Roland SC-55, [AliExpress MIDI/USB Simple Cable](https://s.click.aliexpress.com/e/_c3iqcWDh)  | Verified operation |
| uMSX | MSX2+ (FPGA clone) | OK | Roland SC-55, [AliExpress MIDI/USB Simple Cable](https://s.click.aliexpress.com/e/_c3iqcWDh)  | Verified operation |

The MIDI-PAC firmware (option `-p`) has been tested on the following MSX models and MIDI devices:

| MSX Model | Type | Status | MIDI Devices | Comments |
| --- | --- | --- | --- | --- |
| TRHMSX | MSX2+ (FPGA clone) | OK | Roland SC-55, [AliExpress MIDI/USB Simple Cable](https://s.click.aliexpress.com/e/_c3iqcWDh) | Verified frame-based PSG-to-MIDI conversion, stable vibrato handling, and 6-band percussion mapping |
| uMSX | MSX2+ (FPGA clone) | OK | Roland SC-55, [AliExpress MIDI/USB Simple Cable](https://s.click.aliexpress.com/e/_c3iqcWDh) | Verified operation; note-center stability and pitch-bend behavior confirmed |

Note: MIDI-PAC has been tested with games heavy in melody, modulation loops, arpeggios, envelopes, and percussion. Best results on General MIDI-compatible devices; the current voicing is optimized for Roland Sound Canvas class modules (SC-55, SC-88, etc.) while keeping the three melodic channels slightly forward relative to channel 10.

The USB joystick firmware (option `-j`) has been tested on the following MSX models and USB controllers:

Note: The joystick firmware is not compatible with FPGA-based MSX implementations or MSX computers with an integrated PSG (e.g. T9769 MSX-ENGINE) due to bus contention issues. It requires original MSX hardware with a discrete PSG.

| MSX Model | Type | Status | USB Controllers | Comments |
| --- | --- | --- | --- | --- |
| Gradiente Expert | MSX1 | OK | Xbox 360 Controller for Windows, Xbox One Controller (wired), Xbox Series X|S Controller (wired) | Verified operation with multiple controllers; tested with games that use both joystick ports |
| Panasonic FS-A1 | MSX2 | OK | Custom USB joystick |Verified operation |
| Panasonic FS-A1FX | MSX2+ | Not OK | N/A | Joystick does not function correctly. This computer uses the T9769 MSX-ENGINE with the integrated PSG, the firmware is not compatible. |
| Panasonic FS-A1GT | TurboR | Not OK | N/A | Joystick does not function correctly. This computer uses the T9769 MSX-ENGINE with the integrated PSG, the firmware is not compatible. |
| Panasonic FS-A1ST | TurboR | Not OK | N/A | Joystick does not function correctly. This computer uses the T9769 MSX-ENGINE with the integrated PSG, the firmware is not compatible. |
| Sharp HotBit HB8000 | MSX1 | OK | Xbox 360 Controller for Windows, Xbox One Controller (wired), Xbox Series X|S Controller (wired) | Verified operation with multiple controllers; tested with games that use both joystick ports |
| Sony HB-F1XD | MSX2 | Not OK |N/A|Joystick does not function correctly. This computer uses the Yamaha S1985 (MSX-SYSTEMII) made by Yamaha for ASCII Corporation. It integrates the PSG, the firmware is not compatible. |
|TRHMSX | MSX2+ (FPGA clone) | Not OK | N/A | Joystick does not function correctly. This is an FPGA-based MSX implementation, the firmware is not compatible. |
| uMSX | MSX2+ (FPGA clone) | Not OK | N/A | Joystick does not function correctly. This is an FPGA-based MSX implementation, the firmware is not compatible. |

Author: Cristiano Almeida Goncalves
Last updated: 04/12/2026

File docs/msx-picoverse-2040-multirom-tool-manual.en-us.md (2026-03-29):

# MSX PicoVerse 2040 Project

The PicoVerse 2040 is a Raspberry Pi Pico based cartridge for MSX that uses replaceable firmware to extend the computer’s capabilities. By loading different firmware images, the cartridge can run MSX games and applications and emulate additional hardware devices (such as ROM mappers, extra RAM, or storage interfaces), effectively adding virtual peripherals to the MSX. One such firmware is the MultiROM system, which provides an on‑screen menu for browsing and launching multiple ROM titles stored in the cartridge.

The cartridge can also expose the Pico’s USB‑C port as a mass‑storage device, allowing you to copy ROMs, DSKs, and other files directly from a PC with Windows or Linux to the cartridge.

Those are the features available in the current version of the PicoVerse 2040 cartridge:

* MultiROM menu system for selecting and launching MSX ROMs.
* Inline Menu option with Nextor OS support.
* USB mass-storage device support for loading ROMs and DSKs.
* Support for various MSX ROM mappers (PLA-16, PLA-32, KonSCC, PLN-48, PLN-64, ASC-08, ASC-16, ASC-16X, Konami, NEO-8, NEO-16, MANBW2).
* Compatibility with MSX, MSX2, and MSX2+ systems.

## MultiROM UF2 Creator Manual

This section documents the `multirom` console tool used to generate UF2 images (`multirom.uf2`) that program the PicoVerse 2040 cartridge.

In its default behavior, the `multirom` tool scans MSX ROM files in a directory and packages them into a single UF2 image that can be flashed to the Raspberry Pi Pico. The resulting image typically contains the Pico firmware, the MultiROM MSX menu ROM, a configuration area describing each ROM entry, and the ROM payloads themselves.

> **Note:** A maximum of 128 ROMs can be included in a single image, with a total size limit of aproximately 16 MB.

Depending on the options provided, `multirom` can also produce UF2 images that boot directly into a custom firmware instead of the MultiROM menu. For example, options can be used to produce UF2 files with a firmware that implements the Nextor OS. In this mode, the Pico’s USB‑C port can be used as a mass‑storage device for loading ROMs, DSKs, and other files from Nextor (for example, via SofaRun).

## Overview

If executed without any options, the `multirom.exe` tool scans the current working directory for MSX ROM files (`.ROM` or `.rom`), analyses each ROM to guess the mapper type, builds a configuration table describing each ROM (name, mapper byte, size, offset) and embeds this table into an MSX menu ROM slice. The tool then concatenates the Pico firmware blob, the menu slice, the configuration area and the ROM payloads and serializes the whole image into a UF2 file named `multirom.uf2`.



The UF2 file (usually multirom.uf2) can then be copied to a Pico's USB mass storage device to flash the combined image. You need to connect the Pico while pushing the BOOTSEL button to enter UF2 flashing mode. Then a new USB drive named `RPI-RP2` appears, and you can copy `multirom.uf2` to it. After the copy completes, you can disconnect the Pico and insert the cartridge into your MSX to boot the MultiROM menu.

ROM file names are used to name the entries in the MSX menu. There is a limit of 50 characters per name. A rolling effect is used to show longer names on the MSX menu, but if the name exceeds 50 characters it will be truncated.



> **Note:** To use a USB thumdrive you may need a OTG adapter or cable. That can be used to convert the USB-C port to a standard USB-A female port.

> **Note:** The `-s` option includes Sunrise IDE Nextor, and the `-m` option includes Sunrise IDE Nextor plus an additional 192KB mapper implementation. Both provide USB mass-storage support via the cartridge's USB-C port and work on MSX1, MSX2, and MSX2+ systems.

## Command-line usage

Only Microsoft Windows executables are provided for now (`multirom.exe`).

### Basic usage:

```
multirom.exe [options]
```

### Options:
- `-s`, `--sunrise` : Includes the embedded Sunrise IDE Nextor ROM for USB mass-storage support. The cartridge's USB-C port can be used as a block device with Nextor-compatible loaders like SofaRun.
- `-m`, `--mapper` : Includes the embedded Sunrise IDE Nextor ROM with 192KB mapper support (12 x 16KB pages). In the MSX menu this entry is still shown with mapper text `SYSTEM`.
- `-h`, `--help`   : Show usage help and exit.
- `-o <filename>`, `--output <filename>` : Set UF2 output filename (default is `multirom.uf2`).
- If you need to force a specific mapper type for a ROM file, you can append a mapper tag before the `.ROM` extension in the filename. The tag is case-insensitive. For example, naming a file `Knight Mare.PLA-32.ROM` forces the use of the PLA-32 mapper for that ROM. `SYSTEM` tags are ignored. The list of current tags is: `PLA-16, PLA-32, KonSCC, PLN-48, ASC-08, ASC-16, ASC-16X, Konami, NEO-8, NEO-16, PLN-64, MANBW2`.

### Examples
- Produces the multirom.uf2 file with the MultiROM menu and all `.ROM` files in the current directory. You can run the tool using the command prompt or just by double-clicking the executable:
  ```
  multirom.exe
  ```
- Produces a multirom UF2 that also includes a menu entry for Sunrise IDE Nextor + 192KB Mapper:
  ```
  multirom.exe -m -o multirom_mapper.uf2
  ```
  
## How it works (high level)

1. The tool scans the current working directory for files ending with `.ROM` or `.rom`. For each file:
   - It extracts a display-name (filename without extension, truncated to 50 chars).
   - It obtains the file size and validates it is between `MIN_ROM_SIZE` and `MAX_ROM_SIZE`.
   - It calls `detect_rom_type()` to heuristically determine the mapper byte to use in the configuration entry. If a mapper tag is present in the filename, it overrides the detection.
   - If mapper detection fails, the file is skipped.
   - It serializes the per-ROM configuration record (50-byte name, 1-byte mapper, 4-byte size LE, 4-byte flash-offset LE) into the configuration area.
2. After scanning, the tool concatenates (in order): embedded Pico firmware binary, a leading slice of the MSX menu ROM (`MENU_COPY_SIZE` bytes), the full configuration area (`CONFIG_AREA_SIZE` bytes), optional NEXTOR ROM, and then the discovered ROM payloads in discovery order.
3. The combined payload is written as a UF2 file named `multirom.uf2` using `create_uf2_file()` which produces 256-byte payload UF2 blocks targeted to the Pico flash address `0x10000000`.

## Mapper detection heuristics
- `detect_rom_type()` implements a combination of signature checks ("AB" header, `ROM_NEO8` / `ROM_NE16` / `ASCII16X` tags) and heuristic scanning of opcodes and addresses to pick common MSX mappers, including (but not limited to):
  - Plain 16KB (mapper byte 1) — 16KB AB header check
  - Plain 32KB (mapper byte 2) — 32KB AB header check
  - Planar48 mapper (mapper byte 4, tag `PLN-48`) — special AB layout check
  - Planar64 mapper (mapper byte 13, tag `PLN-64`) — 64KB planar layout
  - NEO8 (mapper byte 8) and NEO16 (mapper byte 9) — signature-based detection
  - ASCII16-X (mapper byte 12, tag `ASC-16X`) — `ASCII16X` signature at ROM offset 16
  - Manbow2 (mapper byte 14, tag `MANBW2`) — 512 KB Manbow 2 signature check
  - Konami, Konami SCC, ASCII8, ASCII16 and others via unit-weight scoring aligned with openMSX's `guessRomType()` algorithm
- Before applying heuristics, the tool computes the SHA-1 hash of the ROM and looks it up in an embedded database derived from the openMSX `softwaredb.xml`. When a match is found the database mapper type is used directly, bypassing the heuristic scanner. This improves accuracy for titles whose mapper cannot be reliably distinguished by opcode analysis alone.
- If no mapper can be reliably detected, the tool skips the ROM and reports "unsupported mapper". Remember you can force a mapper via filename tag. The tags are case-insensitive and are listed below. 
- Only the following mapper tags are supported in the configuration area and menu: `PLA-16, PLA-32, KonSCC, PLN-48, ASC-08, ASC-16, ASC-16X, Konami, NEO-8, NEO-16, PLN-64, MANBW2`.

## Using the MSX ROM Selector menu

When you power on the MSX with the PicoVerse 2040 cartridge inserted, the MultiROM menu appears, showing the list of available ROMs. You can navigate the menu using the keyboard arrow keys.



Use the Up and Down arrow keys to move the selection cursor through the list of ROMs. If you have more than 19 ROMs, use the lateral arrow keys (Left and Right) to scroll through pages of entries.

Press the Enter or Space key to launch the selected ROM. The MSX will attempt to boot the ROM using the appropriate mapper settings.

At any time while in the menu, you can press H key read the help screen with basic instructions. Press any key to return to the main menu.

## Using Nextor with the PicoVerse 2040 cartridge

The `-s` option of the multirom tool includes Sunrise IDE Nextor ROM, and the `-m` option includes Sunrise IDE Nextor ROM plus an additional 192KB mapper implementation. When the multirom UF2 is flashed with either option, the Pico's USB-C port exposes a block device that Nextor-compatible loaders (such as SofaRun) can use to load ROMs, DSK files, and other media from a connected USB thumb drive.

The Sunrise IDE implementation uses ATA register emulation, making it compatible with a wide range of MSX systems including MSX1, MSX2, and MSX2+ models. 

### How to prepare a thumb drive for Nextor

To prepare a USB thumb drive for use with Nextor on the PicoVerse 2040 cartridge, follow these steps:

1. Connect the USB thumb drive to your PC.
2. Create a 4GB maximum FAT16 partition on the thumb drive. You can use built-in Nextor OS tool (CALL FDISK while in MSX Basic) or third-party partitioning software to do this.
3. Copy the Nextor system files to the root directory of the FAT16 partition. You can obtain the Nextor system files from the official Nextor distribution or repository. You also need the COMMAND2 file for the command shell:
   1.  [Nextor Download Page](https://github.com/Konamiman/Nextor/releases) 
   2.  [Command2 Download Page](http://www.tni.nl/products/command2.html)
4. Copy any MSX ROMs (`.ROM` files) or disk images (`.DSK` files) you want to use with Nextor to the root directory of the thumb drive.
5. Install SofaRun or any other Nextor-compatible launcher on the thumb drive if you plan to use it for launching ROMs and DSKs. You can download SofaRun from its official source here: [SofaRun](https://www.louthrax.net/mgr/sofarun.html)
6. Safely eject the thumb drive from your PC.
7. Connect the thumb drive to the PicoVerse 2040 cartridge using a USB OTG adapter or cable if necessary.

> **Note:** Not all USB thumb drives are compatible with the PicoVerse 2040 cartridge. If you encounter issues, try using a different brand or model of thumb drive.
>
> **Note:** Nextor needs a minimum of 128 KB of RAM to operate; PicoVerse 2040 mapper mode provides 192KB mapper RAM (12 x 16KB pages).

## Known issues

- Some ROMs with uncommon mappers may not be detected correctly and will be skipped unless a valid mapper tag is used to force detection.
- The MultiROM tool currently only supports Windows. 
- The tool does not currently validate the integrity of ROM files beyond size and basic header checks. Corrupted ROMs may lead to unexpected behavior.
- Due to the nature of MultiROM tool (embedding multiple files into a single UF2), some antivirus software may flag the executable as suspicious. This is a false positive; ensure you download the tool from a trusted source.
- The MultiROM menu does not support DSK files; only ROM files are listed and launched.
- The tool does not currently support subdirectories; only ROM files in the current working directory are processed.
- The pico flash memory can wear out after many write cycles. Avoid excessive re-flashing of the cartridge.

## Tested MSX models

The PicoVerse 2040 cartridge with MultiROM firmware has been tested on the following MSX models:

| Model | Type | Status | Comments |
| --- | --- | --- | --- |
| Adermir Carchano Expert 4 | MSX2+ | OK | Verified operation |
| Gradiente Expert | MSX1 | OK | Verified operation |
| JFF MSX | MSX1 | OK | Verified operation |
| MSX Book | MSX2+ (FPGA clone) | OK | Verified operation |
| MSX One | MSX1 | Not OK | Cartridge not recognized |
| National FS-4500 | MSX1 | OK | Verified operation |
| Omega MSX | MSX2+ | OK | Verified operation |
| Panasonic FS-A1GT | TurboR | OK | Verified operation |
| Panasonic FS-A1ST | TurboR | OK | Verified operation |
| Panasonic FS-A1WX | MSX2+ | OK | Verified operation |
| Panasonic FS-A1WSX | MSX2+ | OK | Verified operation |
| Sanyo Wavy 70FD | MSX2+ | OK | Verified operation |
| Sharp HotBit HB8000 | MSX1 | OK | Verified operation |
| SMX-HB | MSX2+ (FPGA clone) | OK | Verified operation |
| Sony HB-F1XD | MSX2 | OK | Verified operation |
| Sony HB-F1XDJ | MSX2 | OK | Verified operation |
| Sony HB-F1XV | MSX2+ | OK | Verified operation |
| Sony Hit-Bit 20HB | MSX1 | OK | Verified operation |
| TRHMSX | MSX2+ (FPGA clone) | OK | Verified operation |
| uMSX | MSX2+ (FPGA clone) | OK | Verified operation |
| Yamaha YIS604 | MSX1 | OK | Verified operation |

Sunrise IDE Nextor ROM (options `-s` and `-m`) has been tested on the following MSX models:

| Model | Type | Status | Comments |
| --- | --- | --- | --- |
| Adermir Carchano Expert 4 | MSX2+ | OK | Verified operation |
| Gradiente Expert | MSX1 | OK | Verified operation |
| JFF MSX | MSX1 | OK | Verified operation |
| MSX Book | MSX2+ (FPGA clone) | OK | Verified operation |
| National FS-4500 | MSX1 | OK | Verified operation |
| Omega MSX | MSX2+ | OK | Verified operation |
| Panasonic FS-A1GT | TurboR | OK | Verified operation |
| Panasonic FS-A1ST | TurboR | OK | Verified operation |
| Panasonic FS-A1WX | MSX2+ | OK | Verified operation |
| Panasonic FS-A1WSX | MSX2+ | OK | Verified operation |
| Sanyo Wavy 70FD | MSX2+ | OK | Verified operation |
| Sharp HotBit HB8000 | MSX1 | OK | Verified operation |
| SMX-HB | MSX2+ (FPGA clone) | OK | Verified operation |
| Sony HB-F1XD | MSX2 | OK | Verified operation |
| Sony HB-F1XDJ | MSX2 | OK | Verified operation |
| Sony HB-F1XV | MSX2+ | OK | Verified operation |
| Sony Hit-Bit 20HB | MSX1 | OK | Verified operation |
| TRHMSX | MSX2+ (FPGA clone) | OK | Verified operation |
| uMSX | MSX2+ (FPGA clone) | OK | Verified operation |
| Yamaha YIS604 | MSX1 | OK | Verified operation |

Author: Cristiano  Goncalves
Last updated: 03/29/2026

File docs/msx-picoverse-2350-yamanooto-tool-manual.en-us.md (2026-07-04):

# MSX PicoVerse 2350 Yamanooto Tool Manual (EN-US)

The Yamanooto tool (`yamanooto.exe`) creates a UF2 image that flashes the PicoVerse 2350 with the
**Yamanooto** flash-cartridge emulation and a single ROM image. The cartridge then behaves like a
 *Yamanooto*: a Konami-SCC compatible flash cartridge with **SCC / SCC+** audio and a
**secondary (dual) PSG**, plus the PicoVerse additions of an **MSX-MUSIC (YM2413 / FM-PAC)** engine
and a **primary PSG mirror**.

`yamanooto.exe` bundles the Pico firmware blob, a configuration record (game name, type, ROM size,
and offset), the MSX ROM image, and the FM-PAC BIOS into an RP2350-compatible UF2 image. Copy the
generated UF2 to the board in BOOTSEL mode and the MSX boots straight into the embedded ROM.

Package location: `2350/software/yamanooto`.

For the firmware architecture behind this tool, see the
[PicoVerse 2350 Yamanooto implementation guide](./msx-picoverse-2350-yamanooto.md).

---

## Overview

1. **Input**: one `.ROM` file — a Konami-SCC / Konami-4 compatible image up to 8 MB.
2. **Processing**: the tool derives the ROM name from the filename and streams
   firmware + configuration record + ROM + FM-PAC BIOS into UF2 blocks.
3. **Output**: a UF2 file (default `yamanooto.uf2`) ready for the RP2350 bootloader.

Key characteristics:

- Windows console application.
- ROM sizes from 8 KB up to 8 MB (the Yamanooto flash size).
- SCC/SCC+, the secondary (dual) PSG, the primary PSG mirror, and MSX-MUSIC/FM-PAC are **always
  available** — no per-mode flags. The firmware selects SCC, FM, or pure PSG **on the fly** based on
  what the running game drives.
- The English FM-PAC BIOS is always embedded and appended after the ROM image.
- UF2 uses the RP2350 family ID (`0xE48BFF59`).

---

## Command-line usage

```
yamanooto.exe [options] <rom_file>
```

### Options

- `-h`, `--help` : Print usage information and exit.
- `-o <filename>`, `--output <filename>` : Override the UF2 output name (default `yamanooto.uf2`).
- Positional argument: the ROM image to embed (required).

There are no audio-mode flags: SCC/SCC+, dual PSG, PSG mirror, and MSX-MUSIC are all present in every
build and chosen automatically at runtime.

### Examples

```
:: Default output name
yamanooto.exe MyKonamiGame.rom

:: Custom output name
yamanooto.exe -o mygame.uf2 MyKonamiGame.rom
```

The tool prints the ROM name, ROM size, and output filename before writing the UF2. It rejects files
smaller than 8 KB or larger than 8 MB.

---

## Workflow

1. Open a Command Prompt or PowerShell window in `2350/software/yamanooto/tool` (the tool also accepts
   drag-and-drop of a ROM onto the EXE).
2. Run `yamanooto.exe -o mygame.uf2 \path\to\Game.ROM`.
3. Confirm the reported ROM name and size.
4. Put the Pico into BOOTSEL mode (hold BOOTSEL while connecting via USB-C) and copy the generated
   UF2 to the `RPI-RP2` drive.
5. Insert the cartridge into your MSX — on power-up the embedded game launches.

---

## Audio behaviour

- **SCC / SCC+** — Konami SCC games are detected and played automatically (SCC when bank 2 = `0x3F`,
  SCC+ via the enhanced mode register).
- **Secondary (dual) PSG** — a second AY-3-8910 on I/O ports `0x10`/`0x11`.
- **Primary PSG mirror** — the main MSX PSG (`0xA0`/`0xA1`) is mirrored through the cartridge DAC.
- **MSX-MUSIC / FM-PAC** — the FM-PAC BIOS is exposed in an expanded subslot so FM games detect the
  YM2413; the OPLL responds to both the FM-PAC memory registers (`0x7FF4`/`0x7FF5`) and the raw I/O
  ports (`0x7C`/`0x7D`).
- The firmware renders **one heavy engine at a time** (SCC *or* FM), chosen live from the running
  game, and mixes the PSG on top. A single flash image can therefore contain a mix of SCC games, FM
  games, and plain PSG games.

Audio is 16-bit stereo at 44.1 kHz through the on-cartridge I2S DAC.

---

## Limitations

- **Flash programming is not emulated.** The cartridge runs the pre-flashed image built by this tool;
  on-MSX Yamanooto self-flashing (`WREN` + flash command sequences) is ignored.
- **PicoVerse 2350 only.** The Yamanooto firmware requires the RP2350B board, dual cores, and the I2S
  DAC; it is not available for the PicoVerse 2040.
- With MSX-MUSIC always present, the machine performs one extra reset at cold boot (during loading)
  while the expanded slot is set up.

---

## UF2 image layout

The generated UF2 contains, in order: the Yamanooto firmware, a 59-byte configuration record
(50-byte name + 1-byte type + 4-byte size + 4-byte offset), the ROM image, and the 64 KB FM-PAC BIOS.
The firmware locates the ROM immediately after the configuration record and the FM-PAC BIOS
immediately after the ROM.

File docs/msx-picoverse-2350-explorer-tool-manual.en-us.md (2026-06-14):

# MSX PicoVerse 2350 Explorer Tool Manual (EN-US)

The Explorer tool creates a UF2 image that flashes the PicoVerse 2350 cartridge with the Explorer firmware. The UF2 bundles:
- PicoVerse 2350 Explorer firmware.
- The full 32KB MSX Explorer menu ROM.
- A configuration table describing each ROM stored in flash (stored in flash immediately after the menu ROM).
- The ROM payloads that will live in Pico flash.
- The integrated File Hunter browser and WiFi configuration support used by the Explorer menu.

Use the Explorer tool when you want a menu that loads ROMs from flash, microSD, and the online File Hunter catalog on the PicoVerse 2350, or if you want to explore advanced features like microSD MP3 playback, SCC/SCC+ audio, Dual PSG audio, MSX-MUSIC, and optional primary PSG mirroring through the cartridge DAC on your MSX computer.

## Requirements

- Windows PC (the distributed binary is a Windows console app).
- A folder containing the `.ROM` files you want stored in flash.
- A PicoVerse 2350 cartridge and USB-C cable.
- Optional: a microSD card (for additional ROMs, MP3/WAV files, and Sunrise Nextor SD storage).
- Optional but required for File Hunter: an ESP-01 / ESP8266 module with compatible firmware, installed on the PicoVerse 2350 WiFi header and configured for your wireless network.

## Limits

- Flash ROM entries created by the tool: up to 128 files.
- Combined Explorer menu limit: 1024 entries per folder view (folders + ROMs + MP3s; the root view also includes ROM files stored directly on the flash memory).
- Total flash ROM payload size: ~14 MB combined.
- Supported ROM size range on the flash: 8 KB to ~14 MB.
- ROM names in the menu are limited to 60 characters (longer names are truncated).
- File Hunter search text is limited to 24 characters.
- File Hunter downloads are saved as `.ROM` files directly in the root of the microSD card.

## Basic workflow

1. Put all `.ROM` files you want in the Pico flash into a single folder (no subfolders).
2. Run the tool in that folder to create `explorer.uf2`.
3. Put the PicoVerse 2350 into BOOTSEL mode and copy the UF2 to the `RPI-RP2` drive.
4. (Optional) Copy more `.ROM` and `.MP3` files to a microSD card for SD loading.
5. (Optional) Insert an ESP-01 module and configure WiFi from the Explorer menu if you want to browse File Hunter.
6. Insert the cartridge into your MSX and power on.

### Explorer menu capabilities

- **Folder navigation**: Organize your ROMs into folders on the microSD card. Enter folders by pressing Enter or Space on a folder name, and navigate back to parent folders using the ".." entry or by pressing Esc.
- **Search** by ROM name directly on the MSX by pressing `/`, typing part of the name, and pressing Enter to jump to the first match. Note that this feature only searches ROMs inside the current folder. When in the root, it searches all flash and SD ROMs located in the root.
- **File Hunter browser**: Press `F3` to browse online ROM results from File Hunter through the ESP-01 WiFi module. Results show the ROM name, size, and source, and selected ROMs can be downloaded and saved to the microSD root.
- **WiFi configuration**: Press `F4` to enter the WiFi setup flow used by the ESP8266P-compatible WiFi firmware.
- **Automatic detection** of MSX models that support 80-column text mode. Compatible machines boot the menu in 80 columns; others fall back to 40 columns, and you can press `C` at any time to toggle between layouts.
- MP3 entries from the microSD card are listed in the menu with a "MP3" type label and open an **MP3 player** screen when selected.
- ROM entries open a ROM screen that lets you inspect mapper detection, choose **audio profiles** including SCC/SCC+, Dual PSG, or MSX-MUSIC where supported, enable optional primary **PSG** mirroring to the DAC, and enable optional WiFi support for Sunrise Nextor entries before running.

## Command-line usage

```
explorer.exe [options]
```

### Options

- `-h`, `--help` : Show usage help and exit.
- `-o <filename>`, `--output <filename>` : Set UF2 output filename (default is `explorer.uf2`).
- `-n`, `--nextor` : Include embedded Nextor ROM (experimental; MSX2-only). In the 2350 build, this is labeled “Nextor SD (IO)”.

### Example

```
explorer.exe
```

This scans the current directory and generates `explorer.uf2`.

## ROM mapper detection and tags

For the flash entries, the PC tool analyzes each ROM to determine the mapper. If you need to override it, add a mapper tag to the filename before `.ROM`. Tags are case-insensitive.

Supported tags:
`PL-16`, `PL-32`, `KonSCC`, `Linear`, `PL-64`, `ASC-08`, `ASC-16`, `Konami`, `NEO-8`, `NEO-16`, `ASC-16X`, `MANBW2`.

Mapper detection on the Pico (for unknown SD ROMs) and on the PC tool both use a shared SHA-1 ROM database derived from openMSX's `softwaredb.xml`, falling back to heuristic scanning when the SHA-1 is not in the database.

Example:

```
Knight Mare.PL-32.ROM
```

Notes:
- The `SYSTEM` tag is ignored and cannot be forced.
- Unsupported ROMs are skipped.

## Using microSD with Explorer

Explorer can load ROMs from a microSD card in addition to flash. ROMs on SD are merged into the menu list and marked with the "SD" source tag. You can organize your ROM collection into folders for easier navigation.

- Format Explorer browsing partitions as FAT16, FAT32, or exFAT.
- Explorer can enumerate supported primary and logical partitions. Press `P` while in the `F2` microSD screen to cycle between supported partitions.
- The selected Explorer browsing partition is saved in `/PICOVERSE.PVC` on the first supported partition and restored on later boots.
- The lower status area shows the selected partition label and free MB. In 40-column mode, the label and free-space amount alternate so both remain readable.
- Copy `.ROM` and `.MP3` files to the root of the card or organize them in subfolders for better organization.
- SD ROMs appear in the menu with the source label "SD".
- MP3 files appear in the menu with the "MP3" type label and open the MP3 player screen.
- Flash ROMs appear with the source label "FL".
- File Hunter downloads are saved directly to the root of the microSD card and then appear as normal SD ROM files in the Explorer root list.
- Folders are displayed in the menu and can be entered to browse their contents.
- The special ".." entry appears when inside a folder, allowing you to navigate back to the parent directory.

### Sunrise Nextor SD partitions in Explorer

Sunrise Nextor SYSTEM entries use stricter partition rules than the normal `F2` microSD browser. Nextor SD storage is offered only for FAT16 microSD partitions up to 4 GB. FAT32 and exFAT partitions remain usable for Explorer file browsing, ROM loading, MP3/WAV playback, and File Hunter downloads, but they are not offered to Sunrise Nextor SYSTEM ROMs.

When a Sunrise Nextor SYSTEM entry is opened in the ROM screen, Explorer shows the compatible FAT16 partition label in the `SD Part` option. If more than one compatible FAT16 partition exists, use Left/Right on `SD Part` to choose the partition before running. The selected partition is saved in that ROM's `.PVC` options file, so each Sunrise Nextor SYSTEM entry can remember its own storage partition.

### microSD limitations

- The combined list is capped at 1024 entries per folder view (folders + ROMs + MP3s; the root view can also include flash entries).
- microSD ROM files are limited to 4 MB each. ROMs are streamed into the cartridge's 8 MB external PSRAM (QMI CS1, 52.5 MHz QPI) and executed from there; the first 256 KB are mirrored into the PSRAM ROM cache for mapper access. ROMs larger than 4 MB are skipped during enumeration.
- Unsupported or invalid ROMs are skipped (same mapper and size rules as flash).

### Performance note: MSX Response Time

MSX computers have slower processors compared to modern hardware. When navigating to a folder with a large number of ROMs (100+), the Pico will scan the directory contents and you will see a blinking "Loading..." message. This is normal behavior:

- **Small folders (< 50 ROMs)**: Directory listing typically completes in 1-2 seconds.
- **Large folders (100-900 ROMs)**: Directory listing may take over 5 seconds depending on the microSD card speed and the number of files.

For the best experience with very large ROM collections, consider organizing ROMs into subfolders by category (e.g., ACTION, PUZZLE, RPG) rather than storing all ROMs in a single folder.

## Menu usage (on MSX)

- **Up/Down**: Move selection up or down in the list.
- **Left/Right**: Change pages (when the list spans multiple pages).
- **Enter**: Open the selected entry. Folders enter the directory, MP3 entries open the MP3 player screen, and ROM entries open the ROM screen.
- **Space**: Enter folders and open MP3 entries like Enter. On ROM entries, quick-run the ROM using saved `.PVC` options when present or default settings when no `.PVC` file exists. Unknown SD ROM mappers are detected before launch.
- **Esc**: Navigate back to the parent folder (when inside a folder). Same as pressing Enter/Space on the ".." entry.
- **F1**: Switch the Explorer list to flash ROMs.
- **F2**: Switch the Explorer list to microSD files and folders.
- **F3**: Open the integrated File Hunter browser.
- **F4**: Open WiFi configuration.
- **H**: Show help screen.
- **P**: In the `F2` microSD screen, cycle through supported FAT16, FAT32, and exFAT partitions. The selected browsing partition is saved in `/PICOVERSE.PVC`.
- **D**: In the `F2` microSD screen, delete the selected file after a `Y/N` confirmation. This command is valid for files only; folders are protected.
- **/**: Search ROM names. Type a partial name and press Enter to jump to the first matching ROM.
- **C**: Toggle between 40-column and 80-column layouts when your MSX supports it (auto-detects 80-column capable machines and defaults to 80 columns unless forced otherwise).

### Folder navigation workflow

1. The root menu lists all flash ROMs and files/folders from the microSD card root.
2. Folders appear in the list with a \<DIR\> indicator.
3. Press Enter or Space on a folder name to enter it and view its contents.
4. While loading a folder (especially large folders with many ROMs), you will see a blinking "Loading..." message on the bottom left corner. This is normal and indicates the Pico is scanning the directory.
5. Once loaded, navigate using Up/Down arrows as usual.
6. Press Esc or select the ".." entry to return to the parent folder or root.
7. Repeat to drill down through nested folders as needed.

## File Hunter browser

Explorer includes an integrated File Hunter browser for PicoVerse 2350 cartridges fitted with an ESP-01 / ESP8266 module. The browser talks directly from the Pico firmware to the ESP module, queries the public File Hunter service, downloads the selected ROM into PSRAM, and then saves it as a `.ROM` file in the root of the microSD card.

The File Hunter integration is inspired by NataliaPC's MSX File Hunter Browser project and uses the public File Hunter catalog endpoint. See the external reference section near the end of this document for the upstream project link.

### Before using File Hunter

- Install an ESP-01 / ESP8266 module on the PicoVerse 2350 WiFi header.
- Use ESP firmware compatible with the ESP8266P / memio command protocol used by PicoVerse.
- Insert a FAT16, FAT32, or exFAT microSD browsing partition. File Hunter downloads are saved to the selected Explorer partition root.
- If the card has not been mounted in the current session, press `F2` once to open the microSD list before downloading from File Hunter.
- Configure WiFi from the Explorer menu if the ESP module has not already been configured for your network.

### Opening File Hunter

Press `F3` from the Explorer menu. The menu frame is drawn immediately, then the lower-left status area shows "Retrieving File Hunter" in 80-column mode or "Retrieving..." in 40-column mode while the first page is fetched.

The initial File Hunter query starts with `1`, matching the current Explorer behavior for the first catalog request. After the first page is loaded, the browser shows the File Hunter result list with the same Explorer frame, footer, page counter, and 40/80-column support used by the normal menu.

### File Hunter list screen

Each result row shows:

- ROM name on the left.
- Size aligned to the right side of the row.
- Source label `FH`.
- Type label `ROM` aligned at the far right.

In 40-column mode, long selected names slide horizontally while the cursor remains on the row. In 80-column mode, longer names fit directly in the wider row.

The network state appears in the lower-left status area as "Network: Online" / "Network: Offline" in 80-column mode or "Net: Online" / "Net: Offline" in 40-column mode. The standard command hints stay on the right side of the last line.

### File Hunter controls

- **Up/Down**: Move through the result list.
- **Left/Right**: Change result pages.
- **Enter**: Open the selected ROM detail screen.
- **Space**: Quick-run the selected ROM with saved `.PVC` options or default settings. If the ROM is on microSD and its mapper has not been detected yet, Explorer detects it before launching.
- **/**: Search File Hunter. Type a query and press Enter to load matching results. Press Esc at the search prompt to cancel.
- **F1**: Leave File Hunter and return to the flash ROM list.
- **F2**: Leave File Hunter and return to the microSD list.
- **F3**: File Hunter is already selected; pressing it again has no effect.
- **F4**: Open WiFi configuration.
- **C**: Toggle 40/80-column mode when supported.
- **Esc**: Exit File Hunter and return to the normal Explorer menu.

### Searching File Hunter

Press `/` while inside File Hunter, type part of a title, and press Enter. Explorer sends that text as the File Hunter query and reloads the result list from page 1. Search text is limited to 24 characters.

If the ESP module is not connected to WiFi, the browser reports an offline state and the request fails instead of hanging indefinitely. When WiFi is still associating, the Pico waits briefly and shows a waiting status before reporting failure.

### ROM detail and download workflow

Selecting a File Hunter result opens a detail screen showing:

- ROM name.
- Size.
- Source: `FH`.
- Action: Download.

Press Enter or Space on the detail screen to download the selected ROM. Explorer first downloads the ROM from File Hunter into PSRAM. The status line shows a percentage counter from 0% to 100% while the download is active. After the download completes, the Pico saves the ROM from PSRAM to the root of the microSD card using the same filename shown by File Hunter.

When the save succeeds, the detail screen shows "Saved to microSD. Press key." Press any key to return to the File Hunter list. The Explorer root microSD list is refreshed after a successful save, so returning to the microSD root with `F2` lets you search for and launch the newly downloaded ROM as a normal SD ROM.

### File Hunter limitations and notes

- File Hunter requires a working ESP-01 / ESP8266 module and WiFi connection.
- A microSD card must be present because downloads are saved directly to the card root.
- Downloaded ROMs use File Hunter's filename. If a file with the same name already exists in the microSD root, it is replaced.
- Download and save speed depends on WiFi quality, the ESP module firmware, File Hunter response time, and microSD card performance.
- File Hunter entries are online catalog results, not flash entries. After saving, they become SD ROM entries.

## Known limitations

- Flash ROMs packaged by the tool must be in the root of the source folder (no subfolders in the flashing process, though SD folders are fully supported in the menu).
- The `-n` Nextor option is experimental and may not work on all MSX2 models.
- ROMs with unknown or unsupported mappers are skipped unless you force a mapper tag.
- Very deep folder nesting (more than 10+ levels) is supported but may have perception of slowness due to repeated folder scans.
- File Hunter browsing is unavailable without an ESP-01 / ESP8266 module, compatible ESP firmware, and a configured WiFi network.
- File Hunter downloads are stored in the root of the microSD card; Explorer does not create a separate File Hunter folder.

## MP3 player screen

Selecting an MP3 entry from the microSD card opens a dedicated player screen. MP3 files are not embedded in flash by the Explorer tool; copy them to the microSD card root or to folders on the card, then open the microSD list with `F2`.

The player screen shows the MP3 file name, size, playback status, and elapsed play time. The elapsed counter is refreshed while the screen is open. Total duration is not shown because Explorer does not scan the whole MP3 stream before playback.

The screen displays two selectable action rows:

1. **Action: Play / Stop**: starts playback when stopped, or stops the current file when playing or paused.
2. **Action: Pause / Resume**: pauses the current playback, or resumes it after pausing.

### Controls

- **Up/Down**: Move between the action rows.
- **Enter/Space**: Execute the selected action.
- **Esc**: Stop playback and return to the Explorer list.
- **C**: Toggle 40/80-column layout on supported systems.

### Audio behavior

MP3 decoding runs on the Pico side and streams stereo PCM to the cartridge I2S DAC. The MSX menu remains responsive while playback is active. The DAC mute line is released only while MP3 or ROM audio is active, and is muted again when playback stops or when Explorer returns to idle browsing.

## ROM screen

Selecting a ROM entry opens a ROM details screen before running:

- **Mapper**: Shows the detected mapper (for SD ROMs) and allows manual override using Left/Right.
- **Audio**: Choose an audio profile with Left/Right (None, SCC, SCC+, external SCC/SCC+, Dual PSG, MSX-MUSIC, SFG01/SFG05). The menu only cycles through profiles supported by the selected ROM mapper.
- **PSG**: Choose whether to mirror the MSX primary PSG writes through the cartridge DAC. The default is Yes unless saved `.PVC` options override it.
- **Wifi**: For Sunrise Nextor entries only, choose whether to expose the ESP8266P WiFi BIOS before running. The default is No.
- **SD Part**: For Sunrise Nextor SD entries only, choose the FAT16 partition up to 4 GB that Nextor will boot from. The selected partition is saved with the ROM options.
- **Action: Run**: Press Enter to launch the ROM.
- **Esc**: Return to the menu without running.

If a ROM mapper is unknown, the screen will briefly show "Detecting..." while the Pico attempts detection.

### Audio profile options

- **None**: No extra cartridge audio profile. The ROM still uses the MSX's built-in PSG normally.
- **SCC**: Enables Konami SCC (standard) sound emulation. Use this for games that use the standard SCC chip with shared channel 4/5 waveforms (e.g., *Space Manbow*, *Salamander*, *Nemesis 2*, *Gradius 2*).
- **SCC+**: Enables Konami SCC+ (enhanced/SCC-I) sound emulation. Use this for games or homebrew that require SCC+ features with independent channel 4/5 waveforms.
- **SCC - External**: Exposes a virtual SCC cartridge in a secondary subslot while keeping the selected game mapper in the primary game subslot. Use this for ROMs that look for an SCC cartridge in another slot.
- **SCC+ - External**: Same as **SCC - External**, but with the enhanced SCC+ register model.
- **YM2151 (SFG05)**: Exposes a Yamaha SFG-05-like YM2151 cartridge surface and the SFG-05 BIOS image in a secondary subslot while keeping the selected game mapper in the primary game subslot. Use this for ROMs that scan another slot for SFG/YM2151 hardware.
- **YM2151 (SFG01)**: Exposes the SFG-01 BIOS image with the same YM2151 register surface for software that distinguishes SFG01/SFG05 setups.
- **Dual PSG**: Enables a secondary AY-3-8910 compatible PSG on I/O ports `0x10` (register select) and `0x11` (data write), matching the common Carnivore2 / MegaFlashROM / FlashJacks style second-PSG convention. Use this for ROMs or patches that explicitly support dual PSG music.
- **MSX-MUSIC**: Enables YM2413/MSX-MUSIC audio using an FM-PAC-compatible BIOS from the Explorer UF2 flash payload. Use this for regular ROMs that can use MSX-MUSIC ports `0x7C` and `0x7D`; Sunrise Nextor SYSTEM entries also expose the FM-PAC BIOS in a free expanded subslot.

Explorer treats audio profiles as mutually exclusive: a ROM can run with no extra audio, SCC, SCC+, external SCC/SCC+, Dual PSG, MSX-MUSIC, or YM2151/SFG, but not multiple cartridge audio engines at the same time.

The **PSG** field is independent from the Audio profile. When set to **Yes**, Explorer mirrors writes to the primary MSX PSG ports `0xA0` and `0xA1`, generates matching AY/YM audio on the Pico, and sends that audio through the cartridge I2S DAC. The real MSX PSG is not disabled; the option provides a DAC-side copy of the main PSG. It can be combined with **None**, **SCC**, **SCC+**, external SCC/SCC+, **Dual PSG**, **MSX-MUSIC**, or **YM2151 (SFG01/SFG05)**, so PSG music can be heard through the cartridge DAC together with the selected cartridge audio profile. When **Dual PSG** and **PSG: Yes** are enabled together, Explorer routes Dual PSG to the left channel and the mirrored primary PSG to the right channel for a stereo split. The option defaults to **Yes** unless saved `.PVC` options override it.

The SCC and SCC+ audio profiles work with ROMs using the Konami SCC mapper (`KonSCC`) or the Manbow2 mapper (`MANBW2`). When a ROM is detected as `KonSCC` or `MANBW2`, the ROM screen pre-selects **SCC** in the Audio field; you can change it to None, SCC+, or one of the external SCC profiles before pressing Run. Dual PSG and MSX-MUSIC are not offered for these mappers because the cartridge audio slot is reserved for SCC/SCC+.

The external SCC and SCC+ profiles are available for non-SYSTEM ROM entries and Sunrise Nextor SYSTEM entries. Non-SYSTEM ROMs launch in an expanded cartridge layout with the selected game mapper in subslot 0 and the virtual SCC/SCC+ cartridge surface in subslot 1. Sunrise Nextor SYSTEM launches keep Nextor storage in its normal subslot, keep mapper RAM available only for the explicit `+ 1MB Mapper` entries, and place the virtual SCC/SCC+ cartridge in subslot 2 without WiFi or subslot 3 when WiFi is enabled. This is intended for games, loaders, or Nextor BASIC sessions that explicitly scan for an SCC cartridge in another slot.

The YM2151 SFG01/SFG05 profiles are available for supported non-SYSTEM ROM entries and Sunrise Nextor SYSTEM entries. Non-SYSTEM ROMs use the same expanded layout as the external SCC profiles: subslot 0 remains the selected game mapper, while subslot 1 exposes an SFG-like memory-mapped YM2151 surface and the selected Yamaha SFG BIOS image. Sunrise Nextor SYSTEM launches use a mapper-backed expanded layout so Nextor still has RAM available; the SFG surface is placed in subslot 2 without WiFi or subslot 3 when WiFi is enabled. The implemented SFG memory window responds at slot-local `0x3FF0` for the YM2151 address register and `0x3FF1` for YM2151 data/status. MIDI/keyboard-facing SFG addresses return idle values in this first implementation. The Explorer UF2 stores `SFG_64K.ROM` as a hidden flash payload; the SFG05 profile exposes the first 32K BIOS image and the SFG01 profile exposes the second 32K BIOS image.

The Dual PSG and MSX-MUSIC profiles are available for regular non-SYSTEM ROMs that are not Konami SCC or Manbow2, and Sunrise Nextor SYSTEM entries can use the SYSTEM audio service for the supported SYSTEM profiles. When MSX-MUSIC is selected for Sunrise Nextor, Explorer keeps the Nextor storage layout active and places the FM-PAC BIOS/control surface in subslot 2 without WiFi or subslot 3 with WiFi. These cartridge audio profiles are not offered for NEO system entries, folders, or SCC-capable ROMs.

Primary PSG mirroring is intended for normal ROM launches from flash or microSD, including ROMs downloaded from File Hunter after they have been saved to the card. SYSTEM/storage entries that reserve core 1 for storage backends do not use the PSG DAC mirror path.

## SCC/SCC+ sound emulation

The PicoVerse 2350 Explorer firmware can emulate the Konami SCC and SCC+ (SCC-I) sound chips in hardware, generating audio through an I2S DAC connected to the RP2350. This gives MSX games that use SCC or SCC+ sound their full soundtrack without requiring an original SCC cartridge. Native SCC/SCC+ profiles attach the emulated SCC to Konami SCC or Manbow2 mapper launches; external SCC/SCC+ profiles expose the emulated chip as a separate virtual cartridge subslot for non-SYSTEM ROMs and Sunrise Nextor SYSTEM entries that search another slot for SCC hardware.

## Dual PSG sound emulation

The PicoVerse 2350 Explorer firmware can also emulate a second AY-3-8910 compatible PSG for ROMs that write to the standard secondary PSG ports. The Pico captures writes to `0x10` and `0x11`, feeds them to the emulated PSG, and streams the generated audio through the same I2S DAC path used by the other cartridge audio engines.

The MSX's internal PSG remains active as usual. The Dual PSG profile adds the external/secondary PSG only; software must be written or patched to use ports `0x10` and `0x11` for the extra three channels.

For firmware architecture, port handling, audio routing, and LoadROM/Explorer differences, see the [PicoVerse 2350 Dual PSG implementation guide](./msx-picoverse-2350-dualpsg.md).

## Primary PSG mirroring

Explorer can also mirror the normal MSX PSG output through the cartridge DAC. This is controlled by the separate **PSG** field on the ROM screen, not by the Audio profile field.

When **PSG: Yes** is selected, the Pico captures writes to the primary PSG ports `0xA0` and `0xA1`, feeds them to an AY/YM-compatible `emu2149` instance, and mixes the generated samples into the active I2S audio stream. If no other cartridge audio profile is selected, Explorer starts a PSG-only I2S audio loop. If SCC, SCC+, external SCC/SCC+, Dual PSG, MSX-MUSIC, or YM2151/SFG is selected, the primary PSG mirror is mixed into that profile's DAC stream. In the specific **Dual PSG + PSG** combination, Explorer outputs the Dual PSG stream on left and the primary PSG mirror on right.

This does not replace or mute the physical PSG inside the MSX. It is useful when you want ROM PSG music and effects on the same cartridge DAC output as SCC, Dual PSG, or MSX-MUSIC.

## MSX-MUSIC emulation

The PicoVerse 2350 Explorer firmware can emulate the YM2413/MSX-MUSIC audio chip and expose an FM-PAC-compatible BIOS in an expanded cartridge slot when the **MSX-MUSIC** audio profile is selected. The BIOS is stored as a hidden payload in the Explorer UF2 after the WiFi configuration and ESP8266P BIOS payloads; it is read from flash at launch time and is not compiled into the Pico firmware binary.

MSX-MUSIC uses I/O ports `0x7C` for register select and `0x7D` for data writes, with synthesized audio routed to the same I2S DAC path used by the other Explorer audio profiles. The profile is mutually exclusive with SCC, SCC+, and Dual PSG, and is only offered for regular non-SYSTEM ROMs that are not Konami SCC or Manbow2.

## YM2151 / Yamaha SFG emulation

Explorer can expose a virtual Yamaha SFG01/SFG05-style YM2151 device for supported non-SYSTEM ROMs and Sunrise Nextor SYSTEM entries. For game ROMs, the selected game mapper stays in subslot 0 and the SFG-like surface appears in subslot 1. For Sunrise Nextor SYSTEM entries, Explorer keeps the Nextor ROM and mapper RAM layout active and places the SFG-like surface in the free expanded subslot.

The SFG register window is memory-mapped, following the SFG layout used by emulator and hardware references: slot-local `0x3FF0` selects the YM2151 register, and slot-local `0x3FF1` writes YM2151 data or reads YM2151 status. Outside the top register aperture, the virtual SFG subslot reads from the selected 32K BIOS image stored in the Explorer flash payload.

## External references

- NataliaPC MSX File Hunter Browser: https://github.com/nataliapc/msx_filehunterbrowser
- File Hunter service: http://file-hunter.com/
- RBSC SFG_Cartridge project, used as an SFG register-map and cartridge behavior reference: https://github.com/RBSC/SFG_Cartridge
- openMSX Yamaha SFG implementation, used as an emulator behavior reference: https://github.com/openMSX/openMSX

Author: Cristiano Goncalves
Last updated: 06/13/2026

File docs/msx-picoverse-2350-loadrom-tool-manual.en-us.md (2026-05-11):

# MSX PicoVerse 2350 LoadROM Tool Manual (EN-US)

The PicoVerse 2350 cartridge can boot either a MultiROM menu or a single ROM that starts immediately. The LoadROM tool creates a UF2 image that flashes the PicoVerse 2350 with a single ROM payload and the LoadROM firmware.

`loadrom.exe` bundles the Pico firmware blob, a configuration record (game name, mapper code, ROM size, and flash offset), and one MSX ROM file into an RP2350-compatible UF2 image. Copy the generated UF2 to the board in BOOTSEL mode and the MSX will boot straight into the embedded ROM.

For RP2350, the current LoadROM package is:

- `2350/software/loadrom.pio`.

> **Important:** SCC/SCC+ emulation options (`-scc`, `-sccplus`) are supported by the current RP2350 LoadROM package (`2350/software/loadrom.pio`).

---

## Overview

1. **Input**: one `.ROM` file (case-insensitive extension).
2. **Processing**: the tool normalizes the ROM name, detects or forces the mapper, and streams firmware + config + ROM into UF2 blocks.
3. **Output**: a UF2 file (default `loadrom.uf2`) ready for the RP2350 bootloader.

Key characteristics:

- Windows console application.
- Supports ROM sizes from 8 KB up to 16 MB (subject to flash capacity).
- Mapper auto-detection plus optional filename tags to force the mapper.
- Embedded SHA-1 database derived from openMSX `softwaredb.xml` for improved mapper identification.
- Built-in Sunrise IDE Nextor ROM for standalone Nextor boot or Nextor + 1MB PSRAM mapper, using either the on-board microSD card (`-s1`/`-m1`) or a USB flash drive (`-s2`/`-m2`).
- Optional ESP-01 WiFi support for those Sunrise IDE modes via `-w`, adding an embedded ESP8266P system ROM and memio UART backend.
- ROM loading into the 1MB PSRAM mapper through Carnivore2-compatible RAM emulation for `SROM.COM /D15`, using either microSD (`-c1`) or USB mass storage (`-c2`) as the Nextor backend.
- UF2 uses RP2350 family ID (`0xE48BFF59`).

---

## Command-line usage

```
loadrom.exe [options] [romfile]
```

### Options

- `-h`, `--help` : Print usage information and exit.
- `-s1`, `--sunrise-sd` : Build a UF2 with the embedded Sunrise IDE Nextor ROM using the on-board microSD card slot for storage. No external ROM file is needed.
- `-m1`, `--mapper-sd` : Same as `-s1` plus a 1MB memory mapper (64 × 16KB pages) backed by external PSRAM on GPIO47 / QMI CS1 in an expanded sub-slot architecture. No external ROM file is needed.
- `-s2`, `--sunrise-usb` : Build a UF2 with the embedded Sunrise IDE Nextor ROM using the cartridge's USB-C port for storage (USB mass storage). No external ROM file is needed.
- `-m2`, `--mapper-usb` : Same as `-s2` plus a 1MB memory mapper (64 × 16KB pages) backed by external PSRAM on GPIO47 / QMI CS1 in an expanded sub-slot architecture. No external ROM file is needed.
- `-c1`, `--carnivore2-sd` : Build a UF2 with Sunrise IDE Nextor on microSD plus the 1MB PSRAM mapper and Carnivore2 RAM-mode emulation for `SROM.COM /D15`. In this mode, `SROM.COM` can upload a ROM image into the PSRAM-backed mapper and launch it from RAM without reflashing the cartridge.
- `-c2`, `--carnivore2-usb` : Same as `-c1`, but uses USB mass storage on the cartridge's USB-C port as the Nextor backend.
- `-w`, `--wifi` : Enable ESP-01 WiFi support for `-s1`, `-m1`, `-s2`, or `-m2`. This adds the ESP8266P system ROM plus a memory-mapped UART backend expected by the WiFi ROM/software stack.
- `-scc`, `--scc` : Enable SCC (standard) sound emulation. For embedded ROM builds, this applies to Konami SCC or Manbow2 mapper ROMs. With `-c1` or `-c2`, it enables SCC playback for Konami SCC ROMs uploaded later through `SROM.COM /D15`.
- `-sccplus`, `--sccplus` : Enable SCC+ (enhanced) sound emulation. For embedded ROM builds, this applies to Konami SCC or Manbow2 mapper ROMs. With `-c1` or `-c2`, it enables SCC+ playback for compatible ROMs uploaded later through `SROM.COM /D15`.
- `-o <filename>`, `--output <filename>` : Override the UF2 output name (default `loadrom.uf2`).
- Positional argument: the ROM file to embed. Required for normal ROM loading; not accepted with `-s1`/`-m1`/`-s2`/`-m2`/`-c1`/`-c2`.

`-s1`, `-m1`, `-s2`, `-m2`, `-c1`, and `-c2` are mutually exclusive. `-w` is valid only with `-s1`, `-m1`, `-s2`, or `-m2`. `-scc` and `-sccplus` are mutually exclusive. If conflicting options are provided, the tool exits with an error.

### Mapper forcing via filename tags

Append a dot-separated mapper tag before the `.ROM` extension to override detection. Tags are case-insensitive.

Supported tags:
`PLA-16`, `PLA-32`, `KonSCC`, `PLN-48`, `PLN-64`, `ASC-08`, `ASC-16`, `ASC-16X`, `Konami`, `NEO-8`, `NEO-16`, `MANBW2`.

Additional aliases are accepted for backward compatibility: `PL-16`, `PL-32`, `PL-48`, `PL-64`, `PLN-32`, `PLANAR`, `LINEAR`, `LINEAR0`, `PLANAR48`, `PLANAR64`, `MANBOW2`, `MBW-2`.

Example:

```
Penguin Adventure.PL-32.ROM
Space Manbow.KonSCC.rom
```

Tags are case-insensitive. If no valid tag is present, the tool first computes the ROM's SHA-1 hash and looks it up in an embedded database derived from the openMSX `softwaredb.xml`. When a match is found the database mapper type is used directly. Otherwise the tool falls back to heuristic detection.

`SYSTEM` is ignored and cannot be forced.

---

## Typical workflow

1. Place `loadrom.exe` and your ROM file in a working folder.
2. Open a Command Prompt or PowerShell window in that folder.
3. Run the tool:
   ```
   loadrom.exe "Space Manbow.rom" -o space_manbow.uf2
   ```
   Sunrise IDE standalone (Nextor from microSD card):
   ```
   loadrom.exe -s1
   loadrom.exe -s1 -o nextor_sd.uf2
   ```
   Sunrise IDE standalone with WiFi (microSD):
   ```
   loadrom.exe -s1 -w
   loadrom.exe -s1 -w -o nextor_sd_wifi.uf2
   ```
   Sunrise IDE + 1MB PSRAM mapper (microSD):
   ```
   loadrom.exe -m1
   loadrom.exe -m1 -o nextor_mapper_sd.uf2
   ```
   Sunrise IDE + 1MB PSRAM mapper with WiFi (microSD):
   ```
   loadrom.exe -m1 -w
   loadrom.exe -m1 -w -o nextor_mapper_sd_wifi.uf2
   ```
   Sunrise IDE standalone (Nextor from USB flash drive):
   ```
   loadrom.exe -s2
   loadrom.exe -s2 -o nextor_usb.uf2
   ```
   Sunrise IDE standalone with WiFi (USB):
   ```
   loadrom.exe -s2 -w
   loadrom.exe -s2 -w -o nextor_usb_wifi.uf2
   ```
   Sunrise IDE + 1MB PSRAM mapper (USB):
   ```
   loadrom.exe -m2
   loadrom.exe -m2 -o nextor_mapper_usb.uf2
   ```
   Sunrise IDE + 1MB PSRAM mapper with WiFi (USB):
   ```
   loadrom.exe -m2 -w
   loadrom.exe -m2 -w -o nextor_mapper_usb_wifi.uf2
   ```
   Carnivore2 RAM-mode loader for `SROM.COM /D15` (microSD):
   ```
   loadrom.exe -c1
   loadrom.exe -c1 -o srom_c2_sd.uf2
   ```
   Carnivore2 RAM-mode loader for `SROM.COM /D15` (USB):
   ```
   loadrom.exe -c2
   loadrom.exe -c2 -o srom_c2_usb.uf2
   ```
   Carnivore2 RAM-mode loader with SCC audio for SROM-loaded Konami SCC ROMs:
   ```
   loadrom.exe -c1 -scc -o srom_c2_sd_scc.uf2
   loadrom.exe -c2 -scc -o srom_c2_usb_scc.uf2
   ```
   SCC/SCC+ examples:
   ```
   loadrom.exe -scc "Space Manbow.rom"
   loadrom.exe -sccplus "Snatcher.KonSCC.rom"
   ```
4. Review the console output (name, size, mapper, and flash offset).
5. Hold BOOTSEL while connecting the PicoVerse 2350 to USB.
6. Copy the generated UF2 to the `RPI-RP2` drive.
7. Insert the cartridge into the MSX and power on.
8. For `-s1`/`-m1` modes, insert a FAT-formatted microSD card into the cartridge's microSD slot before powering the MSX.
9. For `-s2`/`-m2` modes, connect a USB flash drive (via OTG adapter if needed) to the cartridge's USB-C port before powering the MSX.
10. For `-w` builds, install the ESP-01 module on the PicoVerse 2350 before power-up. The WiFi system ROM and memio UART interface are then available to compatible MSX software.
11. For `-c1`/`-c2` modes, boot Nextor first and then use `SROM.COM /D15` to upload the ROM into the PicoVerse PSRAM mapper. The cartridge is presented as a Carnivore2-compatible RAM target so the uploaded ROM can be launched directly from RAM.

---

## Output layout details

The UF2 image contains:

1. **Firmware blob** – embedded `loadrom` firmware.
2. **Configuration record** (59 bytes):
   - 50 bytes: ROM name (ASCII, padded/truncated).
   - 1 byte : mapper ID and optional SCC/SCC+ flags:
     - Bit 7 (`0x80`) = SCC emulation enabled.
     - Bit 6 (`0x40`) = SCC+ emulation enabled.
       - Bit 5 (`0x20`) = WiFi support enabled for Sunrise IDE modes.
     - Bits 0..5 = base mapper ID.
   - 4 bytes: ROM size (little-endian).
   - 4 bytes: ROM flash offset (little-endian).
3. **ROM payload** – raw ROM data appended after the config record.

The UF2 writer sets `UF2_FLAG_FAMILYID_PRESENT` and uses the RP2350 family ID (`0xE48BFF59`) so the bootloader accepts the image.

---

## Troubleshooting

| Symptom | Possible cause | Resolution |
| --- | --- | --- |
| "Invalid ROM size" | ROM < 8 KB or > 16 MB | Use a valid ROM size. |
| "Failed to detect the ROM type" | Mapper heuristics failed | Add a mapper tag (e.g., `.Konami.ROM`). |
| "Sunrise options are mutually exclusive" | More than one of `-s1`/`-m1`/`-s2`/`-m2`/`-c1`/`-c2` passed | Use only one firmware mode at a time. The `-m` variants add mapper RAM; the `-c` variants add Carnivore2 RAM-mode loading on top of the mapper architecture. |
| "Sunrise options do not accept an external ROM file" | ROM file passed with a Sunrise/Carnivore2 option | Remove the ROM file argument when using `-s1`/`-m1`/`-s2`/`-m2`/`-c1`/`-c2`. |
| "Error: -w/--wifi is supported only with -s1, -m1, -s2 or -m2" | `-w` was used without a supported Sunrise mode | Pair `-w` only with `-s1`, `-m1`, `-s2`, or `-m2`. |
| USB pendrive not detected with `-s2`/`-m2` | VBUS not connected or no OTG adapter | Ensure the USB-C port has VBUS power (use an OTG adapter that supplies VBUS). |
| microSD card not detected with `-s1`/`-m1` | Card not inserted or not FAT-formatted | Insert a FAT16/FAT32-formatted microSD card before powering on. |
| WiFi software does not detect the adapter with `-w` | Missing ESP-01 module, incompatible ESP firmware, or wrong WiFi-capable UF2 | Reflash a `-w` build, verify the ESP-01 is installed, and use software targeting the ESP8266P memio interface. |
| `SROM.COM /D15` does not list the cartridge with `-c1`/`-c2` | Wrong firmware mode or outdated build | Reflash with the correct `-c1` or `-c2` UF2 and use a build that includes Carnivore2 RAM-mode emulation. |
| `SROM.COM /D15` upload succeeds but the launched ROM fails | ROM/runtime compatibility issue in the emulation path | Try the latest firmware build and retest; this mode depends on Carnivore2-compatible bank/window presentation from PSRAM. |
| "Disk driver not found. System halted." with `-m1`/`-m2` | Firmware issue | Rebuild with latest firmware; check that the PIO bus init guard is present. |
| "Warning: -scc flag ignored" | ROM is not Konami SCC or Manbow2 mapper, or the selected Nextor mode is not `-c1`/`-c2` | Use a Konami SCC or Manbow2 ROM, or pair `-scc` with `-c1`/`-c2` for SROM-loaded Konami SCC titles. |
| "Warning: -sccplus flag ignored" | ROM is not Konami SCC or Manbow2 mapper, or the selected Nextor mode is not `-c1`/`-c2` | Use a compatible ROM, or pair `-sccplus` with `-c1`/`-c2` for SROM-loaded SCC+ titles. |
| "Error: -scc and -sccplus are mutually exclusive" | Both options were passed together | Use only one of the two options. |
| UF2 not recognized | Not in BOOTSEL, or wrong file | Enter BOOTSEL and copy the UF2 again. |
| Name truncated in menu | Filename too long | Shorten the filename. |

---

## Known limitations

- Only one ROM per UF2 (use the MultiROM or Explorer tools for multiple titles).
- The `-s1` and `-m1` options require a FAT-formatted microSD card in the cartridge's microSD slot.
- The `-s2` and `-m2` options require a USB flash drive connected to the cartridge's USB-C port (via OTG adapter) for disk access.
- The `-w` option is available only with `-s1`, `-m1`, `-s2`, or `-m2`.
- `-w` requires an ESP-01 module and compatible ESP-side firmware; the PicoVerse firmware provides the ROM mapping and serial transport, not the ESP application layer itself.
- The `-m1` and `-m2` options provide 1MB mapper RAM (64 × 16KB pages) backed by external PSRAM on GPIO47 / QMI CS1.
- The `-c1` and `-c2` options reuse that same 1MB PSRAM-backed mapper RAM and expose it through Carnivore2-compatible RAM-mode behavior intended for `SROM.COM /D15`.
- The `-w` Sunrise IDE WiFi system-ROM option is not currently exposed in Explorer or the `-c1`/`-c2` Carnivore2 loader modes. MultiROM supports `-w` for `-s1`, `-m1`, `-s2`, and `-m2` Nextor entries. Explorer has its own built-in ESP-01 path for File Hunter browsing and WiFi setup.
- The `-c1` and `-c2` modes are loader modes, not direct ROM-embedding modes. They boot Nextor first; the ROM is uploaded later from DOS into PSRAM.
- SCC/SCC+ audio for `SROM.COM /D15` uploads is enabled by building the loader UF2 with `-c1/-c2` plus `-scc` or `-sccplus` before flashing the cartridge.
- Linux/macOS binaries are not provided (use Windows or build from source).
- The tool does not verify ROM integrity beyond size and mapper heuristics.
- SCC/SCC+ flags are applied for Konami SCC mapper (type 3) and Manbow2 mapper (type 14) ROMs; otherwise they are ignored with a warning.
- SCC/SCC+ emulation is available in the current RP2350 LoadROM package.
- Excessive flashing can wear out flash memory.

---

## Future improvements

- Cross-platform builds (Linux/macOS).
- Optional ROM integrity checks.
- GUI wrapper for mapper forcing.
- Additional mapper heuristics.

Author: Cristiano Almeida Goncalves  
Last updated: 04/21/2026

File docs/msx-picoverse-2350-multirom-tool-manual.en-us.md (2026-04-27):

# MSX PicoVerse 2350 MultiROM Tool Manual (EN-US)

The PicoVerse 2350 MultiROM tool creates a UF2 image that flashes the PicoVerse 2350 cartridge with:
- The PicoVerse 2350 MultiROM firmware.
- The MSX MultiROM menu ROM.
- A configuration table describing each ROM entry.
- The ROM payloads themselves.

Use this tool when you want to bundle multiple MSX ROM files into a single UF2 for the PicoVerse 2350.

## Requirements

- A Windows PC (the distributed binary is a Windows console application).
- Your MSX ROM files in a single folder (no subdirectories).
- A PicoVerse 2350 cartridge and a USB-C cable.

## Limits

- Maximum ROM files per image: 128.
- Maximum combined ROM payload size: ~14 MB.
- Per-ROM name length in menu: 50 characters (longer names are truncated in the menu list).

## Basic workflow

1. Place all `.ROM` files you want to include in a single folder.
2. Run the tool in that folder.
3. Copy the generated UF2 file to the PicoVerse 2350 in BOOTSEL mode.
4. Insert the cartridge into the MSX and power on to access the MultiROM menu.

## Command-line usage

```
multirom.exe [options]
```

### Options

| Flag | Description |
|---|---|
| `-h`, `--help` | Show usage help and exit. |
| `-o <filename>`, `--output <filename>` | Set UF2 output filename (default `multirom.uf2`). |
| `-s1`, `--sunrise-sd` | Include Sunrise IDE Nextor ROM (microSD card). |
| `-m1`, `--mapper-sd` | Include Sunrise IDE Nextor ROM + 1MB PSRAM mapper (microSD card). |
| `-s2`, `--sunrise-usb` | Include Sunrise IDE Nextor ROM (USB pendrive). |
| `-m2`, `--mapper-usb` | Include Sunrise IDE Nextor ROM + 1MB PSRAM mapper (USB pendrive). |
| `-c1`, `--carnivore2-sd` | Include Sunrise IDE Nextor ROM + 1MB PSRAM mapper + Carnivore2 RAM-mode emulation (microSD card). |
| `-c2`, `--carnivore2-usb` | Include Sunrise IDE Nextor ROM + 1MB PSRAM mapper + Carnivore2 RAM-mode emulation (USB pendrive). |
| `-scc`, `--scc` | Enable SCC sound emulation for Konami SCC and Manbow2 ROMs, and for ROMs uploaded via SROM in `-c1`/`-c2` Carnivore2 modes. |
| `-sccplus`, `--sccplus` | Enable SCC+ (enhanced) sound emulation for Konami SCC and Manbow2 ROMs, and for ROMs uploaded via SROM in `-c1`/`-c2` Carnivore2 modes. |
| `-w`, `--wifi` | Add ESP-01 WiFi BIOS sub-slot to every `-s1`/`-m1`/`-s2`/`-m2` Nextor entry. Requires at least one of those flags; the WiFi sub-slot is not added to `-c1`/`-c2` Carnivore2 entries. |

The Sunrise / Carnivore2 options can be freely combined. Each adds a separate SYSTEM entry to the menu, so you can pick the desired Nextor / Carnivore2 mode on the MSX. When `-scc` or `-sccplus` is used together with `-c1`/`-c2`, the processing list shows the Carnivore2 entry with a trailing `+SCC` or `+SCC+` marker (the SCC flag is encoded in the entry's mapper byte and applies only to the Carnivore2 entries; other Sunrise modes are unaffected). When `-w` is combined with `-s1`/`-m1`/`-s2`/`-m2`, those entries are listed with a trailing `+WiFi` marker and the embedded ESP8266P system ROM is appended right after each entry's Sunrise ROM payload in flash.

### Examples

Scan for ROMs with no Nextor entries:

```
multirom.exe
```

Include both Sunrise IDE SD and Sunrise IDE USB entries alongside scanned ROMs:

```
multirom.exe -s1 -s2
```

Include Sunrise IDE + mapper over microSD, with SCC emulation enabled for compatible ROMs:

```
multirom.exe -m1 -scc
```

Include Carnivore2 RAM-mode (USB) with SCC+ emulation for SROM-uploaded Konami SCC ROMs, alongside scanned ROMs:

```
multirom.exe -c2 -sccplus
```

Include Sunrise IDE + mapper over USB with ESP-01 WiFi support, alongside scanned ROMs:

```
multirom.exe -m2 -w
```

## Flashing the UF2

1. Hold BOOTSEL on the PicoVerse 2350 while connecting USB.
2. The `RPI-RP2` drive appears.
3. Copy `multirom.uf2` to the drive.
4. The drive disconnects automatically after flashing.

## ROM mapper detection

The tool analyzes each ROM to determine the correct mapper type, applying the following steps in order:

1. **SHA-1 database lookup** — The ROM's SHA-1 hash is checked against an embedded database derived from the openMSX `softwaredb.xml`. A match overrides the heuristic and returns the definitive mapper type.

2. **Signature checks** — Special byte signatures are checked:
   - 16 KB ROM with `AB` header → Plain16.
   - ≤ 32 KB ROM with `AB` header → Plain32 (or Planar48 if `AB` also at 0x4000).
   - `ASCII16X` at offset 16 → ASCII16-X.
   - `ROM_NEO8` / `ROM_NE16` at offset 16 → NEO-8 / NEO-16.
   - 512 KB ROM with `Manbow 2` at offset 0x28000 → Manbow2.
   - ≤ 48 KB ROM with `AB` at 0x4000 → Planar48.
   - 64 KB ROM with `AB` at 0x4000 → Planar64.

3. **Heuristic scoring** — For ROMs larger than 32 KB, the tool scans for Z80 `ld (nnnn),a` instructions referencing mapper register addresses. Each candidate address increments the score for its associated mapper type. The mapper with the highest score wins (ties broken by later type, matching openMSX).

4. **Fallback** — 64 KB ROMs with an `AB` header and no detected mapper writes are classified as Planar64. Larger ROMs with no detected writes use raw address density as a secondary hint.

## Mapper tag forcing

If auto-detection fails or you want to override it, add a mapper tag to the filename before `.ROM`. Tags are case-insensitive.

Forceable tags:

| Tag | Mapper | Aliases |
|-----|---|---|
| `PLA-16` | Plain 16 KB | `PL-16` |
| `PLA-32` | Plain 32 KB | `PL-32` |
| `KonSCC` | Konami SCC | |
| `PLN-48` | Planar 48 KB | `PL-48`, `LINEAR`, `LINEAR0`, `PLANAR48`, `PLN-32`, `PLANAR32` |
| `ASC-08` | ASCII 8 KB | |
| `ASC-16` | ASCII 16 KB | |
| `ASC16X` | ASCII16-X (flash) | |
| `Konami` | Konami (no SCC) | |
| `NEO-8` | NEO 8 KB | |
| `NEO-16` | NEO 16 KB | |
| `PLN-64` | Planar 64 KB | `PL-64`, `PLANAR64` |
| `MANBW2` | Manbow2 | `MANBOW2`, `MBW-2` |

`SYSTEM` tags are ignored (Sunrise IDE entries cannot be forced via filename).

Example:

```
Knight Mare.PLA-32.ROM
```

## Supported mapper types

| # | Type | Tag | Notes |
|---|---|-----|---|
| 1 | Plain 16 KB | `PLA-16` | Single 16 KB bank at 4000h–7FFFh |
| 2 | Plain 32 KB | `PLA-32` | 32 KB at 4000h–BFFFh |
| 3 | Konami SCC | `KonSCC` | 8 KB banking; SCC auto-enabled |
| 4 | Planar 48 KB | `PLN-48` | Linear mapping for 32/48 KB ROMs with AB at 0x4000 |
| 5 | ASCII 8 KB | `ASC-08` | 8 KB bank switching |
| 6 | ASCII 16 KB | `ASC-16` | 16 KB bank switching |
| 7 | Konami | `Konami` | 8 KB banking without SCC |
| 8 | NEO 8 KB | `NEO-8` | FlashROM-compatible 8 KB banking |
| 9 | NEO 16 KB | `NEO-16` | FlashROM-compatible 16 KB banking |
| 10 | Sunrise IDE (USB) | SYSTEM | Nextor 2.1.4 Sunrise IDE via USB (`-s2`) |
| 11 | Sunrise IDE + Mapper (USB) | SYSTEM | Nextor + 1MB PSRAM mapper via USB (`-m2`) |
| 12 | ASCII16-X | `ASC16X` | ASCII16 + SST-compatible flash commands |
| 13 | Planar 64 KB | `PLN-64` | Full 64 KB linear mapping (0000h–FFFFh) |
| 14 | Manbow2 | `MANBW2` | Konami SCC banking + AM29F040B flash emulation |
| 15 | Sunrise IDE (SD) | SYSTEM | Nextor 2.1.4 Sunrise IDE via microSD (`-s1`) |
| 16 | Sunrise IDE + Mapper (SD) | SYSTEM | Nextor + 1MB PSRAM mapper via microSD (`-m1`) |
| 17 | Carnivore2 (SD) | SYSTEM | Nextor + 1MB mapper + Carnivore2 RAM-mode emulation via microSD (`-c1`) |
| 18 | Carnivore2 (USB) | SYSTEM | Nextor + 1MB mapper + Carnivore2 RAM-mode emulation via USB (`-c2`) |

## SCC / SCC+ emulation

- ROMs detected or forced as `KonSCC` (mapper 3) or `MANBW2` (mapper 14) can have SCC/SCC+ sound emulation.
- For Carnivore2 modes (`-c1` / `-c2`), the SCC flag applies to ROMs uploaded into the cartridge through the Carnivore2 SROM utility (`c2ramldr`) — the emulator listens to the standard Konami SCC / SCC+ register windows whenever an SCC-class ROM has been written to PSRAM.
- Use `-scc` for standard SCC emulation or `-sccplus` for enhanced SCC+ mode.
- The `-scc` and `-sccplus` flags are mutually exclusive.
- The flags apply globally to the build; non-SCC mapper types ignore them.
- Audio is output through the I2S DAC connected to the RP2350.

## Sunrise IDE Nextor

The Sunrise IDE options embed the Nextor 2.1.4 Sunrise IDE kernel ROM (128 KB) into the MultiROM image. Each option adds a SYSTEM entry that appears in the MSX menu alongside regular ROM entries.

### USB modes (`-s2`, `-m2`)

- Storage is accessed via USB mass storage (flash drives, USB-to-SD adapters) through the cartridge's USB-C port.
- Core 1 runs the TinyUSB USB host stack with asynchronous MSC read/write.
- Device info for ATA IDENTIFY comes from the USB SCSI INQUIRY response.

### microSD modes (`-s1`, `-m1`)

- Storage is accessed via the on-board microSD card slot (SPI at 31.25 MHz).
- Real card identification (OEM, product name, revision) from the SD CID register is shown during Nextor boot.

### Mapper modes (`-m1`, `-m2`)

- Combines Nextor Sunrise IDE with a 1MB PSRAM memory mapper (64 × 16 KB pages).
- Uses an expanded sub-slot architecture: sub-slot 0 serves the Nextor ROM, sub-slot 1 provides mapper RAM.
- Mapper page registers (I/O ports FC–FF) are intercepted via PIO1.
- A bootstrap ROM phase ensures a clean cold-boot before the expanded-slot mapper is activated.

### Carnivore2 modes (`-c1`, `-c2`)

- Builds on the `-m1` / `-m2` infrastructure and adds an emulation of the Carnivore2 RAM-mode cartridge so SROM utilities (`c2ramldr`, `bdosldr`, etc.) can upload Konami / ASCII / Sunrise-mapper ROMs into the cartridge's PSRAM and launch them.
- Sub-slot layout matches the real Carnivore2 (`Sltsl_C` / `Sltsl_D` / `Sltsl_M`):
  - Sub-slot 0: Carnivore2 register window + bank windows (1 MB SROM upload target).
  - Sub-slot 1: Nextor 2.1.4 Sunrise IDE BIOS (USB or microSD backend, same as `-s1`/`-s2`).
  - Sub-slot 2: 1 MB MSX memory mapper RAM (same as `-m1`/`-m2`).
- Implements the Carnivore2 register block (`CardMDR`, `R1..R4` configs with `Mask/Addr/Reg/Mult/MaskR/AdrD`, `AddrFR`), the port `0xF0+PFXN` `'C'/'S'` handshake used by SROM, the AMD autoselect chip-ID probe (`M29W640GB`) used by `c2ramldr`, and the `CMFCCFRC` firmware signature overlay at `0x4010-0x4017`.
- When `-scc` or `-sccplus` is added, the cartridge also emulates the Konami SCC / SCC+ register window so SROM-uploaded SCC-class ROMs play music. Audio is mixed by the same I2S path used by the regular `-scc` modes (PIO1 SM2 + auto-claimed DMA channel; service is polled from the storage Core 1 task loop so it does not block USB / SD I/O).
- The 1 MB Carnivore2 RAM region is allocated from the same PSRAM bump allocator that backs the mapper RAM, so the cartridge needs the on-board PSRAM to be present and initialised. If allocation fails the firmware halts at the dispatch entry instead of booting.

## Menu usage (on MSX)

- Up/Down: move selection.
- Left/Right: change pages.
- Enter/Space: load selected ROM.
- H: show help screen.

SYSTEM entries (Sunrise IDE) appear alongside regular ROM entries and are selected the same way.

## Notes

- Only ROM files in the current folder are included (no subfolders).
- Unsupported or invalid ROMs are skipped with a message.
- Manbow2 save data is volatile (SRAM-backed, lost on power-off).
- ASCII16-X flash write emulation is SRAM-backed (volatile).
- The Sunrise options (`-s1`, `-m1`, `-s2`, `-m2`, `-c1`, `-c2`) can be combined — each adds its own menu entry.

Author: Cristiano Almeida Goncalves
Last updated: 04/26/2026

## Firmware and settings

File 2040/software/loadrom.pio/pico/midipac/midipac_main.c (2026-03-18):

// MSX PICOVERSE PROJECT
// (c) 2026 Cristiano Goncalves
// The Retro Hacker
//
// midipac_main.c - PSG-to-MIDI conversion firmware (MIDI-PAC)
//
// Passively intercepts all AY-3-8910 PSG register writes from MSX software
// and converts them in real time to MIDI events sent to a USB MIDI device
// (e.g., Roland SoundCanvas) connected to the Pico's USB port.
//
// Architecture:
//   Core 0: PIO1 IRQ handler captures PSG I/O writes (ports 0xA0-0xA1).
//           Maintains PSG shadow registers and converts PSG events to MIDI
//           messages queued in a lock-free ring buffer.
//   Core 1: TinyUSB host task polls USB MIDI device. Drains the TX ring
//           buffer, formats USB-MIDI event packets, and sends them to the
//           USB MIDI device. Also runs a periodic envelope processor.
//
// PSG-to-MIDI conversion is based on the AY-3-8910/YM2149 hardware
// specifications (GI datasheet) and verified against the ayumi emulator
// (Peter Sovietov) used by the aymidi project (berarma/aymidi).
//
// This work is licensed under a "Creative Commons Attribution-NonCommercial-
// ShareAlike 4.0 International License".
// https://creativecommons.org/licenses/by-nc-sa/4.0/

#include <string.h>
#include <stdlib.h>
#include "pico/stdlib.h"
#include "pico/multicore.h"
#include "hardware/clocks.h"
#include "hardware/pio.h"
#include "hardware/irq.h"
#include "hardware/sync.h"
#include "hardware/timer.h"
#include "tusb.h"
#include "midipac.h"
#include "usb_midi_host.h"
#include "msx_midipac.pio.h"

// Include the pre-computed frequency table
#include "psg_freq_table.h"

#define MIDI_WIRE_BYTE_US 320
#define MIDI_TONE_BEND_QUANTUM 16
#define MIDI_TONE_EXPR_QUANTUM 4
#define MIDI_TONE_BEND_MIN_INTERVAL_US 500
#define MIDI_TONE_EXPR_MIN_INTERVAL_US 8000

// 50 Hz frame processing matches the intent of common MSX music engines,
// avoids reacting to every individual PSG register write, and keeps vibrato
// as pitch bend instead of repeated note retriggers.
#define PSG_FRAME_RATE_HZ           50
#define PSG_FRAME_TICK_US           (1000000 / PSG_FRAME_RATE_HZ)
#define PSG_BEND_RATE_HZ            200
#define PSG_BEND_TICK_US            (1000000 / PSG_BEND_RATE_HZ)
#define MIDI_VIBRATO_BEND_ONLY_DELTA_X256 256
#define TONE_CENTER_WINDOW_X256     192
#define TONE_STABLE_RETRIGGER_FRAMES 3
#define TONE_HISTORY_LEN            4
#define NOISE_DIVISOR_SCALE         8
#define NOISE_DIVISOR_BIAS          16

// -----------------------------------------------------------------------
// TX ring buffer: Core 0 (IRQ) writes, Core 1 reads
// Single-producer single-consumer — safe without locks on RP2040
// -----------------------------------------------------------------------
static volatile uint8_t tx_ring_buf[MIDIPAC_TX_BUFSIZE];
static volatile uint32_t tx_ring_head;   // Written by Core 0
static volatile uint32_t tx_ring_tail;   // Written by Core 1

static inline bool __not_in_flash_func(tx_ring_put)(uint8_t byte) {
    uint32_t next = (tx_ring_head + 1) & (MIDIPAC_TX_BUFSIZE - 1);
    if (next == tx_ring_tail) return false;  // Full — drop byte
    tx_ring_buf[tx_ring_head] = byte;
    __dmb();
    tx_ring_head = next;
    return true;
}

static inline bool tx_ring_get(uint8_t *byte) {
    if (tx_ring_head == tx_ring_tail) return false;
    *byte = tx_ring_buf[tx_ring_tail];
    __dmb();
    tx_ring_tail = (tx_ring_tail + 1) & (MIDIPAC_TX_BUFSIZE - 1);
    return true;
}

// Number of free bytes in the TX ring (safe to call from either core)
static inline uint32_t __not_in_flash_func(tx_ring_free)(void) {
    return (tx_ring_tail - tx_ring_head - 1) & (MIDIPAC_TX_BUFSIZE - 1);
}

// Hardware spinlock: both Core 0 (PIO IRQ) and Core 1 (envelope tick)
// produce into the ring buffer. The spinlock makes each MIDI message
// atomic so bytes from different messages never interleave.
static spin_lock_t *tx_ring_lock;

// -----------------------------------------------------------------------
// MIDI message helpers — queue raw MIDI bytes into the ring buffer.
// Admission control: the entire message is dropped if there isn't
// enough room, preventing partial (corrupt) MIDI messages.
// -----------------------------------------------------------------------

static inline bool __not_in_flash_func(midi_send_3)(uint8_t status, uint8_t d1, uint8_t d2) {
    uint32_t save = spin_lock_blocking(tx_ring_lock);
    bool ok = (tx_ring_free() >= 3);
    if (ok) {
        tx_ring_put(status);
        tx_ring_put(d1);
        tx_ring_put(d2);
    }
    spin_unlock(tx_ring_lock, save);
    return ok;
}

static inline bool __not_in_flash_func(midi_send_2)(uint8_t status, uint8_t d1) {
    uint32_t save = spin_lock_blocking(tx_ring_lock);
    bool ok = (tx_ring_free() >= 2);
    if (ok) {
        tx_ring_put(status);
        tx_ring_put(d1);
    }
    spin_unlock(tx_ring_lock, save);
    return ok;
}

// -----------------------------------------------------------------------
// PSG shadow state (maintained in Core 0 IRQ context)
// -----------------------------------------------------------------------
static volatile uint8_t psg_addr_latch;         // Currently selected PSG register
static uint16_t psg_reg[PSG_REG_COUNT];         // Shadow of all 14 PSG registers
static volatile uint32_t psg_reg_seq;           // Seqlock for coherent snapshots

// Per-channel MIDI state
static uint16_t channel_freq[MIDI_CH_COUNT];    // Current PSG frequency divisor
static uint8_t  midi_note[MIDI_CH_COUNT];       // Current MIDI note (0 = off)
static uint16_t midi_pitchbend[MIDI_CH_COUNT];  // Current pitch bend value
static uint8_t  midi_program[MIDI_CH_COUNT];    // Current MIDI program
static uint8_t  midi_expr[MIDI_CH_COUNT];       // Current MIDI CC#11 expression
static uint8_t  psg_tone_mix[3];                // PSG tone enable per voice
static uint8_t  psg_noise_mix[3];               // PSG noise enable per voice
static uint16_t midi_pitchbend_pending[3];      // Deferred tone pitch bend target
static uint8_t  midi_pitchbend_dirty[3];        // Deferred tone pitch bend pending
static uint8_t  midi_expr_pending[3];           // Deferred tone expression target
static uint8_t  midi_expr_dirty[3];             // Deferred tone expression pending
static uint32_t midi_pitchbend_last_us[3];      // Last tone bend send timestamp
static uint32_t midi_expr_last_us[3];           // Last tone expression send timestamp
static uint16_t tone_last_period[3];            // Last processed tone period per PSG voice
static uint8_t  env_level[3];                   // Current envelope-derived level (0-127)
static uint16_t tone_note_history[3][TONE_HISTORY_LEN];
static uint8_t  tone_note_history_count[3];
static uint8_t  tone_pending_note[3];
static uint8_t  tone_pending_count[3];

// PSG volume (0-15) to MIDI CC value.
// Smoother curve with better low-level presence for SC-55 arrangement quality.
static const uint8_t psg_vol_to_midi[16] = {
    0, 18, 30, 40, 50, 58, 66, 74, 82, 90, 98, 106, 113, 119, 124, 127
};

// Envelope volume (0-31) to MIDI CC value.
// Aligned with the fixed-volume table's feel; finer granularity for 5-bit envelope.
static const uint8_t env_vol_to_midi[32] = {
     0,  8, 13, 18, 23, 28, 33, 38, 42, 47, 51, 55, 60, 64, 68, 72,
    76, 80, 84, 88, 92, 95, 99,103,107,110,114,117,120,123,125,127
};

static const uint8_t tone_program[3] = {
    MIDIPAC_MELODIC_PROG_A,
    MIDIPAC_MELODIC_PROG_B,
    MIDIPAC_MELODIC_PROG_C
};

static const uint8_t tone_pan[3] = {
    60, 64, 68
};

static const uint8_t tone_reverb[3] = {
    0, 0, 0
};

static const uint8_t tone_chorus[3] = {
    0, 0, 0
};

// Envelope state
static int      soundenv;                       // Current envelope shape (0-15)
static int      soundenvspeed;                  // Envelope speed (fixed-point)
static int      soundenvspeed_toolarge;         // Overflow flag
static int      usesoundenv[3];                 // Per-tone-channel envelope enable
static int      soundenvcounter[3];             // Per-tone-channel envelope counter

// Silence detection state
static uint32_t all_silent_since_us;             // Timestamp when all channels went quiet
static uint8_t  all_sound_off_sent;              // 1 after CC#120 sent for silence

// Noise frequency → GM percussion drum note mapping.
// 6 bands × 3 voices gives each PSG voice a distinct drum note per band.
// Band boundaries are on the synthetic divisor (R6 * 8 + 16).
static const uint8_t noise_drum_notes[6][3] = {
    {42, 44, 37},   // Band 0 (div ≤  24): Closed HiHat, Pedal HiHat, Side Stick
    {46, 51, 56},   // Band 1 (div ≤  48): Open HiHat, Ride Cymbal, Cowbell
    {38, 40, 39},   // Band 2 (div ≤  80): Snare, Electric Snare, Clap
    {47, 45, 48},   // Band 3 (div ≤ 128): Mid Tom, Low Tom, Hi-Mid Tom
    {36, 41, 43},   // Band 4 (div ≤ 176): Bass Drum, Low Floor Tom, Hi Floor Tom
    {35, 36, 41}    // Band 5 (div > 176): Acoustic Bass Drum, Bass Drum, Low Floor Tom
};

static void psg_snapshot_read(uint16_t *snapshot) {
    uint32_t seq_start;
    uint32_t seq_end;

    do {
        seq_start = psg_reg_seq;
        while (seq_start & 1u) {
            seq_start = psg_reg_seq;
        }
        __dmb();
        memcpy(snapshot, (const void *)psg_reg, sizeof(psg_reg));
        __dmb();
        seq_end = psg_reg_seq;
    } while (seq_start != seq_end || (seq_end & 1u));
}

// -----------------------------------------------------------------------
// MIDI event generators (called from IRQ context — must be fast)
// -----------------------------------------------------------------------

static inline uint8_t __not_in_flash_func(midi_tx_channel)(uint8_t channel) {
    return (channel >= MIDI_CH_NOISE_A) ? MIDI_DRUM_CH : channel;
}

static inline uint8_t __not_in_flash_func(noise_voice_index)(uint8_t channel) {
    return (uint8_t)(channel - MIDI_CH_NOISE_A);
}

static inline uint8_t __not_in_flash_func(midi_psg_level)(uint8_t channel, uint8_t val) {
    if (channel >= MIDI_CH_NOISE_A) {
        // Keep percussion clearly audible but behind the three melodic PSG
        // channels, otherwise channel 10 dominates the mix on GM modules.
        return (uint8_t)((val * 11u) / 16u);
    }
    return val;
}

static inline uint8_t __not_in_flash_func(tone_channel_index)(uint8_t channel) {
    return channel;
}

static inline uint8_t __not_in_flash_func(quantize_u7)(uint8_t value, uint8_t quantum) {
    uint16_t rounded = (uint16_t)value + (uint16_t)(quantum / 2u);
    rounded = (rounded / quantum) * quantum;
    if (rounded > 127u) rounded = 127u;
    return (uint8_t)rounded;
}

static inline uint16_t __not_in_flash_func(quantize_pitchbend)(uint16_t value) {
    uint32_t rounded = (uint32_t)value + (MIDI_TONE_BEND_QUANTUM / 2u);
    rounded = (rounded / MIDI_TONE_BEND_QUANTUM) * MIDI_TONE_BEND_QUANTUM;
    if (rounded > 16383u) rounded = 16383u;
    return (uint16_t)rounded;
}

static void __not_in_flash_func(midi_expression_apply)(uint8_t channel, uint8_t val, uint32_t now_us) {
    if (midi_expr[channel] != val) {
        midi_send_3(0xB0 | channel, 11, val);  // CC#11 Expression
        midi_expr[channel] = val;
    }
    midi_expr_last_us[tone_channel_index(channel)] = now_us;
    midi_expr_dirty[tone_channel_index(channel)] = 0;
}

static void __not_in_flash_func(midi_pitch_bend_apply)(uint8_t channel, uint16_t value, uint32_t now_us) {
    if (midi_pitchbend[channel] != value) {
        midi_send_3(0xE0 | channel, value & 0x7F, (value >> 7) & 0x7F);
        midi_pitchbend[channel] = value;
    }
    midi_pitchbend_last_us[tone_channel_index(channel)] = now_us;
    midi_pitchbend_dirty[tone_channel_index(channel)] = 0;
}

static void midi_flush_deferred_tone_controls(uint32_t now_us) {
    for (uint8_t channel = MIDI_CH_TONE_A; channel <= MIDI_CH_TONE_C; channel++) {
        uint8_t idx = tone_channel_index(channel);

        if (midi_expr_dirty[idx] &&
            (now_us - midi_expr_last_us[idx]) >= MIDI_TONE_EXPR_MIN_INTERVAL_US) {
            midi_expression_apply(channel, midi_expr_pending[idx], now_us);
        }

        if (midi_pitchbend_dirty[idx] &&
            (now_us - midi_pitchbend_last_us[idx]) >= MIDI_TONE_BEND_MIN_INTERVAL_US) {
            midi_pitch_bend_apply(channel, midi_pitchbend_pending[idx], now_us);
        }
    }
}

static void __not_in_flash_func(midi_expression_set)(uint8_t channel, uint8_t val) {
    val = midi_psg_level(channel, val);
    if (channel >= MIDI_CH_NOISE_A) {
        midi_expr[channel] = val;
        return;
    }

    val = quantize_u7(val, MIDI_TONE_EXPR_QUANTUM);
    if (midi_expr[channel] != val) {
        uint8_t idx = tone_channel_index(channel);
        uint32_t now_us = time_us_32();
        uint8_t current = midi_expr[channel];

        midi_expr_pending[idx] = val;

        if (val == 0 || current == 0 || (uint32_t)(now_us - midi_expr_last_us[idx]) >= MIDI_TONE_EXPR_MIN_INTERVAL_US) {
            midi_expression_apply(channel, val, now_us);
        } else {
            midi_expr_dirty[idx] = 1;
        }
    }
}

static void __not_in_flash_func(midi_note_off)(uint8_t channel) {
    if (midi_note[channel]) {
        midi_send_3(0x90 | midi_tx_channel(channel), midi_note[channel], 0);
        midi_note[channel] = 0;
        if (channel < MIDI_CH_NOISE_A) {
            uint8_t idx = tone_channel_index(channel);
            midi_expr_dirty[idx] = 0;
            midi_pitchbend_dirty[idx] = 0;
        }
    }
}

static void __not_in_flash_func(midi_note_on_velocity)(uint8_t channel, uint8_t note, uint8_t velocity) {
    if (note == 0 || note > 127) return;
    if (midi_note[channel] == note) return;

    midi_note_off(channel);
    midi_send_3(0x90 | midi_tx_channel(channel), note, velocity);
    midi_note[channel] = note;
}

static uint8_t __not_in_flash_func(midi_note_velocity)(uint8_t channel) {
    uint16_t base = (channel >= MIDI_CH_NOISE_A) ? 34 : 56;
    uint16_t span = (channel >= MIDI_CH_NOISE_A) ? 52 : 72;
    uint16_t velocity = base + (midi_expr[channel] * span) / 127;
    if (velocity > 127) velocity = 127;
    return (uint8_t)velocity;
}

static void __not_in_flash_func(midi_note_on)(uint8_t channel, uint8_t note) {
    if (midi_note[channel] != note) {
        midi_note_off(channel);
        if (note > 0 && note <= 127) {
            midi_send_3(0x90 | midi_tx_channel(channel), note, midi_note_velocity(channel));
            midi_note[channel] = note;
        }
    }
}

static void __not_in_flash_func(midi_pitch_bend)(uint8_t channel, uint16_t value) {
    if (channel >= MIDI_CH_NOISE_A) {
        return;
    }

    value = quantize_pitchbend(value);

    if (midi_pitchbend[channel] != value) {
        uint8_t idx = tone_channel_index(channel);
        uint32_t now_us = time_us_32();

        midi_pitchbend_pending[idx] = value;

        if (midi_note[channel] == 0 || (uint32_t)(now_us - midi_pitchbend_last_us[idx]) >= MIDI_TONE_BEND_MIN_INTERVAL_US) {
            midi_pitch_bend_apply(channel, value, now_us);
        } else {
            midi_pitchbend_dirty[idx] = 1;
        }
    }
}

static void __not_in_flash_func(midi_pitch_bend_force)(uint8_t channel, uint16_t value) {
    if (channel >= MIDI_CH_NOISE_A) {
        return;
    }

    value = quantize_pitchbend(value);
    midi_pitchbend_pending[tone_channel_index(channel)] = value;
    midi_pitch_bend_apply(channel, value, time_us_32());
}

static void __not_in_flash_func(midi_program_change)(uint8_t channel, uint8_t prog) {
    midi_send_2(0xC0 | channel, prog);
}

static void __not_in_flash_func(midi_program_set)(uint8_t channel, uint8_t prog) {
    if (channel >= MIDI_CH_NOISE_A) {
        return;
    }

    if (midi_program[channel] != prog) {
        midi_program_change(channel, prog);
        midi_program[channel] = prog;
    }
}

// -----------------------------------------------------------------------
// PSG-to-MIDI conversion functions
// -----------------------------------------------------------------------

static inline uint16_t psg_tone_period(const uint16_t *snapshot, uint8_t voice) {
    uint16_t fine = snapshot[PSG_REG_FREQ_A_LO + (voice * 2u)] & 0x00FFu;
    uint16_t coarse = snapshot[PSG_REG_FREQ_A_HI + (voice * 2u)] & 0x000Fu;
    uint16_t period = (coarse << 8) | fine;
    return (period == 0) ? 1u : period;
}

static inline uint8_t psg_voice_level(const uint16_t *snapshot, uint8_t voice) {
    uint8_t volume_reg = snapshot[PSG_REG_VOL_A + voice] & 0x1Fu;
    if (volume_reg & 0x10u) {
        return env_level[voice];
    }
    return psg_vol_to_midi[volume_reg & 0x0Fu];
}

static inline uint8_t psg_voice_velocity(const uint16_t *snapshot, uint8_t voice, uint8_t level) {
    uint8_t volume_reg = snapshot[PSG_REG_VOL_A + voice] & 0x1Fu;
    if (volume_reg & 0x10u) {
        uint16_t velocity = ((uint16_t)level * 120u) / 127u;
        return (velocity == 0) ? 1u : (uint8_t)velocity;
    }

    uint16_t velocity = (uint16_t)(volume_reg & 0x0Fu) * 8u;
    if (velocity > 127u) velocity = 127u;
    return (velocity == 0) ? 1u : (uint8_t)velocity;
}

static inline uint16_t midi_wheel_for_anchor(uint8_t anchor_note, uint16_t fine_note_x256) {
    int32_t delta_x256 = (int32_t)fine_note_x256 - ((int32_t)anchor_note << 8);
    int32_t wheel = 8192 + (delta_x256 * 16);
    if (wheel < 0) return 0;
    if (wheel > 16383) return 16383;
    return (uint16_t)wheel;
}

static void tone_history_push(uint8_t voice, uint16_t fine_note_x256) {
    memmove(&tone_note_history[voice][0],
            &tone_note_history[voice][1],
            sizeof(tone_note_history[voice][0]) * (TONE_HISTORY_LEN - 1));
    tone_note_history[voice][TONE_HISTORY_LEN - 1] = fine_note_x256;
    if (tone_note_history_count[voice] < TONE_HISTORY_LEN) {
        tone_note_history_count[voice]++;
    }
}

static bool tone_history_indicates_modulation(uint8_t voice, uint8_t current_note) {
    if (tone_note_history_count[voice] < TONE_STABLE_RETRIGGER_FRAMES) {
        return false;
    }

    int32_t center = (int32_t)current_note << 8;
    int32_t sum_delta = 0;
    bool seen_positive = false;
    bool seen_negative = false;

    for (uint8_t i = TONE_HISTORY_LEN - TONE_STABLE_RETRIGGER_FRAMES; i < TONE_HISTORY_LEN; i++) {
        int32_t delta = (int32_t)tone_note_history[voice][i] - center;
        if (delta < -MIDI_VIBRATO_BEND_ONLY_DELTA_X256 ||
            delta >  MIDI_VIBRATO_BEND_ONLY_DELTA_X256) {
            return false;
        }
        if (delta > 0) seen_positive = true;
        if (delta < 0) seen_negative = true;
        sum_delta += delta;
    }

    return (seen_positive && seen_negative) ||
           (sum_delta >= -TONE_CENTER_WINDOW_X256 && sum_delta <= TONE_CENTER_WINDOW_X256);
}

static uint8_t __not_in_flash_func(noise_note_for_divisor)(uint8_t channel, uint16_t divisor) {
    uint8_t band;
    uint8_t voice = noise_voice_index(channel);

    if      (divisor <=  24) band = 0;   // Very high — hi-hat, side stick
    else if (divisor <=  48) band = 1;   // High      — open hi-hat, ride
    else if (divisor <=  80) band = 2;   // Mid-high  — snare, clap
    else if (divisor <= 128) band = 3;   // Mid       — toms
    else if (divisor <= 176) band = 4;   // Low       — bass drum, floor tom
    else                     band = 5;   // Very low  — deep bass drum

    return noise_drum_notes[band][voice];
}
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
int main(void) {
    set_sys_clock_khz(250000, true);

    // Initialize state
    tx_ring_lock = spin_lock_instance(spin_lock_claim_unused(true));
    tx_ring_head = 0;
    tx_ring_tail = 0;
    psg_addr_latch = 0;
    memset((void *)psg_reg, 0, sizeof(psg_reg));
    memset((void *)channel_freq, 0, sizeof(channel_freq));
    memset((void *)midi_note, 0, sizeof(midi_note));
    memset((void *)midi_program, 0xFF, sizeof(midi_program));
    memset((void *)midi_expr, 0, sizeof(midi_expr));
    memset((void *)psg_tone_mix, 0, sizeof(psg_tone_mix));
    memset((void *)psg_noise_mix, 0, sizeof(psg_noise_mix));
    memset((void *)midi_pitchbend_pending, 0, sizeof(midi_pitchbend_pending));
    memset((void *)midi_pitchbend_dirty, 0, sizeof(midi_pitchbend_dirty));
    memset((void *)midi_expr_pending, 0, sizeof(midi_expr_pending));
    memset((void *)midi_expr_dirty, 0, sizeof(midi_expr_dirty));
    memset((void *)midi_pitchbend_last_us, 0, sizeof(midi_pitchbend_last_us));
    memset((void *)midi_expr_last_us, 0, sizeof(midi_expr_last_us));
    memset((void *)tone_last_period, 0, sizeof(tone_last_period));
    memset((void *)env_level, 0, sizeof(env_level));
    memset((void *)tone_note_history, 0, sizeof(tone_note_history));
    memset((void *)tone_note_history_count, 0, sizeof(tone_note_history_count));
    memset((void *)tone_pending_note, 0, sizeof(tone_pending_note));
    memset((void *)tone_pending_count, 0, sizeof(tone_pending_count));
    for (int i = 0; i < MIDI_CH_COUNT; i++)
        midi_pitchbend[i] = 8192;
    soundenv = 0;
    soundenvspeed = 0;
    soundenvspeed_toolarge = 0;
    memset((void *)usesoundenv, 0, sizeof(usesoundenv));
    memset((void *)soundenvcounter, 0, sizeof(soundenvcounter));
    psg_reg_seq = 0;
    all_silent_since_us = 0;
    all_sound_off_sent = 0;

    setup_gpio();
    io_bus_init();

    multicore_launch_core1(core1_entry);

    while (true)
        __wfi();

    return 0;
}

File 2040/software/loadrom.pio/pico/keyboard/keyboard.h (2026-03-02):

// MSX PICOVERSE PROJECT
// (c) 2026 Cristiano Goncalves
// The Retro Hacker
//
// keyboard.h - Pin definitions and constants for MSX PicoVerse USB Keyboard firmware
//
// This work is licensed under a "Creative Commons Attribution-NonCommercial-ShareAlike 4.0 International
// License". https://creativecommons.org/licenses/by-nc-sa/4.0/

#ifndef KEYBOARD_H
#define KEYBOARD_H

// -----------------------------------------------------------------------
// GPIO pin assignments (directly mapped to MSX bus signals)
// -----------------------------------------------------------------------
// Address lines (A0-A15)
#define PIN_A0     0
#define PIN_A1     1
#define PIN_A2     2
#define PIN_A3     3
#define PIN_A4     4
#define PIN_A5     5
#define PIN_A6     6
#define PIN_A7     7
#define PIN_A8     8
#define PIN_A9     9
#define PIN_A10    10
#define PIN_A11    11
#define PIN_A12    12
#define PIN_A13    13
#define PIN_A14    14
#define PIN_A15    15

// Data lines (D0-D7)
#define PIN_D0     16
#define PIN_D1     17
#define PIN_D2     18
#define PIN_D3     19
#define PIN_D4     20
#define PIN_D5     21
#define PIN_D6     22
#define PIN_D7     23

// Control signals
#define PIN_RD     24   // /RD   — active-low read strobe
#define PIN_WR     25   // /WR   — active-low write strobe
#define PIN_IORQ   26   // /IORQ — active-low I/O request
#define PIN_SLTSL  27   // /SLTSL — active-low slot select (unused by keyboard)
#define PIN_WAIT   28   // /WAIT  — active-low, driven by PIO to freeze Z80 during I/O reads
#define PIN_BUSSDIR 29  // BUSSDIR — bus direction control (unused by keyboard)

#define PICO_FLASH_SPI_CLKDIV 2

#endif

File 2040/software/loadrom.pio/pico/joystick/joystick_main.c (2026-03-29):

// MSX PICOVERSE PROJECT
// (c) 2026 Cristiano Goncalves
// The Retro Hacker
//
// joystick_main.c - Standalone USB Joystick → MSX PSG joystick firmware
//
// Turns the PicoVerse 2040 cartridge into a dedicated USB joystick adapter.
// Intercepts MSX I/O ports:
//   0xA0 (OUT) — PSG register address latch
//   0xA1 (OUT) — PSG register data write (R15 bit 6 = port select)
//   0xA2 (IN)  — PSG register data read  (R14 = joystick state)
//
// Architecture:
//   Core 0: PIO1 IRQ handler services I/O bus requests.
//           Tracks the PSG register latch and joystick port selection.
//           For R14 reads, responds with open-drain joystick data
//           (only pulls bits LOW for pressed buttons).
//           For all other register reads, tri-states the bus to let
//           the real PSG chip respond.
//   Core 1: TinyUSB host task processes USB HID gamepad reports and
//           updates the MSX joystick state for up to 2 ports.
//
// This work is licensed under a "Creative Commons Attribution-NonCommercial-
// ShareAlike 4.0 International License".
// https://creativecommons.org/licenses/by-nc-sa/4.0/

#include <string.h>
#include "pico/stdlib.h"
#include "pico/multicore.h"
#include "hardware/clocks.h"
#include "hardware/pio.h"
#include "hardware/irq.h"
#include "hardware/sync.h"
#include "tusb.h"
#include "host/usbh.h"
#include "host/usbh_pvt.h"
#include "joystick.h"
#include "hid_gamepad_parser.h"
#include "xinput_host.h"
#include "msx_joystick.pio.h"

// -----------------------------------------------------------------------
// TinyUSB custom class driver registration — enables XInput support
// -----------------------------------------------------------------------
usbh_class_driver_t const* usbh_app_driver_get_cb(uint8_t *driver_count)
{
    *driver_count = 1;
    return &xinput_class_driver;
}

// -----------------------------------------------------------------------
// Joystick state — two ports, active-low (0xFF = idle)
// Written by Core 1, read by Core 0 (IRQ context)
// Also accessed by xinput_host.c via extern
// -----------------------------------------------------------------------
volatile uint8_t joystick_state[2] = { 0xFF, 0xFF };

// -----------------------------------------------------------------------
// PSG register tracking (updated by Core 0 from write captor)
// -----------------------------------------------------------------------
static volatile uint8_t psg_register_latch;   // Last value written to port 0xA0
static volatile uint8_t joystick_port_sel;    // 0 = port 1, 1 = port 2

// -----------------------------------------------------------------------
// Per-device gamepad context (up to CFG_TUH_HID = 4 HID interfaces)
// -----------------------------------------------------------------------
#define MAX_GAMEPADS 4

typedef struct {
    bool             active;       // Device is mounted and recognised
    uint8_t          dev_addr;     // TinyUSB device address
    uint8_t          instance;     // TinyUSB HID instance
    uint8_t          msx_port;     // Assigned MSX port (0 or 1), 0xFF = none
    gamepad_layout_t layout;       // Parsed HID report descriptor
} gamepad_dev_t;

static gamepad_dev_t gamepads[MAX_GAMEPADS];

// -----------------------------------------------------------------------
// PIO1 context
// -----------------------------------------------------------------------
#define IO_PIO      pio1
#define IO_SM_READ  0
#define IO_SM_WRITE 1

// -----------------------------------------------------------------------
// Build a 16-bit response token for the I/O read PIO:
//   bits[7:0]  = data byte
//   bits[15:8] = pindirs (0xFF = drive all, 0x00 = tri-state all,
//                          partial = open-drain)
// -----------------------------------------------------------------------
static inline uint16_t __not_in_flash_func(build_token)(uint8_t data,
                                                         uint8_t pindirs)
{
    return (uint16_t)(((uint16_t)pindirs << 8) | data);
}

// -----------------------------------------------------------------------
// Build an open-drain token from MSX joystick state byte.
//
// For pressed bits (0): drive LOW  → pindir=1, pin=0
// For idle bits   (1): tri-state   → pindir=0
//
// Only bits 0-5 are joystick signals; bits 6-7 are unused (always high).
// We tri-state all 8 data lines for unused bits so the PSG drives them.
//
// data    = 0x00 (always drive LOW when output is enabled)
// pindirs = bitmask of bits to drive = ~state & 0x3F
// -----------------------------------------------------------------------
static inline uint16_t __not_in_flash_func(build_opendrain_token)(uint8_t joy_state)
{
    uint8_t drive_mask = (~joy_state) & 0x3Fu;  // Only bits 0-5
    return build_token(0x00u, drive_mask);
}

// -----------------------------------------------------------------------
// PIO1 IRQ handler — services I/O reads and writes
// -----------------------------------------------------------------------
static void __not_in_flash_func(joystick_pio1_irq_handler)(void)
{
    // --- Handle I/O writes first (ports 0xA0, 0xA1) ---
    while (!pio_sm_is_rx_fifo_empty(IO_PIO, IO_SM_WRITE))
    {
        uint32_t sample = pio_sm_get(IO_PIO, IO_SM_WRITE);
        uint8_t port = (uint8_t)(sample & 0xFFu);
        uint8_t data = (uint8_t)((sample >> 16) & 0xFFu);

        if (port == PSG_ADDR_PORT)
        {
            // PSG register address latch
            psg_register_latch = data;
        }
        else if (port == PSG_WRITE_PORT)
        {
            // PSG data write — we only care about R15 (port select)
            if (psg_register_latch == PSG_REG_PORTB)
            {
                // Bit 6 selects joystick port: 0 = port 1, 1 = port 2
                joystick_port_sel = (data >> 6) & 0x01u;
            }
        }
    }

    // --- Handle I/O reads (port 0xA2) ---
    // The PIO asserts /WAIT and is stalled on pull — we MUST respond
    // to every read or the Z80 hangs.
    while (!pio_sm_is_rx_fifo_empty(IO_PIO, IO_SM_READ))
    {
        uint16_t addr = (uint16_t)pio_sm_get(IO_PIO, IO_SM_READ);
        uint8_t port = (uint8_t)(addr & 0xFFu);

        if (port == PSG_READ_PORT && psg_register_latch == PSG_REG_PORTA)
        {
            // R14 read — return joystick state using open-drain protocol
            uint8_t sel = joystick_port_sel;  // 0 or 1
            pio_sm_put(IO_PIO, IO_SM_READ,
                       build_opendrain_token(joystick_state[sel]));
        }
        else
        {
            // Not R14 — tri-state the bus entirely so the real PSG answers
            pio_sm_put(IO_PIO, IO_SM_READ, build_token(0xFFu, 0x00u));
        }
    }
}
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

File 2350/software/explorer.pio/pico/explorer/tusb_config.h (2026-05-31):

// MSX PICOVERSE PROJECT
// (c) 2026 Cristiano Goncalves
// The Retro Hacker
//
// tusb_config.h - TinyUSB configuration for Sunrise IDE USB host support
//
// This work is licensed under a "Creative Commons Attribution-NonCommercial-ShareAlike 4.0 International
// License". https://creativecommons.org/licenses/by-nc-sa/4.0/

#ifndef _TUSB_CONFIG_H_
#define _TUSB_CONFIG_H_

#ifdef __cplusplus
 extern "C" {
#endif

//--------------------------------------------------------------------
// COMMON CONFIGURATION
//--------------------------------------------------------------------

#ifndef CFG_TUSB_MCU
  #error CFG_TUSB_MCU must be defined
#endif

#if EXPLORER_USB_STDIO_DEBUG
#define CFG_TUSB_RHPORT0_MODE       OPT_MODE_DEVICE
#else
#define CFG_TUSB_RHPORT0_MODE       OPT_MODE_HOST
#endif

#ifndef CFG_TUSB_OS
#define CFG_TUSB_OS                 OPT_OS_NONE
#endif

#ifndef CFG_TUSB_MEM_SECTION
#define CFG_TUSB_MEM_SECTION
#endif

#ifndef CFG_TUSB_MEM_ALIGN
#define CFG_TUSB_MEM_ALIGN          __attribute__ ((aligned(4)))
#endif

#if EXPLORER_USB_STDIO_DEBUG

//--------------------------------------------------------------------
// DEVICE CONFIGURATION - temporary USB stdio diagnostics
//--------------------------------------------------------------------

#define CFG_TUD_ENDPOINT0_SIZE      64

#define CFG_TUD_CDC                 1
#define CFG_TUD_MSC                 0
#define CFG_TUD_HID                 0
#define CFG_TUD_MIDI                0
#define CFG_TUD_VENDOR              0

#define CFG_TUD_CDC_RX_BUFSIZE      256
#define CFG_TUD_CDC_TX_BUFSIZE      256

#else

//--------------------------------------------------------------------
// HOST CONFIGURATION
//--------------------------------------------------------------------

#define CFG_TUH_ENUMERATION_BUFSIZE 256

#define CFG_TUH_HUB                 1
#define CFG_TUH_CDC                 0
#define CFG_TUH_HID                 0
#define CFG_TUH_MIDI                0
#define CFG_TUH_MSC                 1
#define CFG_TUH_VENDOR              0

#define CFG_TUH_DEVICE_MAX          (CFG_TUH_HUB ? 4 : 1)

#define CFG_TUH_HID_EPIN_BUFSIZE    64
#define CFG_TUH_HID_EPOUT_BUFSIZE   64

#endif

#ifdef __cplusplus
 }
#endif

#endif /* _TUSB_CONFIG_H_ */

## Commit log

2026-03-01 - Both PicoVerse 2040 PIO based LoadROM and MultiROM tools now support Sunrise IDE emulation with Nextor ***(NEW!)*** - Updated PicoVerse 2040 LoadROM and MultiROM with improved mapper RAM capacity (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
2026-03-02 - New standalone **USB Keyboard** firmware for PicoVerse 2040 — turns the cartridge into a dedicated USB-to-MSX keyboard interface via `loadrom.exe -k`. Works with any games/software but with origina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
2026-03-09 - New standalone **MSX-MIDI** firmware for PicoVerse 2040 — turns the cartridge into a standard external MSX-MIDI interface via `loadrom.exe -i`. Bridges MSX-MIDI I/O ports to a USB MIDI device such 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
    [keyboard_main.c, loadrom.c, loadrom.h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]
2026-03-24 * MegaMappers cache implementation. * ASCII16-X fix to support NOP ASTEROIDS. * Documentation update
    [loadrom.c, loadrom.h]
2026-03-24 ASCII16-X: emulate AMD flash byte-program and sector-erase commands
    Some ASCII16-X ROMs (e.g. Neon Horizon) detect the cartridge by writing
    a flash byte-program sequence (AA/55/A0) and verifying the result. The
    mapper handler only processed bank-register writes, so flash command
    writes were silently dropped and detection failed.
    Add a flash_cmd_state_t state machine to the cached ASCII16-X handler
    that tracks AMD unlock sequences and emulates:
    - Byte program (A0h): AND-masks data into the SRAM cache slot
    - Sector erase (80h+30h): fills the cache slot with FFh
    - Reset to read mode (F0h)
    All writes are fed through flash_process_write() before bank-register
    processing. The read path is unchan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
    [loadrom.c, loadrom.h]
2026-03-25 multirom.pio: add LRU bank cache and AMD flash emulation for ASCII16-X/NEO8/NEO16
    Port the mapper-aware LRU bank cache system from loadrom.pio to
    multirom.pio. All three large-ROM mappers now serve reads exclusively
    from SRAM instead of flash XIP, matching loadrom.pio behaviour:
    - ASCII16-X: 12-slot (16KB) LRU cache with AMD flash command emulation
    (byte-program, sector-erase) for cartridge detection and save data
    - NEO8: 24-slot (8KB) LRU cache with cached write handler
    - NEO16: 12-slot (16KB) LRU cache with cached write handler
    The bank cache divides the 192KB SRAM pool into fixed-size slots and
    uses LRU eviction with pinned active pages. Flash is only accessed on
    cache misses during b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
    [menu.h, multirom.c, multirom.h]
2026-03-28 - LoadRom and Multirom v2.55 released - Improved mapper detection accuracy, aligned with openMSX and enhanced via SHA1 database. - Improved cache for mega mappers - Added Manbow2 mapper (Type 14) sup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
    [keyboard.h, loadrom.c, loadrom.h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]
2026-03-29 - PicoVerse 2350 LoadROM v2.50 released!! - Added support for the Sunrise IDE Nextor ROM and Sunrise + Mapper configurations on the PicoVerse 2350, using either the on-board microSD card (`-s1`/`-m1`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
2026-04-10 PicoVerse 2350 Loadrom 2.51 - Redefinition of the main clock to stabilize Core2350B boards with different flash chips - PSRAM 1MB mapper implementation with the Nextor -m1 (microSD) and -m2 (USB-C) o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
    [loadrom.c, loadrom.h, multirom.c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]
2026-04-12 - Fix SCC emulation for 2350 LoadROM and MultiROM #9: reduced the SCC quality-mode internal oversampling rate from clk/2 to clk/8 so Core 1 can keep up with I2S audio buffer demand at the new 210 MHz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
    [PicoVerse_2040_button_pakoto.stl, PicoVerse_2040_side1_pakoto.stl, PicoVerse_2040_side2_pakoto.stl]
2026-04-19 PicoVerse 2350 – LoadROM 2.54
    - New: Unified PSRAM memory manager now handles the full 8MB allocation, coordinating all PSRAM usage across features.
    - New: Added PicoVerse 2350 Nextor modes (-c1 and -c2) with partial Carnivore2 emulation. In these modes, the cartridge identifies itself as a Carnivore2 RAM device to SofaRUN/SofaROM, allowing SROM.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
    - New: SCC and SCC+ support in Nextor modes with Carnivore2 emulation, enabled via -scc and -sccplus together with -c1 or -c2.
    - Docs: Updated documentation covering the new -c1 / -c2 modes, SofaRUN integration, and SCC/SCC+ support wi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
    [PicoVerse_2040_1.41_button.stl, PicoVerse_2040_1.41_label_holder.stl]
2026-04-22 PicoVerse 2350 LoadROM 2.55 - fix: Games were slow when running with Carnivore2 emulation + SCC enabled - We are now using a per-bank decode cache (match mask/value, size mask, base linear offset, RA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
    [loadrom.c, loadrom.h]
2026-04-27 PicoVerse 2350 LoadROM 2.56 - Documentation: New MSX PicoVerse 2350 WiFi Support document and refreshed surrounding pages. - Fix: Corrected PicoVerse branding in the ESP8266 UNAPI BIOS ROM and added 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
    PicoVerse 2350 MultiROM 2.56
    - Feature: New memory manager backing the 1 MB PSRAM memory mapper modes (-m1, -m2).
    - Feature: Partial Carnivore2 emulation combined with the 1 MB PSRAM memory mapper (-c1, -c2) ported from LoadROM, including SCC/SCC+ emulation under Nextor.
    - Feature: WiFi support — embedded ESP8266P-compatible ROM and memio UART bridge o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
    [ESP8266_memio.asm, explorer.h, loadrom.c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]
2026-05-11 2350 Explorer 2.24
    - Added full Explorer menu navigation for F1 - Flash, F2 - Micro SD, F3 - File Hunter, and F4 - Config.
    - Added selected-source highlighting on the footer, with Flash selected by default at boot.
    - Integrated File Hunter directly into the Explorer MSX menu.
    - Added File Hunter list browsing through F3, using the Pico firmware to talk directly to the ESP8266/File Hunter service.
    - Added File Hunter search, pagination, online/offline state, and status messages.
    - Standardized Flash, microSD, and File Hunter list rows to show name, size, source tag (FL, SD, FH), and ROM/folder type.
    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
2026-05-31 ## PicoVerse 2350 Explorer v2.29
    - Bumped Explorer to v2.29.
    - Applied each decoded MP3 frame's sample rate to the I2S output clock so MP3 files encoded at rates other than 44.1 kHz play at the correct pitch and speed.
    - Retuned the existing MP3 I2S producer format in place on sample-rate changes instead of allocating a second audio pool during playback.
    - Expanded Explorer ROM/MP3 record names to the 80-column detail-screen width and only truncate detail-screen names when they exceed the active screen width.
    - Reported a missing microSD card to the MSX menu, display a clear no-card message when switching to the microSD source without a card inserted, and avoid reading stale records while ke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
    [explorer.h, menu.h, mp3.c]
2026-06-02 ## PicoVerse 2040 LoadRom v2.58
    - Bumped the loadrom.pio version to v2.58.
    - Set all loadrom.pio firmware target system clocks to 230 MHz to improve stability with pico boards with bad quality flash memory.
    ## PicoVerse 2040 MultiRom v2.58
    - Bumped the multirom.pio version to v2.58.
    - Set all multirom.pio firmware target system clocks to 230 MHz to improve stability with pico boards with bad quality flash memory.
    ## PicoVerse 2350 Explorer v2.30
    - Bumped Explorer to v2.30.
    - Enabled the primary PSG DAC mirror for Sunrise SYSTEM ROM launches through a reusable SYSTEM audio service, including Sunrise + Mapper modes without stealing mapper I/O or blocking mapper bootstrap.
    - Enabled the Dua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
    [explorer.h]
2026-06-14 ## PicoVerse 2040 Loadrom v2.60
    - Refreshed the generated ROM mapper SHA1 database from the current openMSX `softwaredb.xml` and updated the generator to parse the new attribute-based XML format.
    ## PicoVerse 2040 Multirom v2.60
    - Moved the shared MultiROM version declaration into the aggregate and tool Makefiles, removing the separate `version.mk` include.
    - Refreshed the generated ROM mapper SHA1 database from the current openMSX `softwaredb.xml` and updated the generator to parse the new attribute-based XML format.
    ## PicoVerse 2350 Multirom v2.59
    - Refreshed the generated ROM mapper SHA1 database from the current openMSX `softwaredb.xml` and updated the shared generator to parse the n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
2026-06-17 Release msx-picoverse-20260616
    PicoVerse 2040 Loadrom v2.60
    PicoVerse 2040 Multirom v2.60
    PicoVerse 2350 Loadrom v2.61
    - Fixed Neo-8/Neo-16 ROMs not launching when MSX-MUSIC/FM-PAC (`-f` / `-fmpac`) is enabled (the same ROM booted fine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
2026-06-19 Release msx-picoverse-20260618
    - Updated the public README OPL4 credits to describe the PicoVerse 2350 standalone MoonSound firmware architecture, h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
2026-06-22 Release msx-picoverse-20260621
    PicoVerse 2040 Multirom v2.61
    - Bumped the multirom.pio version to v2.61.
    - Improved MSX MultiROM menu list drawing by rendering each ROM row through a single VRAM block write instead of per-character BIOS output.
    - Fixed the MultiROM tool mapper detector so 8KB ROMs do not read past the ROM buffer when building images with embedded Sunrise/mapper options.
    - Restored selected-row name scrolling so long ROM names advance from the first visible character while using the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
    [menu.h, multirom.c]
2026-06-24 Release msx-picoverse-20260623
    PicoVerse 2350 Loadrom v2.62
    - Bumped the loadrom build version to v2.62.
    - Expanded the standalone OPL4 `OPL4DBG` USB CDC report with timer, read latency, write FIFO/ring-drop, limiter, and clock-mode counters for field captures of missing-instrument issues, while keeping USB CDC disabled by default for normal timing validation. Left enabled by default so we can capture data in case of future reports of missing instruments or other audio issues.
    - Added the OPL4-only `--lowclock` tool option for `-4`/`--opl4` images; default OPL4 UF2s keep the 300 MHz RP2350 clock, while `--lowclock` marks the OPL4 config header so the firmware boots at 282 MHz. This is to co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
    [explorer.h, loadrom.c, menu.h]
2026-06-26 Release msx-picoverse-20260625
    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
2026-06-29 Release msx-picoverse-20260628
    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
    [explorer.h, menu.h]
2026-07-04 Release msx-picoverse-20260704
    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
    [yamanooto.c, yamanooto.h]
2026-07-08 Add PicoVerse 2350 case files and documentation
    - Introduced 3D model files for the PicoVerse 2350 cartridge case, including STL and OBJ formats.
    - Added README.md to provide an overview of the case files and their respective versions.
    - Created a change log (log.md) to document updates and attributions for the case models.
    [Cartouche_MSX_V2_FLAT_PICOVERSE_2350_1.0_A.obj, Cartouche_MSX_V2_FLAT_PICOVERSE_2350_1.0_B.obj, PicoVerse_2350_1.1_Paco_boton 4mm.stl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]
2026-07-15 Release msx-picoverse-20260714
    PicoVerse 2350 Loadrom v2.67
    - Added the OPL4-only `--22khz` tool option for `-4`/`--opl4` images. The build now produces and embeds a second dedicated OPL4 firmware payload compiled for 22050 Hz; that variant advances FM/PCM/ti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
    - Version bumped to v2.67 (top-level and tool Makefiles).
    PicoVerse 2350 Explorer v2.41
    - Bumped Explorer version to v2.41.
    - Changed the per-ROM 50/60Hz INIT stub to call the BIOS `WRTVDP` routine (0x0047) instead of a raw port 0x9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
2026-07-17 Release msx-picoverse-20260716
    PicoVerse 2040 Loadrom v2.61
    - Fixed the PC tool mapper-detection read path to reject truncated ROM reads before hashing or scanning the allocated ROM buffer.
    - Version bumped to v2.61 (top-level and tool Makefiles).
    PicoVerse 2040 Multirom v2.62
    - Fixed the PC tool mapper-detection read path to reject truncated ROM reads before hashing or scanning the allocated ROM buffer.
    - Version bumped to v2.62 (top-level and tool Makefiles).
    PicoVerse 2350 Loadrom v2.68
    - Removed the OPL4-only `--22khz` build option and its alternate 22050 Hz standalone firmware payload after validation showed missing instruments and notes in OPL4 playback. The tool now always packag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
    [loadrom.c, loadrom.h]
2026-07-23 Release msx-picoverse-20260722
    PicoVerse 2350 Explorer v2.42
    - Bumped Explorer version to v2.42.
    - Deleted a ROM's associated `.PVC` options file when the ROM is deleted from microSD, while continuing normally when no options file exists.
    - Stamped FileHunter ROM downloads with the HTTP `Last-Modified` time, falling back to the response `Date`, instead of leaving a null microSD file timestamp.
    - Fixed FileHunter showing `Network: Offline` after successfully loading its online catalog by retaining successful HTTP connectivity when the ESP8266 AP-status query cannot return an SSID.
    - Removed the FileHunter `Network: Online`/`Network: Offline` footer and its redundant Wi-Fi status probes from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
    [explorer.h, menu.h]
